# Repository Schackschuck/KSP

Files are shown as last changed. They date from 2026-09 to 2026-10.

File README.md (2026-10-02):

# KSP Cockpit

Controle físico (painel + joystick + telemetria) para o **Kerbal Space Program 1**, feito do zero com hardware e software próprios.

O objetivo principal é **aprender firmware/embarcados e eletrônica**, e de quebra ter um cockpit de verdade — com direito a um botão que dispara um script de pouso autônomo estilo SpaceX.

---

## Arquitetura

```
 PC com Windows: KSP 1 + servidor kRPC
          ▲
          │  rede — cabo ou Wi-Fi (kRPC, TCP/protobuf)
          ▼
 Raspberry Pi 4 = computador de bordo ............... bridge/
   • ponte kRPC ⇄ placas
   • tela multifunção de 7" no HDMI, a mesma página do celular
   • tela multifunção no navegador do celular, pelo Wi-Fi
   • dispara os scripts de voo ....................... scripts/
          ▲
          │ USB/serial
          │ (protocolo próprio)
          ▼
 Arduino Mega = I/O do painel
 firmware/painel/
          ▲
          │  SPI + linhas analógicas
          ▼
 Backplane: 12 slots ................................ hardware/backplane/
          ▲
          │  um cabo flat de 16 vias por módulo
          ▼
 Módulos do painel, um por seção .......... hardware/modulo_pequeno/, _medio/ e _grande/
   pequeno: 8 entradas + 8 LEDs (1 × 74HC165 + 1 × 74HC595)
   médio: 16 entradas + 24 LEDs (2 × 74HC165 + 3 × 74HC595), com 12 jacks de korry
   grande: 24 entradas + 16 LEDs (3 × 74HC165 + 2 × 74HC595)
   korry, botões, LEDs, sidestick, acelerador

 Barras de LEDs dos recursos: um MAX7219, direto no Mega
```

Cada parte tem um papel bem definido:

| Parte | Responsabilidade | Não faz |
|---|---|---|
| **KSP + kRPC** (PC) | Expõe o estado da nave e aceita comandos. | — |
| **Computador de bordo** (Raspberry Pi 4, Python) | Conecta no kRPC pela rede, abre *streams* de telemetria, traduz eventos do painel em comandos do jogo e telemetria em mensagens para o painel. Desenha a tela de telemetria. Dispara os scripts de voo de `scripts/` (ex.: pouso autônomo). | Não lê pino nenhum. |
| **Sidestick** (joystick JH-D400X-R4 no painel, lido pelo Mega) | Manda os 3 eixos e o botão como qualquer controle do painel; a ponte os traduz em comandos do kRPC. | O KSP não enxerga o joystick: tudo passa pela ponte. |
| **Painel** (Arduino Mega, C++) | Lê entradas (com debounce), envia eventos; recebe valores e atualiza LEDs, displays e ponteiros. | **Não sabe que o KSP existe.** É um painel de I/O genérico. |
| **Celular** (opcional, página no navegador) | Mostra a tela multifunção pelo Wi-Fi, com o mesmo protocolo e o mesmo layout, sem precisar da mikromedia. | Não fala com o kRPC nem guarda estado: só desenha o que a ponte manda. |
| **Tela multifunção** (tela de 7" no HDMI do Pi, com a página do navegador) | Desenha as páginas (navball, órbita, pouso, piloto) com o que a ponte manda, e troca de página pelo toque ou pelos botões do painel. | Não fala com o kRPC; só mostra o que o computador de bordo manda. |

Durante o desenvolvimento, o mesmo código Python roda no PC — só muda o endereço do servidor kRPC e a porta serial.

### Princípios

- **O LED mostra o estado do jogo, não a posição da chave.** A chave só avisa para onde foi ("SAS para cima"); o computador de bordo decide o que fazer e o jogo confirma. Assim o painel nunca fica dessincronizado (ex.: SAS desligado pelo jogo).
- **Uma tela só, no meio do painel: a tela multifunção.** Os módulos não têm tela própria. Cada módulo que precisa mostrar números (editor de manobras, piloto automático, rendezvous...) tem uma página na tela multifunção. Quando o piloto mexe num módulo, a ponte troca a tela para a página dele; uns segundos depois do último toque no módulo (uns 10 s, a ajustar), a tela volta sozinha para a página de antes, em geral a navball.
- **Protocolo serial em duas versões:**
  - **v0 — texto**, uma mensagem por linha. Fácil de depurar no Serial Monitor.
    ```
    Pi → placa:  ALT 12345      SAS 1      FUEL 73
    placa → Pi:  BTN STAGE 1    SW SAS 0   AX PITCH -312
    ```
  - **v1 — binário**, com enquadramento [COBS](https://en.wikipedia.org/wiki/Consistent_Overhead_Byte_Stuffing), ID de mensagem e CRC. Mais rápido e robusto; vem quando a v0 começar a apertar. É o mesmo protocolo para o Mega e para a mikromedia.
- **Entradas analógicas** (joystick, acelerador) são enviadas a uma taxa fixa, com zona morta e filtro; **entradas digitais** são enviadas só quando mudam.

### Decisões

| Decisão | Por quê |
|---|---|
| **kRPC** em vez de mods de serial (Kerbal Simpit etc.) | Acesso a praticamente tudo do jogo (órbita, estágios, delta-v, autopilot) e permite scripts de voo. A ferramenta não deve ser o limite. |
| **Ponte fora do microcontrolador** em vez do cliente kRPC C-nano | kRPC completo com *streams*; o firmware fica simples e ganha um protocolo próprio — que é onde está o aprendizado de embarcados. |
| **Python** na ponte | Já usado com kRPC antes; o mesmo código roda no PC e no Pi. |
| **Raspberry Pi 4** como computador de bordo | Deixa o cockpit independente do PC (só um cabo de rede) e pode ligar uma tela colorida grande. A compra dessa tela foi adiada — decidir depois. |
| **Arduino Mega** para o I/O | O Pi não tem entradas analógicas e o Linux não é tempo real; o Mega tem muitos pinos, trabalha em 5V e é compatível com praticamente todo módulo. |
| **Painel em módulos** com 74HC165 e 74HC595, ligados ao Mega por um backplane | Cada seção do painel é uma placa, montada e testada uma de cada vez. Há três tamanhos (8 entradas e 8 LEDs, 16 e 24, ou 24 e 16), para não montar CI à toa. Cada módulo tem uma etiqueta (chave DIP lida por um 74HC165 a mais), e o Mega reconhece sozinho qual módulo está em cada slot. Os CIs custam poucos reais por módulo, o firmware continua um só e o protocolo com a ponte não muda. Um micro em cada módulo fica para a fase 8. |
| Pinos do Raspberry Pi **não** substituem o Mega | O Pi não tem entradas analógicas, o Linux não é tempo real para encoders e ponteiros, e os pinos de 3,3 V vão direto ao processador: um fio errado nos 5 V queima o Pi. |
| **mikromedia for ARM (LPC2148)** como tela multifunção | Já está na bancada. ARM programado sem framework, com tela touch, microSD e áudio. Começa no protocolo em texto, como o simulador, e passa para o v1 junto com o Mega. |
| **Simulador da tela multifunção** no PC antes do firmware | A ponte, o protocolo e o desenho (navball, números, botões) ficam prontos e testados com o jogo antes da placa; o firmware só precisa copiar o simulador. A placa desenha a partir dos ângulos, porque a imagem pronta não cabe na serial (150 KB por quadro). |
| **Firmware da mikromedia compilado com o LLVM** (clang), e não com o `arm-none-eabi-gcc` | Um compilador só, que já gera código para o ARM7, e um `compilar.py` em Python que roda igual no Windows e no Linux, sem `make`. O `mfd.hex` vai compilado no repositório: para gravar, basta o Flash Magic. |
| **Tela da mikromedia desenhada em faixas de 16 linhas** | Não cabe a tela inteira na RAM (150 KB contra 32 KB), e desenhar direto na tela piscaria. Cada faixa de 10 KB fica pronta na RAM e vai inteira para a tela, então cada ponto é escrito uma vez só. |
| **Orientação e touch da mikromedia ajustados na própria tela** e guardados na flash | O manual não diz a orientação do módulo nem a do touch. Ajustando na tela, o que vier trocado se corrige sem compilar de novo. |
| **Celular como tela**, por uma página web | Funciona já, sem firmware e sem o cabo, em qualquer celular e sem instalar nada. A ponte serve a página e fala com ela por HTTP (Server-Sent Events e POST), só com a biblioteca padrão do Python. O protocolo é o mesmo da placa, então a ponte não muda. |
| **pygame-ce** no lugar do pygame | O pygame original não tem pacote para o Python 3.14; o pygame-ce, mantido pela comunidade, tem e é usado do mesmo jeito (`import pygame`). |
| **Pouso por previsão**: simula a freada até o chão e acha o acelerador por bisseção | Com arrasto, a freada não tem conta fechada. Simular funciona igual em qualquer planeta, com ou sem atmosfera, e refazer a conta 20 vezes por segundo corrige os erros da previsão. O arrasto é medido em voo, e a previsão só usa parte dele, porque ele cai quando a nave fica mais lenta que o som. A guiagem não conhece o kRPC, então é testada numa nave simulada. |
| **Pé da nave medido pelas pernas do trem**, não pela caixa da nave inteira | Nas versões lançadas do kRPC (até a 0.6.0), a caixa de uma peça junta tudo o que está pendurado nela, como a chama do motor ligado. A caixa da nave inteira descia metros abaixo do pé, e a freada terminava alta. |
| **SAS do KSP aponta a nave no pouso**, não o piloto automático do kRPC | O piloto automático do kRPC vem ajustado para levar 3 s até o ângulo pedido e não conta a força do ar. No segundo teste, a nave caindo de ré balançou até 31° na freada. O SAS o jogo ajusta para cada nave. Retrógrado enquanto a nave desce rápido; devagar, perto do chão, o retrógrado pula de um lado para o outro, então no fim o SAS só segura a atitude. |
| **Scripts de voo numa pasta própria** (`scripts/`), fora da ponte | Cada script roda sozinho pela linha de comando, no PC ou no Pi, com ou sem o cockpit. A ponte só dispara o script quando o botão do painel é apertado; o script não depende dela nem do painel. |
| **Script liga segurando o korry 5 s**, e aborta segurando de novo 5 s, sem chave ARM | Um toque sem querer não entrega a nave ao script, e o mesmo gesto aborta, sem procurar outro botão. Economiza a chave ARM com capa e um botão por script. Quem conta o tempo é a ponte, como no encoder do piloto automático, e o korry pisca âmbar enquanto conta. |
| **A ponte abre o script num processo próprio** e aborta com o Ctrl+C | O script continua sendo o mesmo da linha de comando, e o Ctrl+C já corta o motor e devolve a nave. O estado volta pelo UDP, como no fly by wire, e o código de saída diz se a nave pousou. |
| **Um joystick só, no painel** (JH-D400X-R4, um sidestick à direita), com o botão do manche trocando o modo | O cockpit fica como um avião: acelerador na mão esquerda, sidestick na direita. Os 3 eixos cabem nas 3 linhas analógicas de um slot do backplane, e o botão passa pelos modos VOO, CÂMERA e TRANSLAÇÃO, com três luzes. Passando pela ponte, dá para ter zona morta e saber quando o piloto mexe no manche para tirar o controle de um script. O Extreme 3D Pro fica para desenvolver no PC. |
| **Uma tela no meio para todos os módulos**, a tela multifunção de 7", no lugar de um LCD por módulo | Os olhos vão sempre ao mesmo lugar, os painéis ficam menores e só com botões, e sai um LCD por módulo da lista de compras. A página troca sozinha para o módulo em uso e volta depois, então não é preciso escolher a página na mão. Quem decide a troca é a ponte, que já recebe todos os eventos do painel: a tela continua só desenhando. |
| **Korry switches** (botões iluminados com legenda, de avião) onde a luz mostra um estado do jogo | O botão não tem posição, então nunca discorda do jogo: cada toque pede a troca, e a legenda acesa é o estado do jogo. Feitos em casa: a legenda impressa em duas cores encaixa num corpo igual para todos, e a chave e os LEDs vão num suporte impresso atrás, sem placa perfurada ([hardware/korry/](hardware/korry/README.md)). O que não tem estado para mostrar é um botão de 16 mm sem luz. |
| **Cockpit em U, de 766 × 391 mm, com painéis de 125 mm** ([versão B](hardware/construcao.md#cockpit-versão-b)) | Um bloco no meio e duas asas, como num avião, sem painel vazio. Os controles foram juntados em 11 painéis para a caixa não passar de 80 cm; o que não cabe em 125 mm ocupa dois quadrados. O que cada botão faz foi conferido no código-fonte do kRPC antes de desenhar. |
| **Tela de 7" no Pi** no lugar da mikromedia | A tela de 2,8" da mikromedia ficou pequena no meio do cockpit. A de 7" mostra a mesma página que o celular já usa, pelo HDMI, sem firmware novo. O firmware da mikromedia continua no repositório, fora do cockpit. |
| **Caixa em MDF cortado a laser, com peças impressas em 3D** | A laser do colégio faz as peças planas e grandes (paredes, painéis com legendas); a impressora de casa, as pequenas e complicadas (korry, knobs, suportes). Cada seção é um painel removível com o seu módulo atrás. |
| **Fly by wire com a lei de um caça**: o manche pede carga (g) e velocidade de rolagem, e não mexe nas superfícies | A primeira versão movia um ponto na navball, e o avião ia até ele: estável, mas lenta e "interventora" no jogo (o voo gravado mostrou o avião respondendo quase 1 s depois e seguindo o ponto depois de o manche ser solto). Pedindo carga e rolagem, o avião responde na hora, e soltar o manche segura o caminho e a inclinação. O piloto automático pede um caminho, e o FBW calcula a carga e a inclinação para chegar nele. |
| **Ganhos do FBW divididos pela autoridade do avião** (torque disponível ÷ inércia, informados pelo kRPC) | A força das superfícies cresce com o quadrado da velocidade: um ganho fixo, bom na decolagem, faz o avião balançar rápido, e cada avião precisaria do seu. Nos testes, o FBW segura o avião com a autoridade informada errada pela metade ou pelo dobro. |
| **Scripts mandam marcadores à ponte da tela por UDP**, com a própria linha do protocolo da tela | O script continua rodando sozinho: sem a ponte aberta, a linha se perde e nada acontece. A ponte só confere e repassa. |
| **Avisos de voo (GPWS) na ponte da tela, falados no Pi** | A ponte já lê o jogo o tempo todo, então avisa em qualquer avião, com ou sem o fly by wire. A voz sai por um alto-falante USB no Pi, pelo `espeak-ng` ou por gravações; o áudio da mikromedia (VS1053) fica para os alarmes da própria tela. |
| **O `fbw.py` lê o joystick sozinho**, por enquanto | A ponte ainda não lê o joystick. Quando ler, a leitura passa para ela, e o script recebe o manche da ponte. |
| **ESP32** fica para depois | Candidato a painel sem fio ou módulo extra (fase 8). |

### Estrutura planejada do repositório

```
bridge/           computador de bordo em Python: ponte kRPC ⇄ serial, tela de telemetria;
                  tela multifunção: ponte (mfd.py), simulador, navball e a página do celular (celular/);
                  painel de sistemas de controle (sistemas.py), com a página de botões (celular/painel.html);
                  painel de scripts (painel_scripts.py): o korry POUSO abre o scripts/pouso.py;
                  avisos de voo por voz, como o GPWS (avisos.py);
                  editor de nós de manobra com botões na página (manobras.py); testes em bridge/tests/
scripts/          scripts de voo (pouso, fly by wire...), que rodam com ou sem o cockpit; testes em scripts/tests/
firmware/painel/  Arduino Mega (Arduino IDE ou PlatformIO)
firmware/passos/  sketches de aprendizado, um por passo da fase 1
firmware/mfd/     mikromedia for ARM / LPC2148 (C, compilado com o LLVM pelo compilar.py), fora do cockpit
hardware/         esquemáticos e PCBs (KiCad), desenhos da caixa; ver hardware/README.md
                  e hardware/construcao.md (o cockpit da versão B, a caixa e os painéis);
                  cada peça própria numa pasta, com ficha e desenhos (hardware/korry/:
                  modelo no OpenSCAD, STL das legendas, das grades e das peças, gerar.py e o desenho da ligação);
                  identidade visual (hardware/identidade_visual.md) e desenhos dos painéis
                  gerados por código (hardware/desenho/, SVG em hardware/img/)
docs/             protocolo serial, pinagem, anotações
```

---

## Roteiro

Cada fase termina com algo funcionando de ponta a ponta. Não pule o critério de "pronto".

### Fase 0 — Ambiente

**Status: concluída.** Passo a passo detalhado e problemas encontrados em [docs/setup-pi.md](docs/setup-pi.md).

**No PC:**

- Instalar KSP 1.12.x e o **kRPC** (via CKAN ou manualmente).
- No jogo, abrir a janela do kRPC e iniciar o servidor (dica: ativar *auto-start* e *auto-accept* nas configurações).
- Nas configurações do servidor, trocar o endereço de `localhost` para **Any** (aceitar conexões da rede), e liberar no firewall do Windows as portas do kRPC (padrão: 50000 e 50001).
- Marcar a rede do Windows como **Privada**; em rede Pública o Windows bloqueia a conexão do Pi.
- Instalar Python 3, `pip install krpc pyserial` e a Arduino IDE 2 (ou PlatformIO no VS Code).
- Se a placa for clone com chip CH340, instalar o driver CH340 no Windows.

**No Raspberry Pi 4:**

- Gravar o Raspberry Pi OS com o Raspberry Pi Imager, já configurando Wi-Fi e SSH.
- `pip install krpc pyserial pygame` (de preferência dentro de um *venv*).

```python
import time
import krpc

# No PC: krpc.connect(name="KSP Cockpit")
# No Pi: informar o IP do PC onde o KSP está rodando
conn = krpc.connect(name="KSP Cockpit", address="192.168.0.10")
vessel = conn.space_center.active_vessel
altitude = conn.add_stream(getattr, vessel.flight(), "mean_altitude")

while True:
    print(f"{altitude():,.0f} m")
    time.sleep(0.1)
```

Versão completa, que recebe o IP como argumento, espera a cena de voo e explica os erros de conexão: [`bridge/fase0_altitude.py`](bridge/fase0_altitude.py).

**Pronto quando:** o script roda **no Pi** e imprime a altitude ao vivo enquanto o foguete sobe no PC.

### Fase 1 — Primeiro circuito fechado

**Status: concluída**, no PC e no Pi. Roteiro passo a passo, montagem e testes: [docs/fase1.md](docs/fase1.md). Protocolo: [docs/protocolo.md](docs/protocolo.md).

- Mega ligado no PC pela USB durante o desenvolvimento; no fim, no Pi.
- 1 botão (STAGE), 1 LED (SAS) e a altitude num LCD 20x4 com módulo I2C.
- Protocolo **v0 (texto)**.
- Aprende: pull-up, debounce, leitura/escrita serial, laço principal sem `delay()`.

**Pronto quando:** apertar o botão faz *stage*, o LED acompanha o SAS do jogo e o LCD mostra a altitude.

### Fase 2 — Painel de controle

**Status: em andamento.** Chaves, botões e LEDs estão prontos para montar: pinagem, código e testes em [docs/fase2.md](docs/fase2.md). O cockpit inteiro está desenhado: a [versão B](hardware/construcao.md#cockpit-versão-b), em U, com 11 painéis de 125 mm, o sidestick e o acelerador no painel.

- Chaves para SAS, RCS, trem de pouso, luzes e freios; STAGE e ABORT com capa de proteção. Depois, action groups.
- **Painel VOO, de sistemas de controle** ([desenho](hardware/construcao.md#painel-de-sistemas-de-controle)): os 10 modos do SAS em korry de duas cores (azul virando, verde segurando), korry SAS, RCS, FBW e TRAVA ALT, e o encoder do [piloto automático](#piloto-automático-de-avião). Numa placa grande com 4 × 74HC595. Apertar um modo do SAS abre a roda dos modos na tela multifunção, só para ver. Trem de pouso, luzes e freios foram para o painel do acelerador.
- A posição da chave é o estado desejado (para cima = ligado); o LED de cada sistema mostra o estado no jogo.
- **Painel em módulos:** cada seção vira uma placa, ligada por cabo flat a um backplane de 12 slots no Mega. A placa pequena tem 8 entradas e 8 LEDs (1 × 74HC165 + 1 × 74HC595); a média, 16 e 24 (2 + 3), com um jack JST-XH para cada korry; a grande, 24 e 32 (3 + 4). Os LEDs só mostram o que vem do jogo: nenhum é ligado a um botão. Cada módulo tem uma etiqueta numa chave DIP, e o Mega descobre sozinho o que está encaixado. Esquemáticos, etiquetas e qual placa vai em cada seção em [hardware/](hardware/README.md).
- Enquanto o primeiro módulo não fica pronto, os controles básicos continuam direto nos pinos do Mega, como em [docs/fase2.md](docs/fase2.md).
- Próximo passo: o firmware do Mega lendo a fila de módulos pelas etiquetas, e testar o primeiro módulo direto no Mega.
- **Sidestick e acelerador no painel:** um joystick JH-D400X-R4 de 3 eixos, com o botão do manche trocando entre VOO, CÂMERA e TRANSLAÇÃO, e uma alavanca deslizante de 60 mm, os dois lidos pelo Mega nas linhas analógicas do backplane ([sidestick](hardware/construcao.md#sidestick), [acelerador](hardware/construcao.md#acelerador)). O Extreme 3D Pro fica para desenvolver no PC; mapeamento em [hardware/construcao.md](hardware/construcao.md#joystick-logitech-extreme-3d-pro).
- **Korry switches:** botões iluminados com legenda, como nos aviões, 35 no cockpit. Legenda impressa em duas cores na FlashForge Inventor, encaixada num corpo igual para todos, com a chave e os LEDs num suporte impresso. As bases de cada grupo saem numa grade impressa, parafusada atrás do painel. O modelo, os STL das 31 legendas, das grades e das peças, o `gerar.py` e a ligação estão em [hardware/korry/](hardware/korry/README.md); o primeiro passo é o teste de folga e um korry ligado direto no Mega.

**A fazer na ponte, para a versão B** (o que cada controle faz e o comando do kRPC estão em [hardware/construcao.md](hardware/construcao.md#os-painéis)):

- [ ] Definir no [protocolo](docs/protocolo.md) as mensagens dos painéis novos: tempo, navegação, action groups e peças, câmera, recursos e EVA, acelerador, sidestick e os botões de página da tela.
- [ ] Tempo: WARP, PARAR, FISICO, ATE O NO, PAUSA, SALVAR, CARREGAR e REVERTER.
- [ ] Navegação: escolher e limpar o alvo pelo encoder, com a página ALVO na tela; REFERENCIA; trocar de nave.
- [ ] Action groups 1 a 8 e os korry das peças (paraquedas, painéis solares, antenas, compartimento de carga), com a luz do estado.
- [ ] Câmera: MAPA, IVA, MODO CAM, FOTO e ESCONDER.
- [ ] Acelerador pela alavanca; TREM, FREIOS e LUZES em korry.
- [ ] Sidestick: os 3 eixos pelo Mega, e o botão trocando o modo, com as luzes.
- [ ] Barras de recursos pelo MAX7219, no firmware do Mega.
- [ ] EVA, quando houver o kRPC 0.7: andar e voar pelo manche, JATO, LUZ, SAIR, EMBARCAR, AGARRAR e SOLTAR.
- [ ] Páginas novas na tela: ORBITA, DELTA-V, SUBIDA, ALVO, TEMPO e EVA.

**Pronto quando:** dá para lançar e colocar um foguete em órbita usando só o painel.

### Fase 3 — Tela de telemetria

- Interface em pygame no Pi: altitude, velocidades, apoapse/periapse, tempo até Ap/Pe, combustível e delta-v por estágio.
- Depois: gráfico de altitude × tempo, desenho simples da órbita, indicador de atitude.
- O Pi 4 tem folga de desempenho, mas vale o bom hábito: redesenhar só o que mudou e limitar a taxa de quadros.
- A tela do cockpit é a de 7" (Waveshare 7" HDMI LCD (C)), no meio do painel. Enquanto ela não chega, desenvolver com qualquer monitor ou TV HDMI (ou rodando a interface no PC).
- A tela multifunção ([docs/mfd.md](docs/mfd.md)) já mostra navball, velocidades, altitude e Ap/Pe numa página web. Uma tela HDMI com touch no Pi pode abri-la em tela cheia, no navegador, sem programar nada novo.

**Pronto quando:** dá para circularizar uma órbita olhando só para a tela.

### Fase 4 — Instrumentos físicos

**Status: editor de manobras escrito, com botões numa página no lugar das chaves; falta testar no jogo.** [`bridge/manobras.py`](bridge/manobras.py) cria e edita os nós pelo kRPC e mostra os números do nó e da órbita (antes e depois) no navegador do PC ou do celular: [docs/manobras.md](docs/manobras.md). A página manda linhas do protocolo pela rede; o painel vai mandar as suas pela serial, com o encoder no lugar dos pares `+`/`-` do Δv. Por enquanto a página também gira a câmera do mapa, **o que tem que sair dela:** no cockpit, a câmera do mapa vai ser mexida pelo joystick, no modo CÂMERA.

**A fazer no editor, para ficar igual ao painel desenhado** ([desenho](hardware/construcao.md#painel-do-editor-de-manobras), [mensagens](docs/protocolo.md#no-painel)):

- [ ] Ponte (`bridge/manobras.py`): guardar o eixo escolhido (PRO, NRM ou RAD), começando pelo PRO em cada nó novo, e trocar de eixo com `BTN PRO`, `BTN NRM` e `BTN RAD`.
- [ ] Ponte: aceitar `ENC DV <cliques>` (horário positivo) e aplicar os cliques × passo no eixo escolhido.
- [ ] Ponte: aceitar `SW PASSO <0 a 3>`, o passo pela posição da chave rotativa, no lugar do `BTN PASSO`.
- [ ] Ponte: mandar ao painel qual eixo está escolhido, para acender o korry certo.
- [ ] Página do celular (`bridge/celular/manobras.html`): trocar os pares `PRO -`/`PRO +`, `NRM -`/`NRM +` e `RAD -`/`RAD +` por três botões de eixo e um par `-`/`+` que faz o papel do encoder, com o eixo escolhido destacado.
- [ ] Testes (`bridge/tests/test_manobras.py`) para o eixo escolhido, o `ENC DV` e o `SW PASSO`.
- [ ] Atualizar [docs/manobras.md](docs/manobras.md) e tirar o "planejado" da seção [No painel](docs/protocolo.md#no-painel) do protocolo.

- Displays de 7 segmentos com MAX7219 para os números mais importantes.
- Encoder rotativo para escolher o que cada display mostra. Lido pela mesma cadeia de 74HC165 dos módulos: o Mega lê a cadeia inteira mil vezes por segundo numa **interrupção de timer**, e assim o redesenho do LCD (~20 ms) não faz perder cliques. O painel acumula os cliques e manda `ENC <nome> <cliques>`.
- **Editor de nós de manobra** (pelo kRPC: `control.add_node`, `node.prograde` etc.):
  - Painel duplo de 250 × 125 mm, desenho e peças em [hardware/construcao.md](hardware/construcao.md#painel-do-editor-de-manobras).
  - **Δv por um encoder só**, porque os três eixos nunca são mexidos ao mesmo tempo. Três korry (PRO, NRM e RAD) escolhem o eixo, e a legenda do escolhido acende na cor da alça do nó no KSP. Girar no sentido horário soma o passo; no anti-horário, tira. Um nó novo já vem com o PRO escolhido. O painel manda `ENC DV <cliques>`, e quem sabe o eixo escolhido é a ponte.
  - **PERCURSO:** uma tecla basculante com mola para o centro, como a do TIME WARP, montada deitada, move o nó ao longo da órbita (para a esquerda, antes; para a direita, depois). Segurando, repete; o painel manda `INC TEMPO <passos>`. Embaixo dela, ANT e PROX trocam de nó.
  - **PASSO:** chave rotativa de 4 posições, com a legenda gravada em volta: 0,1 / 1 / 10 / 100 m/s no Δv e 1 s / 10 s / 1 min / 10 min no tempo.
  - Korry NOVO (nó novo no apoastro), APAGAR e CIRC (circulariza no ponto do nó, com o Δv calculado pela ponte). Sem AP e PE: o tempo já leva o nó a qualquer ponto.
  - São 16 entradas e 3 LEDs (os korry de eixo): cabe numa placa média.
  - **Sem tela no módulo:** Δv, tempo de queima, T− até o nó e o Ap/Pe resultante aparecem numa página do editor na tela multifunção, que abre sozinha quando uma tecla ou botão do editor é usado (ver os [princípios](#princípios)).
  - O botão MAPA (liga e desliga o mapa do jogo) fica na seção da câmera. A câmera do mapa (girar, aproximar, trocar o foco entre nave, nó e planeta) fica no joystick, no modo CÂMERA, não no editor.
- Barras de 10 LEDs com o que resta de combustível, oxidante, monopropelente e eletricidade, acesas por um MAX7219 ([recursos e EVA](hardware/construcao.md#recursos-e-eva)).
- Ponteiro analógico com motor de passo X27.168.
- Fonte 5V externa (a USB não aguenta muitos LEDs).

**Pronto quando:** um voo inteiro (lançamento → órbita → reentrada) é feito sem olhar para o monitor do PC, inclusive planejar a circularização pelo editor de manobras.

### Fase 5 — Protocolo v1 + scripts de voo

**Status: script de pouso escrito, em teste no jogo; o korry POUSO já dispara o script pela página de botões.** No primeiro teste, em Kerbin, a freada terminou alta e a nave tocou o chão inclinada e tombou. Corrigido: o pé agora é medido pelas pernas do trem. No segundo teste o pé ficou certo (0,4 m de erro no toque), mas a nave balançou até 31° na freada: o piloto automático do kRPC não segurava a nave. Agora quem aponta a nave é o SAS do KSP (falta testar de novo). [`scripts/pouso.py`](scripts/pouso.py) faz a queima de suicídio numa descida vertical, em qualquer planeta, contando o arrasto do ar; roda pela linha de comando ou pelo korry POUSO do [painel de scripts](hardware/construcao.md#painel-de-scripts), e a tela multifunção mostra o pouso numa página própria ([docs/mfd.md](docs/mfd.md#painel-de-scripts-e-a-página-do-pouso)). [`scripts/tests/test_pouso.py`](scripts/tests/test_pouso.py) testa a mesma guiagem numa nave simulada, sem o KSP, em planetas com e sem atmosfera.

- Migrar para o protocolo binário (COBS + CRC).
- **Painel de scripts** ([desenho](hardware/construcao.md#painel-de-scripts)): um korry por script, em faixas na ordem do voo (SUBIDA, ORBITA, DESCIDA). Por enquanto só o POUSO; os outros cinco lugares ficam vagos, com a tampa lisa. Segurar o korry 5 s abre o script; segurar de novo 5 s aborta. O korry pisca âmbar enquanto conta, fica verde com o script voando e vermelho se ele foi abortado ou falhou.
- Korry "EXEC" (um lugar vago do painel de scripts) que executa o nó de manobra da fase 4: aponta a nave para o nó, acelera o tempo até perto dele, queima e corta quando o Δv restante chega a zero.
- Painel e tela mostram o estado do script (armando, voando, pousado, abortado). A página POUSO da tela, inspirada na tela do booster da SpaceX, mostra a nave descendo até o alvo, a fase, a altura, a descida, o empuxo/peso e quanto do empuxo a freada precisa. O pouso e o EXEC seguem a [base comum dos scripts](#base-comum).

**A fazer no painel de scripts:**

- [x] Ponte (`bridge/painel_scripts.py`): segurar `BTN POUSO` 5 s abre o `scripts/pouso.py` num processo; segurar de novo aborta; a linha `SCR POUSO` acende o korry.
- [x] `scripts/pouso.py`: estado por UDP (linhas `POU`), código de saída e `--demo` com uma nave simulada.
- [x] Página POUSO no simulador e no celular; korry POUSO na página de botões (`bridge/celular/painel.html`).
- [ ] Testar no jogo: o korry abre o pouso, a página acompanha, e segurar de novo aborta com o motor cortado.
- [ ] Firmware do Mega: o korry POUSO no módulo da ação executiva, mandando `BTN POUSO 1` e `0`, e o LED de duas cores pela linha `SCR POUSO`.
- Os outros scripts (piloto automático de avião, subida até a órbita, pouso de precisão...) estão em [Scripts de voo](#scripts-de-voo) e não entram no critério desta fase.

**Pronto quando:** um booster pousa sozinho a partir de um botão no painel, e um nó de manobra é executado pelo botão EXEC.

### Fase 6 — Tela multifunção (mikromedia for ARM)

**Fora do cockpit:** na [versão B](hardware/construcao.md#tela-multifunção), a tela multifunção é uma tela de 7" no HDMI do Pi, mostrando a página que já existe para o celular. A tela de 2,8" da mikromedia ficou pequena no meio do painel. O firmware e a documentação dela continuam aqui, como o projeto de embarcados que foram.

Placa da MikroElektronika com **NXP LPC2148** (ARM7TDMI-S, 60 MHz, 512 KB de flash, 32 KB de RAM), tela 320x240 com touch resistivo, microSD, saída de áudio e carregador de Li-Po. Aqui o firmware é escrito **sem framework**: C, registradores, script de linker e código de inicialização próprios.

**Status: firmware pronto, falta rodar na placa.** O firmware em `firmware/mfd/` faz na placa o que o simulador faz no PC: navball, números, botões de toque e as páginas SAS, AP e POUSO, no protocolo em texto. Ele compila sem avisos e foi conferido no PC contra o simulador. Gravar e ligar: [docs/mikromedia.md](docs/mikromedia.md). A tela também roda no simulador do PC e no navegador do celular: [docs/mfd.md](docs/mfd.md).

- **Placa:** duas mini-USB. A **USB** vai direto no LPC2148, e a **PROG** tem um conversor USB-serial **FT232RL**, por onde o PC conversa com a placa e o Flash Magic grava o firmware. A tela é um módulo MI0283QT2 (320x240, barramento de 16 bits), com touch resistivo lido pelo ADC. Pinos em [docs/mikromedia.md](docs/mikromedia.md#como-o-firmware-funciona).
- **Ferramentas:** LLVM (clang, ld.lld e llvm-objcopy), chamado pelo `firmware/mfd/compilar.py`; o `mfd.hex` já vem compilado. Gravação pelo bootloader serial de fábrica do LPC2148, pela PROG, com o Flash Magic.
- **Passos:**
  1. [x] Código de inicialização, script de linker, PLL a 60 MHz.
  2. [x] Serial com interrupção e o protocolo da tela ([docs/protocolo.md](docs/protocolo.md#tela-multifunção-mikromedia)), em texto como o simulador; mais tarde o v1.
  3. [x] Driver da tela (HX8347) e desenho em faixas de 16 linhas, porque não cabe um *framebuffer* (320×240×2 = 150 KB contra 32 KB de RAM).
  4. [x] Touch pelo ADC, com a orientação e a calibração escolhidas na própria tela e guardadas na flash.
  5. [x] Páginas: navball, roda do SAS, piloto automático e pouso. Depois: mapa da órbita, informações e uma página para cada módulo do painel que precisa de números (a começar pelo editor de nós de manobra).
  6. [ ] Rodar na placa: confirmar o controlador da tela, o touch e a velocidade.
  7. [ ] Áudio: alarme de estol e avisos gravados no microSD (combustível baixo, contagem de altitude no pouso), pelo VS1053.

**Pronto quando:** a mikromedia mostra telemetria ao vivo recebida do Pi e toca um alarme de combustível baixo.

### Fase 7 — Hardware definitivo

- PCB no **KiCad** a partir dos esquemáticos de [hardware/](hardware/README.md): uma placa de módulo, fabricada em quantidade, e o backplane. Fabricação na JLCPCB, PCBWay… A do módulo médio já está pronta, com os Gerbers ([hardware/](hardware/README.md#pcb-do-módulo-médio)).
- Caixa em MDF cortado a laser (no colégio), com peças impressas em 3D (em casa): um painel removível por seção, legendas gravadas, korry switches, o Pi e a tela de 7" embutidos. Formato, aparência e ordem para construir em [hardware/construcao.md](hardware/construcao.md).

### Fase 8 — Embarcados avançado (opcional)

- Painéis modulares, cada um com seu micro, falando com um mestre via I2C, RS-485 ou CAN.
- Painel sem fio com **ESP32**.
- Reescrever o firmware do Mega sem o framework Arduino (registradores do AVR) ou migrar para RP2040 (Raspberry Pi Pico) com o C SDK ou Rust + Embassy.

---

## Scripts de voo

Scripts que pilotam a nave, ou ajudam o piloto a pilotar, disparados pelo painel e acompanhados na tela. O primeiro é o pouso autônomo da [fase 5](#fase-5--protocolo-v1--scripts-de-voo) ([`scripts/pouso.py`](scripts/pouso.py)); o segundo, o [fly by wire de avião](#fly-by-wire-de-avião) ([`scripts/fbw.py`](scripts/fbw.py)). Os outros desta seção são ideias ainda sem código e sem ordem: cada um entra no roteiro quando o hardware de que precisa existir.

Os scripts ficam em [`scripts/`](scripts/), fora da ponte: cada um roda sozinho pela linha de comando, no PC ou no Pi, mesmo sem o painel. No cockpit, a ponte só dispara o script pelo botão e mostra o estado dele no painel e na tela. Os testes, com naves simuladas e sem o KSP, ficam em `scripts/tests/`.

### Base comum

- **Um script ativo por vez.** No cockpit, liga segurando o korry do script 5 s, e segurar de novo 5 s aborta. ABORT, ou mexer no joystick, também devolve o controle ao piloto na hora (a fazer).
- O painel e a tela mostram o estado do script (armado, ativo, terminado, abortado). Como nos outros LEDs, o LED mostra o que o script está fazendo, não o botão que foi apertado.
- **Guiagem separada do kRPC**, como em `pouso.py`: recebe uma leitura da nave e devolve comandos. Assim ela é testada numa nave simulada, sem o KSP, antes de ir para o jogo.
- **Diretor de voo:** todo script pode rodar no automático ou só como guia. No modo guia, a tela mostra para onde apontar e quanto acelerar, e o piloto voa pelo joystick. Serve para testar a guiagem sem entregar a nave e para aprender a pilotar junto.

### Fly by wire de avião

**Status: script escrito e testado num avião simulado; falta testar no jogo.** Roteiro de testes, ajuste dos ganhos e problemas comuns em [docs/fbw.md](docs/fbw.md).

Como nos caças, o manche não mexe nas superfícies: ele pede o que o avião deve fazer, e o FBW decide as superfícies. [`scripts/fbw.py`](scripts/fbw.py) lê o joystick (o Extreme 3D Pro, ou um controle de Xbox) e pilota o avião pelo kRPC.

- **O manche:** para trás e para a frente pede carga, de −1 g a 4 g; solto, 1 g, e o caminho não curva. Para os lados pede velocidade de rolagem, até 90°/s; solto, a inclinação fica onde parou. A torção soma ao leme. O FBW não trava a altitude sozinho: numa curva, o piloto puxa.
- **Proteções:** com o manche, só a carga até 4 g: puxando tudo devagar, o avião estola. No piloto automático e na trava, ângulo de ataque entre −8° e 15°, asas até 60° e subida entre −30° e +30°.
- **Aviso de estol:** com o ângulo de ataque perto dos 15°, a luz ESTOL do painel pisca e a tela toca um alarme. É só aviso: o FBW não mexe no acelerador, no piloto automático, na trava nem no manche.
- **Nada liga sozinho:** os modos do piloto automático e a trava só ligam pelo painel.
- **Lei direta** no chão e com o botão do FBW desligado: o manche vai direto para as superfícies. O FBW assume 1 s depois da decolagem.
- **Sem joystick** (`--sem-joystick`): decola pelo teclado do jogo, na lei direta, e no ar o piloto automático voa pelo painel.
- **O acelerador fica com o piloto.** O acelerador automático (SPD) já existe por dentro, ainda sem interface.
- **Na tela:** com o piloto automático ou a trava, o caminho pedido aparece na navball da [tela multifunção](docs/mfd.md), como os quatro cantos verdes de um quadrado. Com o avião nele, o pró-grado fica dentro do quadrado.
- **Por dentro, duas camadas:** a carga e a rolagem pedidas viram velocidades de giro; os giros viram superfícies, com proporcional e integral e o ganho dividido pela autoridade do avião.

**Pronto quando:** um avião decola na lei direta e, com o FBW, responde ao manche na hora, sem balançar: puxar dá carga, rolar dá rolagem, e soltar segura o que estava.

**Anotado depois dos primeiros voos no jogo** (a fazer):

- [x] **O FBW está muito instável no jogo.** O voo gravado mostrou o nariz oscilando a 1,5 vez por segundo (ganho de pitch alto para o atraso do kRPC) e um avião lento e "interventor". Refeito com a lei de caça e ganhos menores, testados com a leitura atrasada ([docs/fbw.md](docs/fbw.md)). Falta confirmar no jogo.
- [ ] **Não ligar o FBW sozinho na decolagem.** Hoje ele assume 1 s depois de sair do chão; passa a começar desligado e só liga pelo korry FBW (ou pelo botão do joystick).
- [x] **Tirar a recuperação automática do estol**, que só deu problema no jogo. Saiu tudo: o acelerador no máximo, o piloto automático e a trava desligando, o nariz para baixo, a trava ligando sozinha depois e o limite de ângulo de ataque no manche. Fica só o aviso (luz ESTOL e alarme).
- [x] **Os modos do piloto automático ligavam sozinhos** ao ligar o FBW (o avião tentava subir para uma altitude): era a trava de altitude automática, que saiu. Falta confirmar no jogo.
- [ ] **Avisar o estol também fora do FBW** (na lei direta): a luz ESTOL e o alarme pelo ângulo de ataque, mesmo sem o FBW voando.

### Avisos de voo (GPWS)

**Status: código escrito e testado sem o jogo; falta ouvir no Pi e voar.** Roteiro, limites e como ligar o alto-falante em [docs/avisos.md](docs/avisos.md).

Como o GPWS dos aviões de linha, a ponte da tela fala os avisos em inglês, num alto-falante USB ligado no Pi, em qualquer nave voando na atmosfera:

- **Vermelhos:** `PULL UP` (descendo rápido demais para a altura) e `TERRAIN` (o chão chegando rápido; vira `PULL UP` se continuar).
- **Âmbar:** `SINK RATE`, `DON'T SINK` (perdendo altura depois da decolagem), `TOO LOW, GEAR` e `TOO LOW, TERRAIN` (baixo com o trem recolhido), `BANK ANGLE` e `OVERSPEED`.
- **Chamadas de altura** no pouso: 100, 50, 40, 30, 20 e 10 pés.
- **Luz** GPWS (âmbar) / PULL UP (vermelha) no painel de sistemas; por enquanto, na página de botões.

- [x] `bridge/avisos.py`: os avisos, a prioridade e a voz (`espeak-ng` ou gravações em `bridge/sons/`); `--voz`, `--sem-voz` e `--testar-voz` no `mfd.py`; testes.
- [x] Luz GPWS / PULL UP na página de botões.
- [ ] Ouvir no Pi com o alto-falante USB e ajustar os limites no jogo.
- [ ] Luz GPWS no desenho do painel de sistemas.
- [ ] Olhar o terreno à frente (EGPWS), pela altura do terreno do kRPC.

### Piloto automático de avião

**Status: código escrito e testado com o avião simulado e a demonstração; falta testar no jogo.** O `fbw.py` voa HDG, ALT e V/S pedindo um caminho ao FBW ([docs/fbw.md](docs/fbw.md#piloto-automático)), e o painel de sistemas é, por enquanto, uma página de botões aberta pela ponte da tela ([docs/mfd.md](docs/mfd.md#painel-de-sistemas-de-controle)), com a roda do SAS e a página do piloto na tela.

- [x] Página de botões no celular, no lugar do painel, como a do editor de manobras.
- [x] Ponte da tela (`bridge/mfd.py` e `bridge/sistemas.py`): modos do SAS, SAS e RCS no jogo; azul ou verde pelo erro até o marcador; o menu do piloto; as páginas do SAS e do piloto, com a volta à navball.
- [x] Tela do celular e simulador: a roda dos modos do SAS e a página do piloto.
- [x] `scripts/fbw.py`: HDG, ALT e V/S pedindo um caminho; FBW e TRAVA pelo painel; estado e comandos por UDP com a ponte da tela; testes no avião simulado.
- [ ] Testar no jogo: os modos do SAS e as luzes ([roteiro](docs/mfd.md#testar-o-painel-sem-o-ksp)), e o piloto automático num avião ([roteiro](docs/fbw.md#piloto-automático)).
- [ ] **Tela: tirar os botões redondos SAS e RCS da navball.** Eles ficam só no painel.
- [ ] **Tela: as páginas que abrem sozinhas** (a roda do SAS, a do piloto e as outras que aparecem por cima da navball) **ficam 6 s** depois do último toque, em vez de 10 s.
- [ ] O painel de verdade: as mesmas linhas pela serial do Mega, e as pontes do painel e da tela juntas.

Inspirado no painel de piloto automático dos aviões de linha (o MCP do Boeing, o FCU do Airbus).

- **Modos:**
  - **HDG:** vira para o rumo escolhido e segura.
  - **ALT:** sobe ou desce até a altitude escolhida e segura. Enquanto não chega, fica **armado** (azul na tela); ao chegar, nivela e fica verde.
  - **V/S:** sobe ou desce com a velocidade vertical escolhida. Com o ALT ligado junto, nivela ao chegar na altitude escolhida.
  - **SPD:** acelerador automático, segura a velocidade escolhida. Fica para depois, como mais uma linha do menu.
  - Sem HDG ligado, a rolagem fica com o manche, e a inclinação fica onde o piloto deixou.
- **No painel de [sistemas de controle](hardware/construcao.md#painel-de-sistemas-de-controle)**, junto do SAS, do RCS e do FBW:
  - **Um encoder só**, mexido pelo menu da página do piloto na tela multifunção: girar move o cursor entre HDG, ALT e V/S; apertar escolhe a linha, e girar muda o valor (horário soma); apertar de novo sai; segurar 1 s liga ou desliga o modo da linha. Girando devagar, o valor muda de 1 em 1 (1°, 10 m, 0,1 m/s); rápido, de 10 em 10.
  - **Uma luz verde por modo**, ao lado do encoder, acesa quando o modo está ligado no FBW. Sem displays de 7 segmentos: os valores ficam na tela.
  - Korry **FBW** (liga e desliga o FBW, como o botão do joystick) e **TRAVA ALT** (trava e destrava a altitude do momento).
- **Na tela:** a página do piloto, com os modos (azul armado, verde ligado) e os valores escolhidos, abre sozinha quando o encoder é mexido e volta para a navball uns 10 s depois. O caminho pedido aparece na navball: é o ponto verde do FBW.
- **Por dentro:** o piloto automático fica por cima do [fly by wire](#fly-by-wire-de-avião) e pede um caminho, como um piloto que não cansa:
  - HDG pede o rumo escolhido, que vira inclinação das asas; sem HDG, a rolagem fica com o manche;
  - ALT, V/S e a TRAVA ALT pedem o ângulo de subida, que vira carga; sem eles, o pitch fica com o manche;
  - SPD liga o acelerador automático que já existe no `fbw.py`;
  - as proteções do FBW continuam valendo, e mexer no manche devolve o eixo ao piloto.
- **Precisa de:** o encoder e as luzes do painel de sistemas. Para começar, uma página de botões no celular faz o papel do painel.

**Pronto quando:** um avião decola na mão, e o piloto automático leva ele até a altitude e o rumo escolhidos no painel e segura lá.

### Rover com controle de cruzeiro

- Os mesmos botões e encoders HDG e SPD do avião, e o mesmo PID: segura a velocidade e o rumo no chão, pelo acelerador e pela direção das rodas (`control.wheel_throttle` e `control.wheel_steering`).
- Freia nas descidas, para não passar da velocidade escolhida.
- Sai quase de graça depois do piloto automático de avião.

### Subida até a órbita

- O piloto escolhe a altitude da órbita e a inclinação nos encoders e segura o korry LANCAR (vago no painel de scripts) 5 s.
- O script decola, faz a curva de gravidade, solta os estágios quando o combustível acaba e corta o motor quando o apoastro chega na altitude escolhida.
- No apoastro, circulariza com um nó de manobra executado pelo EXEC da fase 5.
- Junto com o pouso, fecha o ciclo: do chão até a órbita e de volta.

### Pouso de precisão (volta à base)

O pouso da SpaceX completo. O `pouso.py` desce na vertical onde a nave estiver; aqui o booster volta para um lugar escolhido, como a plataforma do KSC.

- **Queima de retorno** logo depois da separação: vira a nave e queima até a trajetória cair no alvo.
- **Queima de reentrada**, para chegar mais devagar nas camadas grossas da atmosfera.
- Na descida, as aletas corrigem a trajetória para o alvo.
- Termina com a queima de suicídio do `pouso.py`, com a mira puxando para o alvo em vez de só anular a deriva.
- É o mais difícil da lista: precisa prever onde a trajetória cai, com arrasto, como o `pouso.py` já faz na vertical.

### Rendezvous

Levar a nave até perto de outra em órbita. O script **não pilota até a última etapa**: ele cria nós de manobra, que o piloto confere e ajusta no editor da [fase 4](#fase-4--instrumentos-físicos) e o EXEC da fase 5 executa. Assim a parte de planejar e a parte de queimar ficam separadas, e cada uma é testada sozinha.

- **As etapas**, cada uma um nó novo:
  1. **Igualar o plano:** nó no nodo ascendente ou descendente em relação ao alvo, queima na direção normal de Δv = 2·v·sen(Δi/2). Conta fechada; o kRPC dá a inclinação relativa e onde fica o nodo (`relative_inclination`, `true_anomaly_at_an`).
  2. **Transferência:** a conta pesada, feita como no pouso, prevendo e ajustando. Para cada momento de queima ao longo de uma volta, calcula a queima pró-grado que leva o apoastro até a órbita do alvo, prevê as duas órbitas e mede a menor distância entre as naves. Fica com o melhor momento e refina por bisseção. Sem motor, as órbitas seguem as leis de Kepler: a previsão é exata, sem o arrasto que complica o pouso.
  3. **Igualar a velocidade:** nó no momento da menor distância, com a queima igual à diferença entre a velocidade do alvo e a da nave nesse instante.
  4. **Aproximação final**, sem nó: aponta para o alvo, se aproxima com uma velocidade que cai com a distância, anula a deriva para os lados e para a uns 50–100 m. Dali segue o acoplamento assistido.
- **Automático ou diretor de voo:** no automático, o script encadeia as etapas e acelera o tempo entre elas (`warp_to`). Como diretor de voo, ele só propõe cada nó e o piloto ajusta e executa.
- **Na página do editor de manobras, na tela multifunção:** a menor distância prevista até o alvo, quando ela acontece e a velocidade relativa nesse ponto, atualizadas enquanto o encoder e o TEMPO mexem no nó.
- **Ordem para fazer**, do mais simples ao mais difícil:
  1. Só mostrar a menor distância prevista enquanto o piloto edita os nós na mão. Sem automação, e já é como se faz rendezvous "de olho" no KSP.
  2. Os nós de igualar o plano e igualar a velocidade, que são contas fechadas.
  3. A busca da transferência.
  4. A aproximação final e a passagem para o acoplamento.
- **A decidir:**
  - Quem prevê as órbitas: o kRPC calcula a aproximação com um nó criado, mas cada pergunta vai pela rede, e a busca faz dezenas delas. Uma previsão própria (resolver a equação de Kepler, umas 30 linhas) é rápida e testável sem o KSP. A ideia é a própria, conferida contra a do kRPC.
  - Queimas longas: o EXEC tem que começar metade da queima antes do nó, senão o encontro erra por quilômetros. Vale para todo nó, então fica no EXEC.
- **Precisa de:** o editor de manobras (fase 4) e o EXEC (fase 5). A etapa 1 da ordem só precisa da tela.

### Acoplamento assistido

- Página nova na tela multifunção: a mira de alinhamento com a porta de acoplamento do alvo, a distância e a velocidade de aproximação.
- O sidestick no modo TRANSLAÇÃO, escolhido pelo botão do manche: o manche move a nave com o RCS, sem girar ([os três modos](hardware/construcao.md#um-joystick-três-modos)).
- Primeiro manual, com a tela ajudando. Depois automático: a nave se alinha e se aproxima devagar sozinha.
- **Precisa de:** joystick (fase 2) e a tela multifunção.

---

## Lista de compras

Itens marcados já estão na bancada. Compre por fase — não precisa tudo de uma vez. AliExpress costuma ser mais barato (e lento); Mercado Livre e lojas nacionais chegam mais rápido.

> **Atenção à tensão:** o Mega trabalha em 5V; o Pi, em 3,3V. Nunca ligue um pino do Pi direto em 5V — a comunicação entre os dois é pela USB.

### Ferramentas (uma vez só)

- [ ] Ferro de solda com controle de temperatura + estanho + malha dessoldadora
- [ ] Multímetro
- [ ] Alicate de corte e decapador de fios
- [x] Impressora 3D (em casa)
- Corte a laser: no colégio
- [ ] Paquímetro (para medir as peças antes de desenhar os furos dos painéis)

### Fases 0–1 — Kit inicial

- [x] Arduino Mega 2560 (também tem Uno e Nano)
- [x] Raspberry Pi 4
- [x] Botões
- [ ] Fonte para o Pi 4: 5,1V 3A USB-C de boa qualidade (fonte fraca causa travamentos)
- [ ] Dissipador ou case com ventoinha (o Pi 4 esquenta, principalmente dentro de uma caixa fechada)
- [x] Cartão microSD de 16 GB ou mais (classe A1)
- [x] Cabo USB-B para ligar o Mega no Pi
- [x] 2× protoboard de 830 pontos
- [x] Jumpers macho-macho e macho-fêmea
- [x] Kit de LEDs 5 mm + kit de resistores (220 Ω–10 kΩ)
- [x] LCD 16x2 ou 20x4 com módulo I2C (só para a fase 1; opcional se já tiver)

### Fase 2 — Painel de controle

- [x] 10–15× chaves alavanca (toggle) ON-OFF
- [x] 2–3× capas de proteção para chave ("missile switch cover")
- [x] 4–6× botões arcade (24 ou 30 mm), de preferência com LED
- [ ] Por módulo pequeno (5 no painel): 2× 74HC165, 1× 74HC595, 2× rede resistiva 10 kΩ SIP 9 pinos, 1× chave DIP de 8 vias, 8× resistor 1 kΩ, 3× capacitor 100 nF, 1× capacitor 10 µF, 3 soquetes DIP-16, conector IDC 2x8 e cabo flat de 16 vias
- [ ] Por módulo médio (5 no painel): 3× 74HC165, 3× 74HC595, 3× rede resistiva 10 kΩ SIP 9 pinos, 1× chave DIP de 8 vias, 24× resistor 220 Ω, 6× capacitor 100 nF, 1× capacitor 470 µF, 12× conector JST-XH de 4 vias, 6 soquetes DIP-16, conector IDC 2x8 e cabo flat de 16 vias
- [ ] Por módulo grande (1 no painel, o VOO): 4× 74HC165, 4× 74HC595, 4× rede resistiva 10 kΩ SIP 9 pinos, 1× chave DIP de 8 vias, 32× resistor 1 kΩ, 8× capacitor 100 nF, 1× capacitor 10 µF, 8 soquetes DIP-16, conector IDC 2x8 e cabo flat de 16 vias
- [ ] Backplane: 12× conector IDC 2x8, 5× resistor 47 Ω, 13× resistor 10 kΩ, capacitores de 470 µF e 100 nF, borne de 2 vias e jumper de 3 pinos
- [x] Joystick: Logitech Extreme 3D Pro (para desenvolver no PC)
- [ ] Sidestick: 1× joystick JH-D400X-R4, 10 kΩ, 3 eixos com botão
- [ ] Acelerador: 1× potenciômetro deslizante Bourns PTA6043, 10 kΩ linear, curso de 60 mm
- [ ] 35 korry switches ([lista completa](hardware/korry/README.md#lista-de-peças-um-korry)), cada um com 1 chave PSW 8,5 × 8,5 mm sem trava, até 2 LEDs difusos de alto brilho de 3 mm, 4 fios finos e 1 conector JST-XH fêmea de 4 vias com os terminais; filamento PLA preto e transparente
- [ ] 10× LED azul e verde de 3 mm, difuso, catodo comum (korry dos modos do SAS)
- [ ] 17× parafuso M3 autoatarraxante de 8 mm, para as 9 grades dos korry ([fixação no painel](hardware/korry/README.md#fixação-no-painel))
- [ ] 34× botão de 16 mm sem trava, com anel de 20 mm (R16-503 ou R13-507), e 2 capas impressas para o CARREGAR e o REVERTER
- [ ] 2× botão de metal de 22 mm com anel de LED (vermelho e branco), de 5 V ou 3 V, e 2× capa transparente para botão de 22 mm
- [ ] 2× tecla KCD1 (ON)-OFF-(ON) de 21 × 15 mm
- [ ] 5× barra de 10 LEDs verde (Kingbright DC-10GWA) e 1× MAX7219, para os recursos e a EVA
- [ ] 7× LED de 5 mm difuso (3 verdes e 1 vermelho do piloto, 3 brancos do sidestick)
- [x] 7× suporte de plástico com porca para LED de 5 mm
- [ ] Placas perfuradas de dupla face + barras de pinos (headers) e fio fino encapado (wire-wrap)

### Fase 3 — Tela de telemetria

- [ ] Tela Waveshare 7" HDMI LCD (C), 1024 × 600, com toque capacitivo: a tela multifunção do cockpit
- [ ] Cabo ou adaptador **micro-HDMI → HDMI** (o Pi 4 só tem saída micro-HDMI)

### Fase 4 — Instrumentos físicos

- [ ] 3–4× módulos MAX7219 com 8 dígitos de 7 segmentos (o piloto automático não usa mais: os valores vão para a tela)
- [ ] 2× encoders rotativos (KY-040), para escolher o que os displays mostram
- [ ] Editor de manobras ([peças e medidas](hardware/construcao.md#painel-do-editor-de-manobras)): 1× encoder EC11 com knob de alumínio de 30 mm; 1× chave rotativa de 1 polo e 12 posições, com anel de batente, e knob de ponteiro de 22 mm (a tecla, os botões e os korry estão na fase 2)
- [ ] Navegação: 1× encoder EC11 com botão e knob de alumínio de 30 mm; 1× chave rotativa de 1 polo e 12 posições, com anel de batente, e knob de ponteiro de 22 mm
- [ ] VOO, de sistemas de controle ([peças e medidas](hardware/construcao.md#painel-de-sistemas-de-controle)): 1× encoder EC11 com botão e knob de alumínio de 30 mm (os korry e os LEDs estão na fase 2); 1 módulo grande
- [ ] 2–4× motores de passo X27.168 (ponteiros)
- [ ] 1× fonte 5V 3A + conector/borne

### Fase 6 — Tela multifunção

- [x] mikromedia for ARM (LPC2148)
- [x] Cabo mini-USB **com fios de dados**, para a PROG (o antigo alimenta a placa, mas o Windows não reconhece o FT232)
- [ ] Cartão microSD (para os sons de alarme)
- [ ] Fone ou caixinha de som com plugue P2
- [ ] Alto-falante USB para o Pi (a voz dos [avisos de voo](docs/avisos.md))
- [ ] Gravador JTAG compatível com ARM7 (opcional, só para depurar passo a passo)

### Fase 7 — Hardware definitivo

- [ ] PCBs fabricadas
- [ ] Conectores JST/dupont, parafusos e espaçadores M3
- [ ] Material da caixa: MDF 3 mm e acrílico 3 mm (preto ou branco leitoso) para a laser, filamento PLA, primer e tinta spray fosca
- [ ] Insertos roscados M3 (colocados a quente nas peças impressas) e pés de borracha
- [ ] Extensão USB de painel (para o joystick) e ventoinha 5 V de 40 mm (para o Pi dentro da caixa)

---

## Referências

- [kRPC — repositório](https://github.com/krpc/krpc) e [documentação](https://krpc.github.io/krpc/)
- [pySerial](https://pyserial.readthedocs.io/)
- [pygame](https://www.pygame.org/docs/)
- [Raspberry Pi — documentação](https://www.raspberrypi.com/documentation/)
- [Arduino — documentação](https://docs.arduino.cc/)
- [KiCad](https://www.kicad.org/)
- [LPC214x User Manual (UM10139)](https://www.nxp.com/docs/en/user-guide/UM10139.pdf) — referência de todos os registradores do LPC2148
- [LLVM](https://llvm.org/) (clang e ld.lld), que compila o firmware da mikromedia
- [Flash Magic](https://www.flashmagictool.com/) — gravação pelo bootloader serial do LPC2148
- Manual e esquemático da mikromedia for ARM (MIKROE-780): site da [MikroElektronika](https://www.mikroe.com/)
- Bibliotecas úteis para o firmware: `LiquidCrystal_I2C`, `LedControl` (MAX7219), `FastLED` ou `Adafruit_NeoPixel` (WS2812), `SwitecX25` (X27.168)

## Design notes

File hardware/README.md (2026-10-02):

# Hardware

Esquemáticos do painel, feitos no KiCad. Cada pasta tem também um PDF do esquema, que dá para ver sem instalar nada.

| Pasta | Placa | CIs |
|---|---|---|
| [`modulo_pequeno/`](modulo_pequeno/) | Módulo pequeno: 8 entradas e 8 LEDs ([PDF](modulo_pequeno/modulo_pequeno.pdf)) | etiqueta + 1 × 74HC165, 1 × 74HC595 |
| [`modulo_medio/`](modulo_medio/) | Módulo médio: 16 entradas e 24 LEDs, com 12 jacks de korry ([PDF](modulo_medio/modulo_medio.pdf), [PCB](#pcb-do-módulo-médio)) | etiqueta + 2 × 74HC165, 3 × 74HC595 |
| [`modulo_grande/`](modulo_grande/) | Módulo grande: 24 entradas e 32 LEDs ([PDF](modulo_grande/modulo_grande.pdf)) | etiqueta + 3 × 74HC165, 4 × 74HC595 (o esquema ainda tem 2: ver [Próximos passos](#próximos-passos)) |
| [`backplane/`](backplane/) | Backplane: liga até 12 módulos ao Mega ([PDF](backplane/backplane.pdf)) | — |

A parte física (carcaça, aparência, os painéis da versão B e o sidestick) está em [construcao.md](construcao.md). Peças feitas em casa e usadas em vários painéis têm pasta própria, com a ficha e os desenhos: [`korry/`](korry/README.md). A [identidade visual](identidade_visual.md) diz como todo painel tem que parecer, e os desenhos dos painéis são gerados por código em [`desenho/`](desenho/README.md).

As três placas de módulo usam o mesmo cabo flat e encaixam em qualquer slot. Cada uma tem uma **etiqueta**, um 74HC165 a mais ligado a uma chave DIP de 8 vias: é por ela que o Mega descobre sozinho qual módulo está em cada slot.

## Como abrir

1. Instale o KiCad 7 ou mais novo e abra o `.kicad_pro` de cada pasta.
2. Os arquivos estão no formato do KiCad 7. Uma versão mais nova avisa que vai converter o arquivo ao salvar: pode aceitar.
3. Os símbolos estão embutidos no esquema. As footprints já estão escolhidas (DIP-16 com soquete, IDC 2x8, chave DIP, barras de pinos). O módulo médio já tem a PCB pronta para fabricar ([abaixo](#pcb-do-módulo-médio)); as outras placas ficam para a fase 7.
4. Ao abrir, rode o verificador de regras elétricas: menu **Inspecionar → Verificador de Regras Elétricas (ERC)**.

## Como tudo se liga

```
Mega ──(7 fios)── Backplane ── slot 1 ──(cabo flat)── módulo
                            ├─ slot 2 ──(cabo flat)── módulo
                            └─ ... até o slot 12
```

- **O Mega nunca liga direto nos módulos,** só no backplane: 5 sinais, +5V e GND.
- **Os pinos do Mega não aumentam com o número de módulos.** Os sinais seguem de módulo em módulo, numa fila.
- **As entradas de todos os módulos formam uma única cadeia de 74HC165,** que termina no MISO do Mega.
- **As saídas formam uma única cadeia de 74HC595,** que começa no MOSI.
- **Só os módulos com joystick ou acelerador** precisam de mais fios até o Mega: 3 analógicos por slot.

### Cabo flat (IDC 2x8, igual no módulo e no slot)

| Pino | Sinal | Pino | Sinal |
|---|---|---|---|
| 1 | +5V | 2 | GND |
| 3 | SCK | 4 | GND |
| 5 | PL (carrega as entradas) | 6 | RCLK (atualiza os LEDs) |
| 7 | SIN165 (vem do slot seguinte) | 8 | SOUT165 (vai para o Mega) |
| 9 | SIN595 (vem do Mega) | 10 | SOUT595 (vai para o slot seguinte) |
| 11 | AN_A | 12 | GND |
| 13 | AN_B | 14 | AN_C |
| 15 | +5V | 16 | GND |

### Ligação ao Mega

| Sinal | Pino do Mega | Observação |
|---|---|---|
| SCK | D52 | SPI |
| MOSI | D51 | Entra na cadeia de 74HC595 |
| MISO | D50 | Sai da cadeia de 74HC165 |
| PL | D49 | |
| RCLK | D48 | |
| Analógicos dos slots 1 a 5 | A0 a A14 | Slot k: A(3k−3), A(3k−2), A(3k−1) |
| 5V | 5V | Só com JP1 em 1-2 |
| GND | GND | Sempre ligado, mesmo com fonte externa |

Não use o D53 (SS) como entrada: se ele for a 0, o SPI do Mega sai do modo mestre. O `SPI.begin()` já o deixa como saída.

### Regras do backplane

1. **Módulos em slots seguidos,** a partir do slot 1, sem buracos. O Mega para de ler no primeiro slot vazio.
2. **A ordem dos módulos não importa:** cada um se identifica pela etiqueta.
3. **Módulos com joystick ou acelerador vão nos slots 1 a 5,** os únicos com linhas analógicas.
4. **JP1 escolhe de onde vem o +5V dos módulos:**
   - **1-2:** 5 V do Mega. Serve para poucos módulos, com o Mega alimentado pela USB.
   - **2-3:** fonte externa de 5 V no borne J3. É para o painel completo.
   - Use um jumper só: ele liga 1-2 ou 2-3, nunca as duas fontes juntas.
5. **Encaixe e tire módulos com o painel desligado.** O conector do cabo flat não garante que o GND encosta antes dos sinais. Ao ligar, o Mega reconhece sozinho o que estiver encaixado.

## Primeiro teste: um módulo direto no Mega

Dá para testar um módulo antes de montar o backplane, ligando o conector J1 do módulo direto no Mega com 8 jumpers:

| J1 do módulo | Mega |
|---|---|
| 1 (+5V) | 5V |
| 2 (GND) | GND |
| 3 (SCK) | D52 |
| 5 (PL) | D49 |
| 6 (RCLK) | D48 |
| 8 (SOUT165) | D50 (MISO) |
| 9 (SIN595) | D51 (MOSI) |
| 7 (SIN165) | GND: marca o fim da fila, como faria um slot vazio |

Os pinos 4, 12 e 16 são GND repetidos, e 15 é +5V repetido: com um cabo curto não precisam de fio. O 10 (SOUT595) fica solto. Os analógicos (11, 13 e 14) vão em A0, A1 e A2, se o módulo tiver joystick.

## Etiqueta: como o Mega reconhece cada módulo

A etiqueta é o primeiro byte que o Mega lê de cada módulo.

**O byte da etiqueta:**
- Cada chave DIP ligada (ON) põe o bit correspondente em 1. A chave k é o bit k−1.
- O Mega inverte o byte lido, porque a chave liga a entrada ao GND.
- **Bits 7 e 6 = tamanho da placa:** 01 pequena, 10 média, 11 grande. É por eles que o Mega sabe quantos bytes vêm depois.
- **Bits 5 a 0 = número da seção:** de 1 a 62, e diz qual módulo é.

**Valores reservados:**
- **Tudo ligado (byte 0xFF depois de inverter):** é o que o Mega lê num slot vazio, graças aos pull-downs do backplane. Quer dizer "acabou a fila".
- **Tudo desligado (0x00):** etiqueta esquecida; o Mega avisa em vez de adivinhar.

**Como o Mega lê a fila:**
1. Lê a etiqueta do slot 1.
2. Pelo tamanho, sabe quantos bytes de entrada pular: 1, 2 ou 3.
3. Lê a etiqueta do slot 2, e assim por diante, até achar a marca de fim.

Assim, não existe tabela de slots no firmware. O Mega avisa a ponte qual módulo está em cada slot, e a ponte sabe o que cada entrada e cada LED daquele módulo faz no jogo.

### Qual placa e qual etiqueta em cada seção

| Seção do painel | Entradas | LEDs | Placa | Número | Chaves DIP em ON |
|---|---|---|---|---|---|
| [Ação executiva](construcao.md#ação-executiva) (STAGE, ABORT e os 6 scripts) | 8 | 14 | média | 1 | 1, 8 |
| [Tempo](construcao.md#tempo) | 9 | 1 | média | 2 | 2, 8 |
| [Sidestick](construcao.md#sidestick) (3 eixos analógicos) | 1 | 3 | pequena, slots 1 a 5 | 3 | 1, 2, 7 |
| [Tela multifunção](construcao.md#tela-multifunção) (páginas e SILENCIAR) | 5 | 0 | pequena | 4 | 3, 7 |
| [Acelerador](construcao.md#acelerador) (alavanca analógica, trem, freios e luzes) | 3 | 3 | pequena, slots 1 a 5 | 5 | 1, 3, 7 |
| [Recursos e EVA](construcao.md#recursos-e-eva) | 6 | 2 | pequena | 6 | 2, 3, 7 |
| [Voo](construcao.md#painel-de-sistemas-de-controle) (sistemas de controle: SAS, RCS, FBW e piloto automático) | 17 | 31 | grande | 7 | 1, 2, 3, 7, 8 |
| [Action groups](construcao.md#action-groups) (1 a 8 e as peças) | 12 | 4 | média | 8 | 4, 8 |
| [Câmera](construcao.md#câmera) | 5 | 2 | pequena | 9 | 1, 4, 7 |
| [Navegação](construcao.md#navegação) | 10 | 0 | média | 10 | 2, 4, 8 |
| [Editor de manobras](construcao.md#painel-do-editor-de-manobras) | 16 | 3 | média | 12 | 3, 4, 8 |

São 11 módulos da [versão B do cockpit](construcao.md#cockpit-versão-b): 5 pequenos, 5 médios e 1 grande, e sobra 1 slot. O sidestick e o acelerador vão nos slots 1 a 5, os únicos com linhas analógicas: o sidestick usa as três (X, Y e torção), o acelerador uma. As 4 barras de recursos e a da EVA (50 LEDs) não passam pelo backplane: um MAX7219 ligado direto em 3 pinos do Mega acende todas. As seções da mesma placa podem ficar longe uma da outra no painel: os fios dos botões até a placa podem ter uns 30 cm.

Os números 3, 4, 6, 9 e 11 mudaram de seção com a versão B: antes eram os analógicos de rotação e translação, a telemetria, a EVA e a câmera. O firmware ainda não lê as etiquetas, então nada no código muda.

## No módulo

| O que liga | Pequeno | Médio | Grande | Como |
|---|---|---|---|---|
| Etiqueta | SW1 | SW1 | SW1 | Chave DIP de 8 vias, conforme a tabela acima. |
| Botões e chaves | J2 (IN0–IN7) | K1–K12 (IN0–IN11) e J2 (IN12–IN15) | J2, J3, J4 (IN0–IN23) | Entre o INn e o GND do próprio conector. Apertado ou ligado lê **0** (pull-up de 10 kΩ). |
| LEDs | J3 (LED0–LED7) | K1–K12 (LED0–LED23) | J5, J6 (LED0–LED15) e, quando o esquema tiver os 4 × 74HC595, mais dois conectores (LED16–LED31) | Anodo no LEDn, catodo no GND. O resistor já está na placa. Na pequena e na grande é de 1 kΩ: uns 3 mA por LED, e os 8 LEDs de um 74HC595 ficam abaixo de 70 mA. Na média é de 220 Ω, que acende mais forte: uns 13 mA por LED, e os 8 de um 74HC595 acesos juntos passam dos 70 mA do CI. |
| Joystick ou acelerador | J4 | J6 | J7 | Pontas do potenciômetro em +5V e GND, cursor em AN_A, AN_B ou AN_C. |

**Os LEDs mostram o estado do jogo.** Nenhum LED é ligado a um botão: o Mega acende cada LED com o que a ponte manda do kRPC. Até o LED de um botão iluminado vai numa saída LEDn, separado do contato do botão.

**Botão com LED de 5 V** (como os botões arcade) já tem resistor interno. Com o resistor da placa em série, ele fica mais fraco. Se ficar fraco demais, troque o resistor daquela saída por um de menor valor, ou por um fio.

## Ordem dos bytes (para o firmware)

| Placa | Bytes de entrada, na ordem de leitura | Bytes de saída |
|---|---|---|
| Pequena | 2: U1 (etiqueta), U2 (IN0–IN7) | 1: U3 (LED0–LED7) |
| Média | 3: U1 (etiqueta), U2 (IN0–IN7), U3 (IN8–IN15) | 3: U4 (LED0–LED7), U5 (LED8–LED15), U6 (LED16–LED23) |
| Grande | 4: U1 (etiqueta), U2 (IN0–IN7), U3 (IN8–IN15), U4 (IN16–IN23) | 4: U5 (LED0–LED7), U6 (LED8–LED15), U7 (LED16–LED23), U8 (LED24–LED31) |

**Entradas:**
1. Um pulso baixo em PL copia todas as entradas, e as etiquetas, para os 74HC165.
2. Em seguida, o SPI lê os bytes a começar pelo slot 1. Em cada byte de entrada, o bit n é o INn do respectivo CI.

**Saídas:**
1. O SPI envia os bytes de saída **do último slot para o primeiro**, e em cada slot do último CI para o primeiro. O último byte enviado fica no primeiro 74HC595 do slot 1.
2. Um pulso em RCLK acende o que foi enviado.

**Uma varredura em uma transferência só:**
- Como as duas cadeias compartilham o SCK, dá para ler e escrever junto.
- Cada placa tem pelo menos tantos bytes de entrada quanto de saída. Então, depois de conhecer os módulos na partida, basta transferir o total de bytes de entrada, com os bytes de saída no fim.
- Com as 12 placas da tabela, são 31 bytes: uns 125 µs a 2 MHz.
- Feito mil vezes por segundo numa interrupção de timer, dá tempo de ler até os encoders.
- Um byte a mais no fim confere a marca de fim da fila.

## Lista de peças por placa

**Módulo pequeno:**
- U1 (etiqueta) e U2: 74HC165.
- U3: 74HC595.
- RN1–RN2: rede resistiva 10 kΩ SIP 9 pinos.
- SW1: chave DIP de 8 vias.
- R1–R8: 1 kΩ.
- C1–C3: 100 nF.
- C4: 10 µF.
- J1: conector IDC 2x8 macho com trava.
- J2–J3: barra de pinos 1x10.
- J4: barra de pinos 1x5.
- 3 soquetes DIP-16.

**Módulo médio:**
- U1 (etiqueta), U2 e U3: 74HC165.
- U4–U6: 74HC595.
- RN1–RN3: rede resistiva 10 kΩ SIP 9 pinos.
- SW1: chave DIP de 8 vias.
- R1–R24: 220 Ω, 1/4 W.
- C1–C5 e C7: 100 nF.
- C6: 470 µF eletrolítico, de 10 V ou mais e até 10 mm de diâmetro.
- J1: conector IDC 2x8 macho com trava.
- K1–K12: conector JST-XH de 4 vias, macho de placa, vertical (B4B-XH-A).
- J2 e J6: barra de pinos 1x5.
- 6 soquetes DIP-16.

**Módulo grande:**
- U1 (etiqueta) a U4: 74HC165.
- U5–U8: 74HC595 (o esquema ainda tem só U5 e U6).
- RN1–RN4: rede resistiva 10 kΩ SIP 9 pinos.
- SW1: chave DIP de 8 vias.
- R1–R32: 1 kΩ.
- C1–C8: 100 nF.
- C9: 10 µF.
- J1: conector IDC 2x8 macho com trava.
- J2–J6: barra de pinos 1x10.
- J7: barra de pinos 1x5.
- 8 soquetes DIP-16.

**Backplane:**
- J1: barra de pinos 1x7.
- J2: barra de pinos 1x16.
- J3: borne de 2 vias.
- JP1: barra de pinos 1x3 com jumper.
- J10–J21: conector IDC 2x8 macho.
- R1–R5: 47 Ω.
- R10–R22: 10 kΩ.
- C1: 470 µF.
- C2: 100 nF.

## PCB do módulo médio

A placa do módulo médio está desenhada e pronta para mandar fabricar. Ela tem um jack para cada [korry](korry/README.md), com o botão e os dois LEDs, e uma barra (J2) com as 4 entradas que sobram, para botões comuns.

| Jack | Pino 1 | Pino 2 | Pino 3 | Pino 4 |
|---|---|---|---|---|
| Kk (k de 1 a 12) | GND | IN(k−1): botão | LED(2k−2): LED de cima | LED(2k−1): LED de baixo |

Por exemplo, o K1 usa IN0, LED0 e LED1, e o K12 usa IN11, LED22 e LED23. Um korry de legenda única acesa usa só o pino 3.

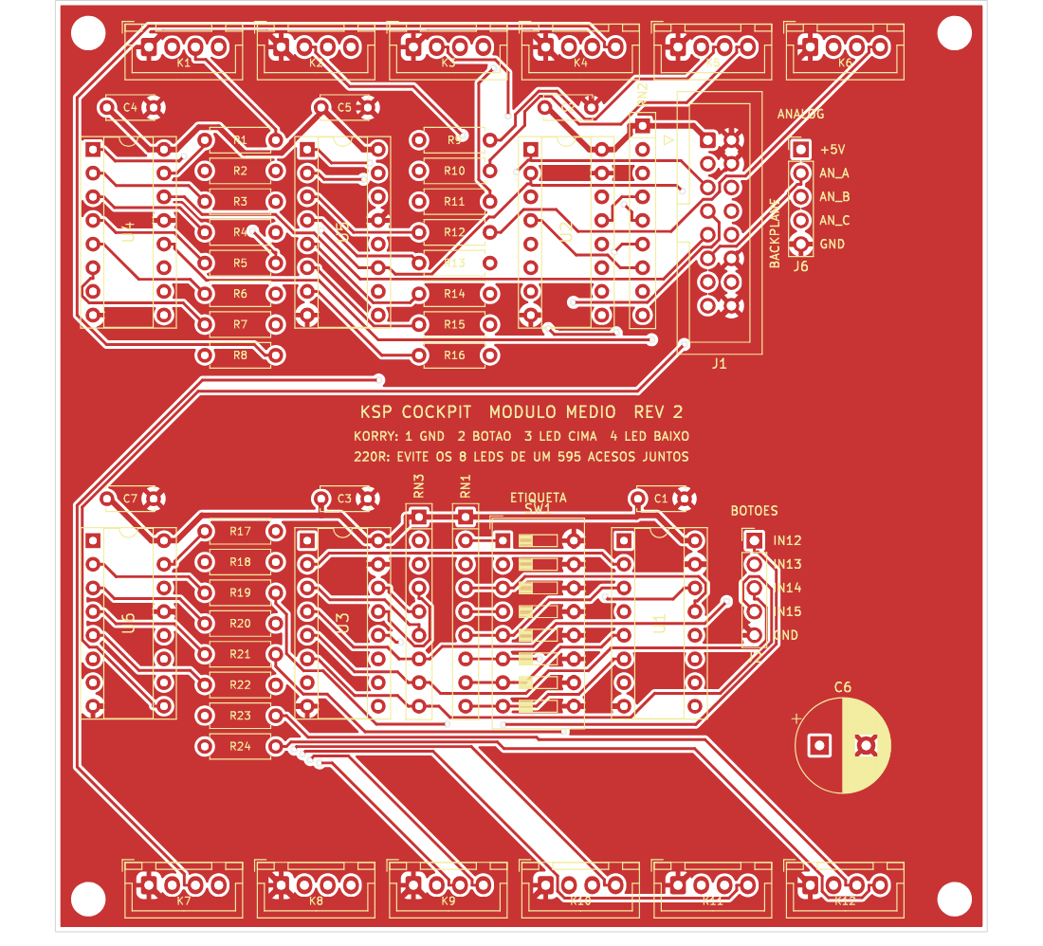
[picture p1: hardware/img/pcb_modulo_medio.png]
Frente da PCB do módulo médio


| O quê | Como é |
|---|---|
| Tamanho | 100 × 100 mm, com 4 furos M3 nos cantos (centro a 3,5 mm das bordas), para prender atrás do painel com espaçadores |
| Camadas | 2, com o GND preenchido nas duas faces |
| Trilhas | 0,3 mm nos sinais e 0,6 mm no +5V e no GND |
| Peças | As da [lista acima](#lista-de-peças-por-placa), todas de furo passante |
| Korry | 12 jacks JST-XH de 4 vias, K1 a K6 na borda de cima e K7 a K12 na de baixo |
| Verificação | DRC do KiCad sem nenhum erro e sem nenhuma ligação faltando |

Os arquivos ficam em [`modulo_medio/`](modulo_medio/): a placa (`modulo_medio.kicad_pcb`), as regras do DRC (`modulo_medio.kicad_dru`) e, em `fabricacao/`, o `modulo_medio_gerbers.zip` com os Gerbers e a furação.

### Como encomendar

1. No site da fábrica (JLCPCB, PCBWay ou outra), enviar o `fabricacao/modulo_medio_gerbers.zip`. O site lê o tamanho sozinho.
2. Escolher 2 camadas, espessura de 1,6 mm e acabamento HASL. A cor não importa. A quantidade mínima costuma ser 5 placas, e as 6 médias do painel cabem em 10.
3. O resto pode ficar no padrão.

### Na hora de montar

- A face de cima tem os nomes das peças, a ordem dos pinos dos jacks (`1 GND  2 BOTAO  3 LED CIMA  4 LED BAIXO`) e os pinos das barras J2 e J6.
- Os pinos 1 têm ilha quadrada. No J1, o pino 1 também tem um triângulo, e ele é o +5V.
- Nas redes RN1 a RN3, o pino comum (marcado com um ponto na peça) vai na ilha quadrada, que é o +5V.
- Os soquetes vão com o chanfro para cima, do lado do pino 1.
- O C6 tem polaridade: a perna mais comprida (+) vai na ilha quadrada.

### Gerar de novo

A placa é gerada por [`pcb/modulo_medio.py`](pcb/modulo_medio.py), a partir do esquema:

1. lê as ligações do `modulo_medio.kicad_sch`;
2. posiciona as peças;
3. roteia com o [Freerouting](https://github.com/freerouting/freerouting);
4. preenche o GND;
5. roda o DRC e refaz os Gerbers.

Mudou o esquema? Basta rodar de novo:

```
python3 hardware/pcb/modulo_medio.py
```

**O que precisa estar instalado:**
- o KiCad 7, com o módulo `pcbnew` do Python;
- o Java 21;
- o jar do Freerouting 1.9, apontado pela variável `FREEROUTING_JAR`;
- o `xvfb-run`, se o computador não tiver tela.

O script para com erro se o roteamento deixar alguma ligação faltando. Ele também imprime o relatório do DRC, que tem que terminar com `Found 0 DRC violations` e `Found 0 unconnected pads`.

## Próximos passos

1. Revisar os esquemas no KiCad e rodar o ERC.
2. Pôr no esquema da placa grande os dois 74HC595 a mais (U7 e U8, LED16 a LED31), para a seção de sistemas de controle.
3. Firmware do Mega: ler a fila de módulos pelas etiquetas e avisar a ponte.
4. Testar o primeiro módulo direto no Mega. Depois, montar o backplane em placa perfurada.
5. Mandar fabricar a PCB do [módulo médio](#pcb-do-módulo-médio) e montar a primeira. As PCBs da pequena, da grande e do backplane ficam para a fase 7.

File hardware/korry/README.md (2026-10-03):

# Korry switch

O botão iluminado quadrado dos aviões, feito em casa: a legenda fica no próprio botão e acende. É uma peça só, **do mesmo tamanho em todo o cockpit**, usada em vários painéis. Por que usar korry e onde ele entra no painel está em [construcao.md](../construcao.md#korry-switches).

**Status: modelo pronto para o primeiro teste de impressão, nada construído.** São quatro peças impressas e não há placa perfurada, peça de laser nem placa fabricada: a chave e os LEDs encaixam direto num suporte impresso. Só a **legenda**, em duas cores, muda de korry para korry; o **corpo**, o **suporte** e a **base** são pretos e iguais para todos. No cockpit, as bases de um grupo de korry saem numa peça só, a **grade**, parafusada atrás do painel ([Fixação no painel](#fixação-no-painel)). A base solta fica para o teste.

| Frente | Corte | Peças |
|---|---|---|
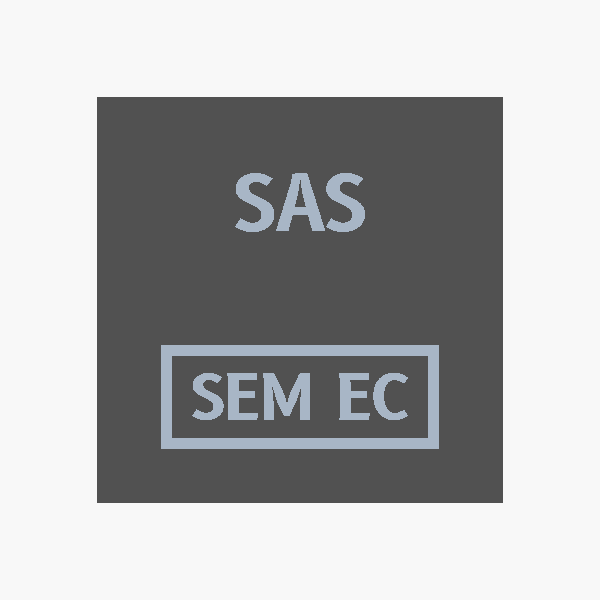
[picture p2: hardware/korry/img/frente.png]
Frente do korry de teste: SAS em cima e SEM EC na caixa embaixo
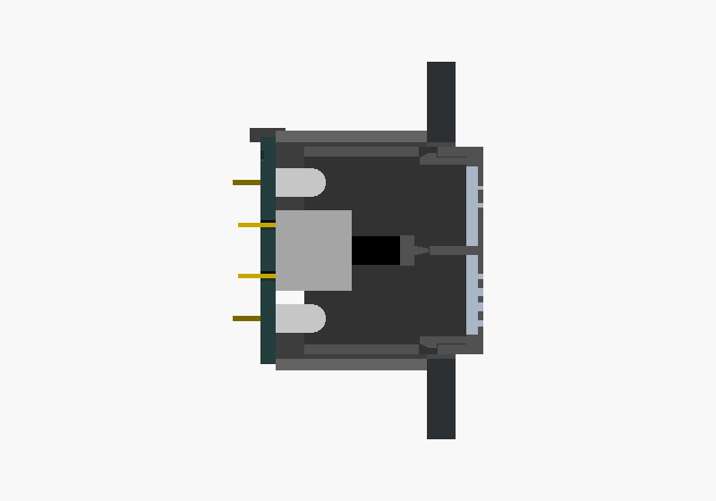
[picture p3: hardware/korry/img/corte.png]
Corte do korry montado no painel
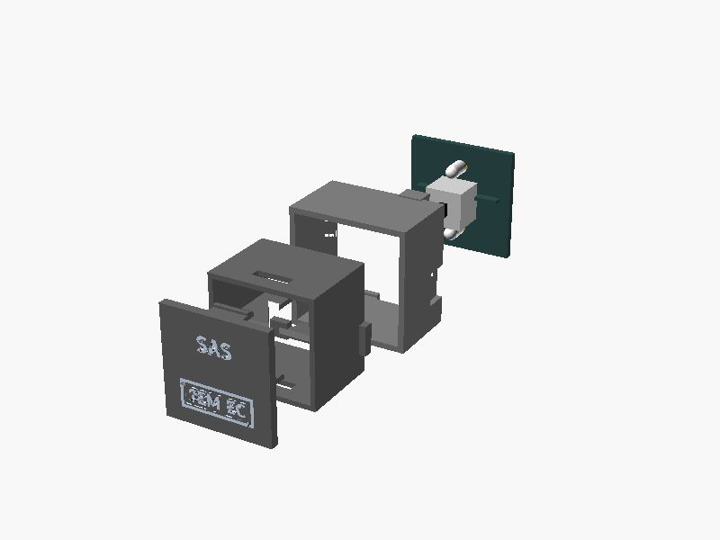
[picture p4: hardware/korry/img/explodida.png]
Korry explodido: legenda, corpo, base, suporte, chave e LEDs
|  |  |  |

## Arquivos

| Arquivo | O que é |
|---|---|
| [`korry.scad`](korry.scad) | O modelo no [OpenSCAD](https://openscad.org/), com as medidas e a legenda nas primeiras linhas. Para as letras saírem certas, instalar a fonte [B612](https://fonts.google.com/specimen/B612) Bold |
| [`stl/legendas/`](stl/legendas/) | As 31 legendas, cada uma em dois arquivos, `<nome>_preto.stl` e `<nome>_transparente.stl`, nas mesmas coordenadas, para imprimir junto com os dois bicos. A lista está em [Legendas](#legendas). A de teste é `sas_preto.stl` e `sas_transparente.stl` (`SAS` / `SEM EC`) |
| [`3mf/legenda_rcs.3mf`](3mf/legenda_rcs.3mf) | A legenda do RCS (`RCS` / `SEM MP`) num arquivo só, de teste: as duas partes já montadas numa peça, a preta e a transparente, cada uma com a sua cor. Ver [Como imprimir](#como-imprimir) |
| [`stl/korry_corpo.stl`](stl/korry_corpo.stl) | O corpo, igual para todos. Preto, um bico só |
| [`stl/korry_base.stl`](stl/korry_base.stl) | A base solta, de um korry só, para o teste. Preta, um bico só |
| [`stl/korry_suporte.stl`](stl/korry_suporte.stl) | O suporte da chave e dos LEDs. Preto, um bico só |
| [`stl/grades/`](stl/grades/) | As 9 grades de fixação, uma por grupo de korry: `grade_<nome>.stl`. Pretas, um bico só. Ver [Fixação no painel](#fixação-no-painel) |
| [`grades.json`](grades.json) | Onde ficam os korry e os parafusos de cada grade, nas coordenadas do desenho do painel. Lido pelo `gerar.py` e pelo `desenhar.js` |
| [`gerar.py`](gerar.py) | Gera os STL (legendas, peças iguais e grades) e as imagens: `python hardware/korry/gerar.py` |
| [`stl/korry_teste.stl`](stl/korry_teste.stl) | O teste de folga: 5 encaixes de 0,35 a 0,6 mm e um pedaço do corpo (o primeiro teste, de 0,1 a 0,3 mm, ficou apertado em todos; o segundo deu 0,5 mm) |
| [`ligacao.js`](ligacao.js) | Gera [`ligacao.svg`](ligacao.svg), o desenho da ligação da chave e dos LEDs: `node hardware/korry/ligacao.js` |
| [`korry.svg`](korry.svg) | O desenho da primeira especificação, com a tampa de acrílico: os quatro estados da legenda continuam valendo |

### Gerar os STL e as imagens

O `gerar.py` usa só a biblioteca padrão do Python e roda de qualquer pasta. Precisa do `openscad` no PATH e da fonte B612 Bold instalada; para as imagens, sem tela, usa o `xvfb-run`. Os STL saem em binário, para o repositório não crescer à toa.

```
python hardware/korry/gerar.py              tudo
python hardware/korry/gerar.py --legendas   as 31 legendas
python hardware/korry/gerar.py --pecas      corpo, base, suporte e teste
python hardware/korry/gerar.py --grades     as grades do grades.json
python hardware/korry/gerar.py --imagens    frente, corte, explodida, legendas e grade
python hardware/korry/gerar.py --3mf rcs    a legenda rcs num 3MF de duas cores
```

O `--3mf` junta os dois STL de uma legenda, já gerados, num 3MF em `3mf/legenda_<nome>.3mf`: um objeto com duas partes, `<nome>_preto` e `<nome>_transparente`, com as cores preto e transparente. Não precisa do OpenSCAD e aceita vários nomes (`--3mf rcs sas fbw`). Por enquanto só o do RCS está no repositório, para testar.

Ao gerar as legendas, o script confere o tamanho de cada uma: nada passa de 9,75 mm do centro em `x` (0,5 mm de folga da borda interna da legenda), e nas de duas metades o texto de cima fica acima da divisória e o de baixo abaixo. Se falhar, para com a mensagem.

**Uma legenda nova** entra na tabela `LEGENDAS` do `gerar.py` (nome do arquivo, `texto_cima`, `texto_baixo` e `modo_sas`). Para só testar, direto no `openscad`, dentro de `hardware/korry/`:

```
openscad -D 'peca="legenda_preto"' -D 'texto_cima="RCS"' -D 'texto_baixo="SEM MP"' -o legenda_preto.stl korry.scad
openscad -D 'peca="legenda_transparente"' -D 'texto_cima="RCS"' -D 'texto_baixo="SEM MP"' -o legenda_transparente.stl korry.scad
openscad -D 'peca="legenda_preto"' -D 'modo_sas="PRO"' -o legenda_preto.stl korry.scad
```

Com `texto_baixo=""`, a legenda é única; com os dois textos vazios e sem `modo_sas`, é a em branco. Com `modo_sas` (`ESTAB`, `MAN`, `PRO`, `RETRO`, `NRM`, `ANRM`, `RFORA`, `RDENTRO`, `ALVO` ou `AALVO`), a legenda é de modo do SAS: o ícone em cima e a palavra embaixo, numa peça só. O tamanho das letras se ajusta ao texto: `PARAQUEDAS` e `RAD DENTRO` ficam com ~2,1 mm, e os textos curtos chegam a 3 mm. O corpo, a base e o suporte não mudam.

O `peca="corte"` do `korry.scad` mostra a montagem cortada ao meio, com a face cortada nas cores das peças; o `peca="montagem"` é a montagem inteira, sem corte; o `peca="legenda_2d"` exporta só o desenho 2D da legenda.

## Referências

- **Aparência:** o botão START do A320, com a legenda em duas metades: em cima `AVAIL`, só as letras; embaixo `ON`, dentro de uma caixa. Cada metade acende sozinha, na sua cor. Apagadas, as legendas continuam legíveis.
- **Circuito:** uma chave e dois LEDs encaixados num suporte impresso atrás do corpo, ligados por um rabicho de 4 fios com um conector de 4 vias na ponta.

## Onde vai

Na [versão B do cockpit](../construcao.md#cockpit-versão-b) são 35:

| Painel | Korry | Legenda |
|---|---|---|
| Voo | 14 | 10 modos do SAS: o marcador da navball com a palavra embaixo, LED azul e verde. SAS, RCS e FBW: duas metades. TRAVA ALT: uma legenda |
| Ação executiva | 6 | Os scripts: POUSO e cinco vagos, LED vermelho e verde (âmbar com os dois) |
| Editor de manobras | 3 | PRO, NRM e RAD: uma legenda, acesa no eixo escolhido |
| Action groups | 4 | PARAQUEDAS, SOLAR, ANTENAS e CARGA: uma legenda, verde |
| Acelerador | 3 | TREM, FREIOS e LUZES: uma legenda, verde |
| Recursos e EVA | 2 | JATO e LUZ: uma legenda, verde |
| Câmera | 2 | MAPA e IVA: uma legenda, branca. O IVA com capa |
| Tempo | 1 | FISICO: uma legenda, branca |

Os botões que não têm luz para mostrar (os action groups 1 a 8, NOVO, APAGAR, CIRC) viraram botões de 16 mm comuns.

## Legendas

São 31 legendas diferentes para os 35 korry: os cinco scripts vagos usam a mesma legenda em branco. Cada uma é um par de arquivos em [`stl/legendas/`](stl/legendas/), `<nome>_preto.stl` e `<nome>_transparente.stl`.

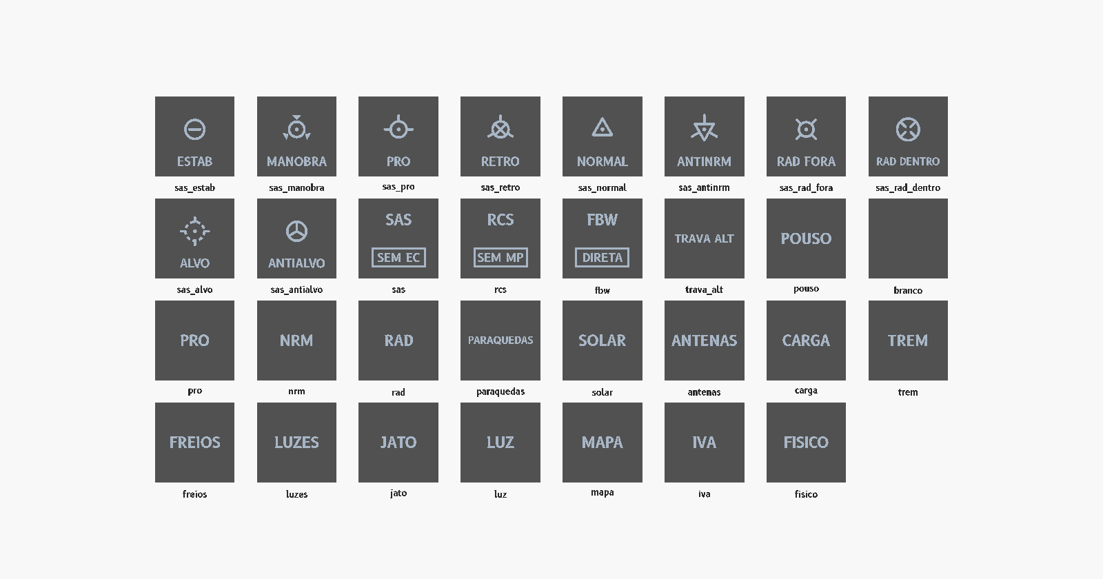
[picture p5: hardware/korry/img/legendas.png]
As 31 legendas, de frente: os 10 modos do SAS com o ícone e a palavra, as três de duas metades, a em branco e as de uma palavra só


| Painel | Korry | Arquivos (`stl/legendas/`) |
|---|---|---|
| Voo, modos do SAS | 10 | `sas_estab`, `sas_manobra`, `sas_pro`, `sas_retro`, `sas_normal`, `sas_antinrm`, `sas_rad_fora`, `sas_rad_dentro`, `sas_alvo`, `sas_antialvo` |
| Voo, sistemas | 4 | `sas`, `rcs`, `fbw` (duas metades) e `trava_alt` |
| Ação executiva | 6 | `pouso` e cinco `branco` |
| Editor de manobras | 3 | `pro`, `nrm`, `rad` |
| Action groups | 4 | `paraquedas`, `solar`, `antenas`, `carga` |
| Acelerador | 3 | `trem`, `freios`, `luzes` |
| Recursos e EVA | 2 | `jato`, `luz` |
| Câmera | 2 | `mapa`, `iva` |
| Tempo | 1 | `fisico` |

- **Modos do SAS:** o ícone do marcador da navball em cima e a palavra embaixo (ESTAB, MANOBRA, PRO, RETRO, NORMAL, ANTINRM, RAD FORA, RAD DENTRO, ALVO, ANTIALVO), sem divisória, como uma legenda única. Os ícones são os mesmos do desenho do painel, com traço de 0,7 mm.
- **Legenda em branco:** a máscara preta inteira, sem letras, para os lugares vagos dos scripts. Quando o script existir, ganha a legenda dele.
- **IVA:** a legenda é a de sempre; a capa é uma peça à parte e a grade não mexe nela.

## Medidas

| O quê | Medida | Observação |
|---|---|---|
| Frente | **21,9 × 21,9 mm** | Igual em todos. É o vão da base (22,9 mm) menos a `folga` de 0,5 mm de cada lado, medida no teste de folga |
| Furo no painel | 23 × 23 mm | 0,55 mm de folga por lado. Conferir na plaquinha de teste da laser, que queima um pouco em volta do corte |
| Saliência na frente do painel | 3 mm | A legenda (1,8 mm) e 1,2 mm da frente do corpo. O corpo anda ~2,2 mm até a chave chegar ao fim (curso de 2,5 mm menos 0,3 mm de pré-carga) e a frente ainda sai ~0,8 mm do painel apertado |
| Corpo | 17,2 mm de comprimento | 16 mm atrás do painel, até os ressaltos de trás, mais 1,2 mm na frente do painel, onde a legenda encaixa |
| Base | 25,3 mm de lado, 16 mm de fundo | Mais os ganchos, que chegam a 18,8 mm. O tubo de 25,3 mm cabe no passo mínimo de 25,5 mm |
| Grade | 25,3 mm por korry, 16 mm de fundo | As bases do grupo numa peça só, com orelhas de 7 mm de largura e 5 mm de espessura para os parafusos. A maior (`voo_sas`) tem uns 136 × 65 mm |
| Suporte | 24,1 × 24,1 × 1,6 mm | Preso pelos ganchos da base, por fora do tubo |
| Atrás do painel | ~22 mm | Até as pernas da chave, que saem atrás do suporte. Somar os fios |
| Distância entre korry vizinhos | 3 mm | De borda a borda, ou **25,5 mm de centro a centro**: é o passo mínimo. O `korry.scad` recusa uma grade com korry mais perto |
| Legenda | 21,9 × 21,9 × 1,8 mm | Encaixa por pressão na ponta do corpo, com duas abas. Máscara preta de 0,6 mm na frente e 1,2 mm de transparente atrás |
| Legenda de cima | letras de até 3 mm | B612 Bold. O tamanho se ajusta ao texto (fator de largura 0,85): TRAVA ALT e as palavras longas ficam menores |
| Legenda de baixo | letras de até 2,4 mm, numa caixa de até 15 × 5,6 mm | Como o `ON` do A320. A caixa acompanha o texto |
| Legenda única | letras de até 3 mm, centradas | Sem a divisória. As mais apertadas, PARAQUEDAS e RAD DENTRO, ficam com ~2,1 mm |
| Legenda dos modos do SAS | ícone em cima, palavra de até 2,4 mm embaixo | Sem a divisória. Traço do ícone de 0,7 mm |
| Chave | PSW 8,5 × 8,5 mm, 8 mm de altura | O êmbolo sai 5,5 mm e tem 2 × 3 mm |
| Curso da chave | ~2,5 mm | Conferir na chave real |
| Divisória | No centro do korry | A do corpo começa 4 mm atrás da legenda. Na legenda única, a luz das duas metades se mistura nesse vão; na de duas metades, uma aleta preta da legenda fecha o vão |

## Peças

- **Legenda**, impressa em duas cores numa peça só, de frente para baixo na mesa, com 1,8 mm de espessura. É a única peça que muda de korry para korry:
  - **Preto:** a borda de 1 mm, uma camada de 0,6 mm na frente com a legenda vazada e a divisória que separa a luz das duas metades. Atrás dela saem duas abas com dente, uma em cima e outra embaixo, que travam o corpo.
  - **Transparente:** as letras e o ícone, nos furos da camada preta, e o bloco de 1,2 mm atrás dela, dividido em dois pela divisória. Apagada, a legenda aparece clara; acesa, na cor do LED.
- **Corpo:** um tubo preto, igual para todos, em que a legenda encaixa por pressão (as abas entram nas janelas das paredes de cima e de baixo). Ele sai 1,2 mm na frente do painel, com a legenda na frente dele, e tem 16 mm atrás do painel. Na ponta de trás, dois ressaltos nos lados correm nos trilhos da base e seguram o corpo. Os ressaltos ficam **alternados**: em um lado acima do centro e no outro abaixo, para os trilhos de dois korry vizinhos de uma grade não se cruzarem na mesma parede. Por dentro tem uma divisória, que continua a da legenda, com um apoio que empurra o êmbolo da chave e asas que separam a luz dos lados da chave.
- **Base:** um tubo preto atrás do painel, com os trilhos por onde o corpo desliza e dois ganchos que prendem o suporte. Os ganchos ficam fora do suporte e também **alternados** (o de cima e o de baixo em posições diferentes ao longo da parede), para os de dois vizinhos não baterem. A base solta serve para o teste; no cockpit, as bases de um grupo saem juntas na **grade**. Não leva os parafusos M2 da primeira especificação: com 3 mm entre korry, as abas não cabem.
- **Grade:** as bases de um grupo de korry numa peça só, com as paredes entre vizinhos fundidas e orelhas com furo para o parafuso do painel. Ver [Fixação no painel](#fixação-no-painel).
- **Suporte:** uma plaquinha preta de 24,1 × 24,1 × 1,6 mm, com 6 furos para as pernas da chave, 4 para as pernas dos LEDs, uma nervura de cada lado da chave, logo acima da divisória, para a luz não passar por baixo das asas e a palavra `CIMA` gravada atrás. É igual para todos.
- **Chave PSW 8,5 × 8,5 mm, sem trava**, de 6 pinos. Usa um polo só: o comum e o contato que fecha apertado. A mola da chave devolve o corpo. O curso é curto, como no botão do avião.

## Fixação no painel

Os korry de um grupo ficam presos numa **grade**: uma peça preta com as bases do grupo juntas, encostada **atrás** do painel e parafusada nele. O corpo entra por trás na base da grade, antes do suporte, e sai pelo furo de 23 × 23 mm; a legenda encaixa nele pela frente, já com o painel montado. Sem cola, e a grade de cada grupo se tira e se põe de volta.

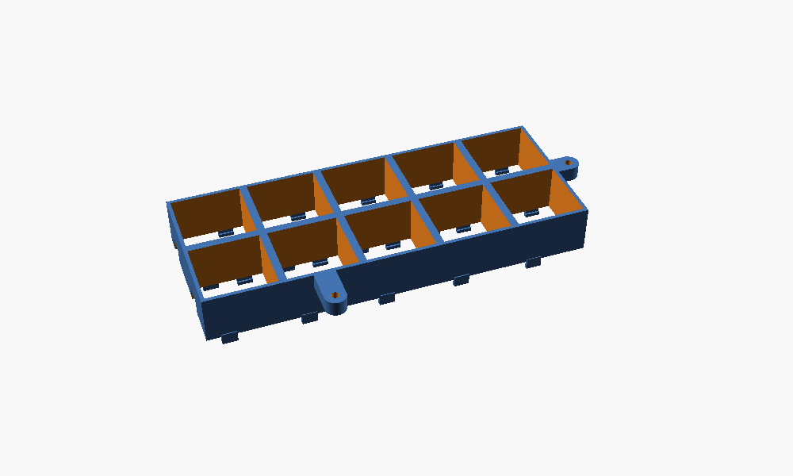
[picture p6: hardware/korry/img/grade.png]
Grade do voo_sas vista de trás: dez bases juntas, com duas orelhas de parafuso


- **Parafuso:** M3 autoatarraxante, de 8 mm, **pela frente do painel**, com a cabeça na frente. O painel tem furo de 3,2 mm; a orelha da grade, de 2,5 mm, onde o parafuso abre a rosca no PLA. O painel (3 mm) mais a orelha (5 mm) dão os 8 mm do parafuso.
- **Orelhas:** 7 mm de largura, do furo até a parede da base mais próxima, com a ponta redonda. Ficam encostadas atrás do painel, no mesmo plano das bases.
- **Posição dos parafusos:** nas pontas do grupo, onde há espaço. Os que ficam perto da borda do painel ficam a 6 mm dela, alinhados com os parafusos de canto do painel.
- **Um parafuso só** na grade do FISICO, embaixo do korry, porque do lado não sobra lugar para o ATE O NO: o korry dentro do furo do painel impede a grade de girar em torno do parafuso.
- **Korry afastados** (a `vista`, com passo de 31 mm): o fechamento não une as bases sozinho, e a grade ganha uma barra de 6 mm no plano das orelhas.
- **Passo mínimo de 25,5 mm** de centro a centro entre korry vizinhos: 25,3 mm do tubo mais 0,2 mm entre vizinhos. A base não muda com a `folga`: quem diminui é o korry. Os ganchos e os ressaltos alternados é que deixam as paredes se encostarem. O `korry.scad` recusa grades com korry mais perto.
- **Posição:** as coordenadas do `grades.json` são as do desenho do painel (origem no canto de cima à esquerda, `y` para baixo), em mm. Os parafusos aparecem nos desenhos dos painéis.

| Grade | Painel | Korry | Passo (mm) | Parafusos (x, y) |
|---|---|---|---|---|
| `voo_sas` | Voo | 10 (5 × 2) | 25,5 × 25,5 | (6, 47,5) e (100,5, 11,5) |
| `voo_sistemas` | Voo | 4 em fila | 26 | (6, 99,25) e (119,75, 99,25) |
| `scripts` | Ação executiva | 6 (2 × 3) | 25,5 × 26,5 | (119, 35,25) e (119, 88,25) |
| `rodas` | Acelerador | 3 em coluna | 27 | (76,5, 64,25) e (108,5, 64,25) |
| `pecas` | Action groups | 4 em fila | 25,5 | (6, 100,25) e (119, 100,25) |
| `vista` | Câmera | 2 em fila | 31 | (6, 37,25) e (75, 37,25) |
| `deltav` | Editor de manobras | 3 em coluna | 25,5 | (26,75, 25,25) e (26,75, 108,25) |
| `eva` | Recursos e EVA | 2 em fila | 25,5 | (33,75, 77,25) e (91,25, 77,25) |
| `fisico` | Tempo | 1 | | (74,75, 52) |

São 17 parafusos no total. O `voo_sas` tem um parafuso em cima, entre o título e o grupo, e o `scripts` tem os dois à direita do grupo.

### Uma grade para um grupo novo

1. Desenhar o painel com os korry a **25,5 mm ou mais** de centro a centro.
2. Acrescentar um item ao [`grades.json`](grades.json): `nome`, `painel` (o arquivo de `hardware/desenho/paineis/`), `korry` (os centros) e `parafusos` (os centros dos furos), nas coordenadas do desenho. Parafusos nas pontas do grupo, sem cair em cima de outro controle, de uma legenda ou da linha do grupo.
3. `python hardware/korry/gerar.py --grades` gera `stl/grades/grade_<nome>.stl`. O script tira a média dos centros do grupo e passa tudo para as coordenadas do OpenSCAD (`x` e `y` com o sinal trocado, porque a grade é vista por trás e o desenho tem `y` para baixo).
4. `node hardware/desenho/desenhar.js` põe os parafusos novos no desenho do painel.
5. Para ver direto: `openscad -D 'peca="grade"' -D 'celulas=[[0,0],[25.5,0]]' -D 'furos=[[-20,0]]' -o grade.stl korry.scad`, com as posições já nas coordenadas do OpenSCAD.

## Montagem do suporte

A chave e os LEDs entram pela frente do suporte e as pernas saem atrás. Os 4 fios são soldados direto nelas e terminam num conector JST-XH fêmea de 4 vias, um rabicho de uns 10 cm.

Suporte: na frente a chave no meio e um LED acima e outro abaixo; no verso as pernas, os 4 fios e o conector JST-XH visto pelo lado dos fios

1. **Chave** pela frente, com as pernas nos 6 furos e o êmbolo para a frente.
2. **LEDs de 3 mm**, um acima e outro abaixo da chave, pela frente. O catodo (perna curta, lado chato) vai para a esquerda, olhando a frente, como no desenho.
3. **Multímetro:** descobrir qual perna da fileira de cima fecha com a perna do meio só com a chave apertada. É a que vai para o BTN. O desenho mostra a ponta; se for a outra, trocar.
4. **Soldar os fios no verso**, como no desenho. O GND emenda o catodo do LED de cima, a perna do meio da chave (o comum) e o catodo do LED de baixo. O LC vai no anodo do LED de cima, o LB no anodo do de baixo e o BTN na perna que fecha.
5. **Isolar** cada solda com espaguete termo-retrátil.
6. **Crimpar o JST-XH fêmea de 4 vias** na ponta dos fios, na ordem 1 GND, 2 BTN, 3 LC, 4 LB. O desenho mostra o conector visto pelo lado dos fios, com os pinos 4 3 2 1 da esquerda para a direita.
7. **Prender o suporte** nos ganchos da base, com a palavra `CIMA` para cima.

- **Modos do SAS:** o LED azul e verde (3 pernas) vai no lugar do LED de cima: azul no LC, verde no LB, catodo no GND. A ordem das pernas muda de fabricante para fabricante: testar antes de soldar. Os furos do LED de baixo ficam vazios.
- **Korry sem luz:** só a chave e 2 fios (GND e BTN). Os furos dos LEDs ficam vazios.
- **Trocar a legenda:** soltar o suporte dos ganchos, puxar o corpo para trás, para fora da base, e apertar os dois dentes pelas janelas com uma chave de fenda pequena. A legenda nova entra empurrando, até os dentes estalarem nas janelas.
- **Montou errado?** Girado 90°, os LEDs batem nas asas da divisória e o suporte não encaixa. Girado 180° monta, mas troca cima e baixo: por isso o `CIMA` gravado.

## Circuito

```
  módulo                               korry
  ──────                               ─────
  INn   ─────────────── 2 BTN ────┐
                                  └─[ chave ]──┐
  LEDn  ──[1 kΩ]─────── 3 LC ───►|─ LED de cima ─┤
  LEDm  ──[1 kΩ]─────── 4 LB ───►|─ LED de baixo ┤
  GND   ─────────────── 1 GND ─────────────────┘
```

- **Não tem CI nem resistor no korry.** O pull-up da entrada e os resistores dos LEDs já estão no módulo (ver o [README do hardware](../README.md#no-módulo)). O korry é só chave, LEDs e fios.
- **Conector de 4 pinos:** 1 GND, 2 BTN, 3 LC (LED de cima), 4 LB (LED de baixo). JST-XH fêmea de 4 vias (passo de 2,5 mm) na ponta do rabicho, que liga direto no jack do módulo. O [módulo médio](../README.md#pcb-do-módulo-médio) já tem 12 jacks JST-XH nessa ordem: o korry do jack Kk usa a entrada IN(k−1) e as saídas LED(2k−2) e LED(2k−1).
- **Apertado lê 0**, como qualquer botão dos módulos.
- **Cada korry gasta 1 entrada e 0, 1 ou 2 saídas de LED:**
  - duas metades: 2 saídas;
  - legenda única acesa: 1 saída, com os dois LEDs em paralelo nela;
  - legenda única sem luz (NOVO, APAGAR, CIRC): nenhuma, e os LEDs nem são montados;
  - legenda única de duas cores (os modos do SAS): 2 saídas, com um LED azul e verde de catodo comum. O pino 3 (LC) acende o azul, o 4 (LB) o verde; o conector e o circuito não mudam.
- **A cor é a do LED**, escolhida na montagem, porque a tampa é branca. Uma cor fixa por metade, das cores da [identidade visual](../identidade_visual.md#cores-das-luzes): verde, azul, branco, âmbar ou vermelho. Os modos do SAS têm as duas cores no mesmo LED. A exceção são os korry de eixo do editor, nas cores das alças do nó no KSP (verde-amarelo, magenta e ciano), porque a cor ali diz qual é o eixo, e não um estado.

### Brilho

Com o resistor de 1 kΩ do módulo, cada LED recebe uns 3 mA (uns 2 mA os brancos). Atrás de 1,2 mm de PLA transparente (1,8 mm nas letras) pode ser pouco. O módulo médio usa 220 Ω, uns 13 mA por LED: bem mais forte, mas passa do limite do 74HC595 com os 8 LEDs dele acesos juntos.

1. Testar primeiro com 1 kΩ, no escuro e de dia.
2. Se ficar fraco, trocar o resistor daquela saída no módulo por 470 Ω: uns 6 mA por LED.
3. Não passar de uns 8 mA por LED: cada 74HC595 aguenta 70 mA no total, e com 8 LEDs acesos juntos 8 mA já dá 64 mA.
4. Na legenda única com dois LEDs na mesma saída, a corrente se divide entre os dois: é o caso que mais pede 470 Ω.

## O que as luzes dizem

Como em todo o painel, **a luz mostra o estado do jogo, nunca o toque**. O korry só avisa "apertei" (`BTN SAS 1`); a ponte decide e o LED acende quando o jogo confirma. O firmware não muda: já manda botões e acende LEDs.

| Metade | Acende quando | Exemplo |
|---|---|---|
| Cima | O sistema está ligado no jogo | `SAS` verde: o SAS está ligado |
| Baixo, na caixa | Algo pede atenção | `FAULT` âmbar: o pedido foi recusado, por exemplo a nave não tem SAS. A ponte acende por uns segundos |
| Única | O estado ou modo está escolhido | `PRO` verde-amarelo: o encoder mexe no pró-grado |
| Única, duas cores | Azul: o modo foi escolhido e ainda não assumiu. Verde: assumiu | Modo do SAS: azul com a nave virando, verde com ela no marcador |

## Como imprimir

Na FlashForge Inventor, que tem dois bicos, com o FlashPrint:

1. **Teste de folga** ([`korry_teste.stl`](stl/korry_teste.stl)), só em preto. A folga em que o pedaço de corpo desliza sem balançar vai para a variável `folga` do `korry.scad` (hoje 0,5 mm) e tudo é gerado de novo (`python hardware/korry/gerar.py`). A base e as grades não mudam de tamanho: o corpo e a legenda é que ficam menores, `22,9 − 2 × folga`.
2. **Uma legenda de teste:** a mais simples é abrir [`legenda_rcs.3mf`](3mf/legenda_rcs.3mf), que já traz as duas partes no lugar, numa peça só. Se o fatiador mostrar duas partes sem bico, pôr a `rcs_preto` no bico do PLA preto e a `rcs_transparente` no do transparente. Se o FlashPrint não abrir o 3MF com as duas cores, usar o par de STL: abrir [`sas_preto.stl`](stl/legendas/sas_preto.stl) e [`sas_transparente.stl`](stl/legendas/sas_transparente.stl) juntos e aceitar quando o FlashPrint perguntar se é um modelo de duas cores, para as partes ficarem no lugar. PLA preto num bico, transparente no outro. Já estão de frente para baixo.
3. **Torre de limpeza** (*wipe wall*) ligada, para o transparente não sair sujo de preto.
4. **Corpo e suporte**, só em preto, um bico só. Já estão na posição certa (o corpo e o suporte de trás para baixo): não precisam de suporte de impressão. Para o teste, a **base solta** ([`korry_base.stl`](stl/korry_base.stl)); no cockpit, a **grade** de cada grupo ([`stl/grades/`](stl/grades/)), também em preto e um bico só, no lugar das bases. A maior, a do `voo_sas`, tem uns 136 × 65 × 19 mm e cabe na mesa de 230 × 150 mm.
5. **As legendas de cada painel**, em duas cores como a de teste, uma de cada vez: a tabela de [Legendas](#legendas) diz quais ficam em cada painel. Conferir uma de cada tipo antes de imprimir as outras: uma de modo do SAS (com o ícone), uma de duas metades e a de letras menores (`paraquedas`).
6. Camada de 0,12 mm, 3 perímetros, sem suporte.

**O que pode dar errado no teste:**

- **Letras finas sumindo:** o `SEM EC` tem 2,4 mm, e o `PARAQUEDAS` e o `RAD DENTRO` só ~2,1 mm, com os traços perto da largura do bico. Se falhar, `letra_baixo = 2.8`, ou ligar a opção de paredes finas no FlashPrint.
- **Ícone do SAS borrado:** o traço é de 0,7 mm. Se não sair, `traco_icone = 0.9`.
- **Furo da orelha da grade rachando ou frouxo:** o `furo_m3` é de 2,5 mm para o parafuso abrir a rosca; mudar para 2,6 ou 2,4 conforme o parafuso.
- **Luz vazando de uma metade para a outra:** a divisória tem 1 mm. Se vazar, `divisoria_e = 1.6`.
- **Aba da legenda dura demais ou quebrando:** `dente = 0.4` ou `aba_e = 0.7`.
- **Luz vazando em cima da chave:** é o vão do curso, onde o corpo anda sobre a chave. Apagado não aparece; com uma metade acesa, a outra pode ganhar um brilho fraco. Se incomodar, passar tinta preta fosca ou fita isolante nas laterais de cima da chave.
- **Sombra da divisória na legenda única:** a divisória do corpo continua lá, atrás da legenda. Se a sombra dela aparecer, aumentar o `recuo`.
- **Furos das pernas apertados:** `furo_pino` (chave) e `furo_led` (LEDs).
- **Chave diferente do desenho:** conferir `pino_fileiras`, `curso` e `haste_h` com a chave real.

## Lista de peças (um korry)

- Legenda em PLA preto e transparente; corpo, suporte e base (ou o pedaço dela na grade do grupo) em PLA preto.
- 1 chave PSW 8,5 × 8,5 mm, sem trava, de 6 pinos.
- 0 a 2 LEDs de 3 mm, difusos, de alto brilho, na cor da legenda. Nos modos do SAS, 1 LED azul e verde de 3 mm, difuso, de catodo comum.
- 4 fios finos (~10 cm) e 1 conector JST-XH fêmea de 4 vias, com os terminais.
- Espaguete termo-retrátil para isolar as soldas.

Por grupo de korry: a grade impressa em preto e 2 parafusos M3 autoatarraxantes de 8 mm (1 na do FISICO), 17 no total.

## Ordem para fazer

1. **Teste de folga** e ajuste da `folga` no modelo. Feito: 0,5 mm.
2. **Um korry de teste**, ligado direto num pino do Mega como na [fase 2](../../docs/fase2.md): a legenda, o clique, a folga do corpo na base, a força do encaixe da legenda e o brilho, com 1 kΩ e com 470 Ω.
3. **Uma grade pequena**, a do FISICO ou a da `vista`, parafusada num painel de teste: o furo, o parafuso, o encaixe dos korry e a distância entre vizinhos.
4. **Os 35**, cada um com a sua legenda, inclusive os ícones dos modos do SAS, depois que os testes derem certo, e uma grade por grupo.

## A decidir

- O curso e as medidas reais da chave PSW (`curso`, `haste_h`, `pino_fileiras`).
- A força do encaixe da legenda: se as abas seguram sem quebrar nem soltar, agora que ela tem 1,8 mm.
- Se as letras de ~2,1 mm (`PARAQUEDAS`, `RAD DENTRO`) e o ícone de 0,7 mm saem bem na impressora.
- A firmeza do parafuso de 8 mm e o furo de 2,5 mm na orelha de PLA.
- O brilho dos LEDs atrás de 1,2 mm de transparente.

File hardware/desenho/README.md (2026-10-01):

# Desenhos dos painéis

Os painéis são desenhados em código, em SVG, com as peças no tamanho real (unidades em mm). Assim todos saem com a mesma [identidade visual](../identidade_visual.md), e o histórico dos desenhos fica legível no git.

| Arquivo | O que é |
|---|---|
| [`pecas.js`](pecas.js) | As peças: painel, grupo, korry, encoder, chave rotativa, tecla, botões, capas, barra de LEDs, alavanca, manche, cotas |
| [`paineis/`](paineis/) | Um arquivo por painel da [versão B](../construcao.md#cockpit-versão-b), que monta as peças nas posições certas, e o `cockpit.js`, que junta todos na vista de frente |
| [`antigos/`](antigos/) | Os painéis de 150 mm das propostas anteriores |
| [`desenhar.js`](desenhar.js) | Gera `hardware/img/<painel>.svg` a partir de cada arquivo de `paineis/` |

## Gerar

Precisa só do Node.js, sem instalar nada:

```
node hardware/desenho/desenhar.js                    # todos os painéis
node hardware/desenho/desenhar.js editor_manobras    # só um
node hardware/desenho/desenhar.js antigos            # os de 150 mm, em hardware/img/antigos/
```

Cada arquivo de `paineis/` exporta uma função que devolve `{ w, h, corpo, rotulo }`: a largura e a altura em mm, o SVG do painel e a descrição para leitores de tela. O `desenhar.js` põe as cotas em volta, e o `cockpit.js` usa o `corpo` de cada painel na vista de frente.

## Painel novo

1. Copiar `paineis/tempo.js` com o nome do painel, por exemplo `paineis/radar.js`.
2. Trocar o título, os grupos e as peças. As posições são em mm, a partir do canto de cima à esquerda do painel de 125 × 125 (ou 250 × 125).
3. Para pôr no cockpit, uma linha no `lugar` do `cockpit.js`, com a coluna e a fileira.
4. Gerar e abrir o SVG no navegador.
5. Pôr o desenho no documento do painel (por exemplo, uma seção em `hardware/construcao.md`).

Peça nova (um botão diferente, um display): uma função nova em `pecas.js`, no tamanho real, e uma linha na tabela de peças da [identidade visual](../identidade_visual.md#peças).

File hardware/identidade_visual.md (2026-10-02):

# Identidade visual do cockpit

Como todo painel do cockpit tem que parecer: cores, letras, medidas e peças. Vale para os painéis de verdade (laser e impressora) e para os desenhos. O exemplo de referência é o cockpit da [versão B](construcao.md#cockpit-versão-b):

O cockpit da versão B, o exemplo da identidade visual

A referência são os painéis de avião, como o overhead do A320 e o MCP do Boeing: sóbrios, cinza escuro, legendas brancas e botões iluminados. O KSP entra nos detalhes, como as cores das alças do nó de manobra.

## Painel

| O quê | Como é |
|---|---|
| Tamanho | **125 × 125 mm**, igual em todos. Uma seção que precise de mais espaço ocupa dois quadrados (250 × 125 mm), como a tela, o voo e o editor de manobras. Os desenhos antigos, de 150 mm, estão em [`img/antigos/`](img/antigos/) |
| Material | MDF ou acrílico de 3 mm, cortado e gravado a laser |
| Cor | Cinza escuro fosco, `#30353a` nos desenhos, com borda `#15181b` e cantos arredondados de 2,5 mm |
| Fixação | 4 parafusos M3 nos cantos, com o centro a 6 mm das bordas |
| Título | O nome da seção, gravado em cima e centrado, com letras de 4 mm. Ex.: `EDITOR DE MANOBRAS`. A tela multifunção não tem título: a tela de 7" ocupa a altura toda |
| Margem | Os grupos começam a 10 mm das bordas dos lados, para não bater nos parafusos |

## Grupos

Dentro do painel, os controles ficam em **grupos**, cada um com uma linha em volta e o nome interrompendo a linha de cima, como nos painéis de avião. Assim a mão acha o grupo sem olhar.

- Linha branca de 0,35 mm, cantos de 1,2 mm.
- Nome em cima, centrado, com letras de 2,8 mm.
- 6 mm entre grupos vizinhos.
- **O nome diz o que o grupo faz, e não o nome de um controle:** o grupo com o TEMPO, o ANT e o PROX se chama `PERCURSO`, porque anda pelo caminho da nave. Não repetir o nome de outra seção do cockpit (já existe uma `NAVEGACAO`).
- Em cima, o que ajusta; embaixo, o que age (criar, apagar, executar).

## Letras

- **Fonte:** [B612](https://fonts.google.com/specimen/B612), feita pela Airbus para as telas de cockpit e livre. Negrito nas legendas. Para números alinhados, B612 Mono.
- **Sempre maiúsculas e em ASCII, sem acentos**, como no LCD e na serial: `NO`, e não `NÓ`; `AMBAR`, e não `ÂMBAR`.
- **Cor:** branco `#eef0ea` para as legendas; cinza `#b9bfc5` para as legendas de apoio (unidades, lembretes como `M/S · TEMPO`).

| Onde | Altura das letras (tamanho no desenho) |
|---|---|
| Título do painel | 4 mm |
| Nome do grupo, nome de um controle | 2,8 a 3,2 mm |
| Legenda dos lados de um controle (`ANTES` / `DEPOIS`) | 2,4 a 2,6 mm |
| Legenda de apoio | 1,9 a 2,4 mm |

## Cores das luzes

Sempre com o mesmo significado:

| Cor | Significa | Exemplos |
|---|---|---|
| Verde | Sistema ligado, tudo normal; o modo assumiu | SAS, RCS, trem baixado; modo do SAS segurando |
| Azul | Armado: escolhido, mas ainda não assumiu | Modo do SAS com a nave virando para o marcador; ALT do piloto automático subindo até a altitude |
| Branco | Informação, modo escolhido | Página da tela |
| Âmbar | Atenção | Combustível baixo, script armado, pedido recusado |
| Vermelho | Perigo | ABORT, script abortado |

**A luz mostra o estado do jogo**, nunca a posição da chave nem o toque. O azul e o verde seguem os modos do piloto automático do Airbus: azul armado, verde ativo.

**Exceção: cores do KSP** onde a cor diz *qual* coisa é, e não um estado. Nos eixos do nó de manobra: verde-amarelo `#c6e04a` para o pró-grado, magenta `#d24fe0` para o normal e ciano `#40c9e3` para o radial, como as alças do nó no jogo.

## Peças

Sempre as mesmas peças, no mesmo tamanho, para os painéis combinarem e as peças servirem em qualquer lugar. Medidas de catálogo, a conferir no paquímetro.

| Peça | Na frente | Furo | Para quê |
|---|---|---|---|
| [Korry](korry/README.md) | 21,9 × 21,9 mm, passo de 25,5 mm | 23 × 23 mm | Tudo que liga, desliga ou escolhe e tem um estado no jogo: a legenda acesa é o estado. Nos modos do SAS, a legenda é o marcador da navball, com a palavra embaixo |
| Botão de 16 mm sem trava (R16-503) | anel Ø 20 mm, cabeça Ø 13 mm | Ø 16 mm, com um lado reto a 15 mm (furo em D) | Ações sem estado para mostrar: action groups, ANT e PROX, páginas da tela, FOTO |
| LED de 5 mm no suporte de plástico com porca | anel Ø 9 mm | Ø 6,5 mm | Mostrar um estado sem gastar um botão: os modos do piloto automático (verde), o ESTOL (vermelho, piscando), o modo do sidestick (branco) |
| Barra de 10 LEDs | 25,4 × 10,16 mm | 25,6 × 10,4 mm | Uma quantidade: o que resta de combustível, oxidante, monopropelente e eletricidade, e a mochila da EVA |
| Encoder EC11 com knob de alumínio | knob Ø 30 mm | Ø 7 mm | Ajustar um valor. Horário soma, anti-horário tira, com um arco `-` / `+` gravado em volta |
| Chave rotativa, 12 posições com batente | knob de ponteiro Ø 22 mm | Ø 10 mm | Escolher entre poucas opções fixas, com a legenda gravada em volta |
| Tecla basculante KCD1 com mola para o centro | 21 × 15 mm | 19 × 13 mm | Mover para um lado ou outro, como o WARP. Segurando, repete |
| Potenciômetro deslizante de 60 mm | rasgo de 74 × 6 mm, alavanca impressa | rasgo de 64 × 3 mm | O acelerador |
| Joystick de 3 eixos com botão | flange de ~50 mm | a medir | O sidestick |
| Botão de 22 mm com anel de LED | Ø 25 mm | Ø 22 mm | STAGE e ABORT, debaixo de capa transparente |
| Capa transparente para botão de 22 mm | 39 × 34 mm | colada | STAGE e ABORT |
| Capa impressa para o botão de 16 mm | 24 × 40 mm | a desenhar | CARREGAR e REVERTER, que perdem o voo atual |
| Capa impressa para korry | 27,5 × 28,5 mm | colada | IVA |

- **3 mm de borda a borda** entre peças vizinhas, no mínimo.
- **Botão de 16 mm: 23 mm de centro a centro** entre vizinhos, no mínimo (o anel de 20 mm mais 3 mm). Por isso o painel de action groups tem 8 botões, em duas fileiras de 4: 5 por fileira não cabem em 125 mm.
- **Korry: 25,5 mm de centro a centro** entre vizinhos, no mínimo (as bases de 25,3 mm da grade mais 0,2 mm). O `korry.scad` recusa menos que isso.
- **Parafusos das grades dos korry:** cada grupo de korry é preso atrás do painel por uma grade parafusada, com M3 pela frente num furo de 3,2 mm. Os parafusos ficam nas pontas do grupo, os da beira do painel a 6 mm da borda (alinhados com os parafusos de canto), e entram nos desenhos. Não podem cair em cima de outro controle, de uma legenda nem da linha do grupo. As posições estão em [`korry/grades.json`](korry/grades.json) e a explicação em [korry/README.md](korry/README.md#fixação-no-painel).
- **Zona de perigo:** faixa zebrada amarela e preta em volta, com capa de proteção. Só o ABORT.
- **Capa no que não tem volta:** ABORT, STAGE, IVA, CARREGAR e REVERTER.
- **Sem tela nos módulos:** os números vão para a tela multifunção, no meio do cockpit, que troca para a página do módulo em uso.

## Como organizar um painel

As regras que saíram dos desenhos:

1. **Korry só onde a luz diz alguma coisa.** O que não tem estado no jogo para mostrar (os action groups, NOVO, APAGAR) é botão de 16 mm.
2. **Um controle por coisa que se mexe junto.** O Δv nunca é mexido nos três eixos ao mesmo tempo, então é um encoder só, com korry para escolher o eixo.
3. **O controle se mexe como a coisa no jogo.** A tecla do TEMPO fica deitada: para a esquerda o nó volta na órbita, para a direita avança. ANT e PROX, embaixo, no mesmo sentido.
4. **Mostrar o estado sem olhar a tela** quando der de graça: a posição do knob da chave rotativa mostra o passo.
5. **O que se usa mais é maior ou fica mais à mão.**
6. **O que é perigoso fica longe e protegido.**

## Como organizar o cockpit

As regras que decidiram o lugar de cada painel na [versão B](construcao.md#cockpit-versão-b):

1. **A tela no meio, na altura dos olhos,** com os painéis que abrem páginas nela dos lados.
2. **O voo de todo dia no centro, perto das mãos:** os modos do SAS, os sistemas e a ação executiva, embaixo da tela.
3. **Como num avião:** o acelerador na mão esquerda e o sidestick na direita, nas pontas de baixo das asas.
4. **O que se usa junto fica junto:** o editor ao lado do tempo, a câmera ao lado do sidestick.
5. **O que se mexe com calma fica nas pontas de cima:** action groups e editor.
6. **Sem espaço vazio:** juntar controles num painel antes de aumentar a caixa.

## Desenhos

- **Unidades em milímetros**, com as peças no tamanho real e as cotas do painel.
- Feitos com as peças de [`desenho/pecas.js`](desenho/pecas.js); cada painel é um arquivo em [`desenho/paineis/`](desenho/paineis/), e `node hardware/desenho/desenhar.js` gera o SVG em `hardware/img/`. Como fazer um painel novo: [desenho/README.md](desenho/README.md).
- O desenho mostra o painel como ele fica ligado: o korry do estado atual aceso, o knob numa posição.

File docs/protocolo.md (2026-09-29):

# Protocolo serial v0 (texto)

Protocolo entre o computador de bordo (a ponte, `bridge/ponte.py`) e as placas (hoje, o Mega com `firmware/painel/painel.ino`). Os nomes (`STAGE`, `SAS`, `GEAR`...) vêm das tabelas `ENTRADAS` e `LEDS` do firmware e dos dicionários `BOTOES` e `SISTEMAS` da ponte; um controle novo entra nos dois lados. É texto puro, para dar para testar e depurar pelo Serial Monitor. A tela multifunção usa o mesmo formato, com mensagens próprias: ver [a última seção](#tela-multifunção-mikromedia). A versão binária (v1, com COBS e CRC) vem na fase 5.

## Camada física e enquadramento

- Serial pela USB, **115200 baud**, 8N1.
- Texto ASCII, **uma mensagem por linha**, terminada em `\n`. Um `\r` antes do `\n` é ignorado.
- Formato: palavras separadas por **um** espaço, como `READY`, `ALT 1234` ou `SW GEAR 1`. Maiúsculas e minúsculas fazem diferença.
- Linhas vazias são ignoradas. Linhas com mais de 31 caracteres são descartadas inteiras.

## Mensagens

### Painel → ponte

| Mensagem | Quando | Significado |
|---|---|---|
| `READY` | Ao terminar de ligar (inclusive depois de um reset) | O painel está pronto para receber. Tudo o que foi enviado antes disso se perdeu. |
| `BTN <nome> 1` | Um botão foi apertado | Enviada **uma vez por mudança**, já sem trepidação (debounce de 20 ms) |
| `BTN <nome> 0` | Um botão foi solto | idem |
| `SW <nome> 1` | Uma chave foi ligada (para cima) | idem |
| `SW <nome> 0` | Uma chave foi desligada (para baixo) | idem |
| `ERR <linha>` | Chegou uma linha que o painel não reconhece | Devolve a linha recebida, para ajudar a depurar |

Botões hoje: `STAGE` e `ABORT`. Chaves hoje: `SAS`, `RCS`, `GEAR`, `LIGHTS` e `BRAKES`.

### Ponte → painel

| Mensagem | Valores | Efeito no painel |
|---|---|---|
| `SAS <0\|1>` | `0` desligado, `1` ligado | LED do SAS e linha "SAS" do LCD |
| `RCS <0\|1>` | idem | LED do RCS |
| `GEAR <0\|1>` | `0` recolhido, `1` baixado | LED do trem de pouso |
| `LIGHTS <0\|1>` | `0` apagadas, `1` acesas | LED das luzes |
| `BRAKES <0\|1>` | `0` soltos, `1` acionados | LED dos freios |
| `ALT <metros>` | Inteiro com sinal, 32 bits | Linha "Alt" do LCD |

## Comportamento

- **Reset ao abrir a porta.** Abrir a serial reinicia o Mega, que leva cerca de 2 s para voltar. A ponte espera o `READY` antes de enviar qualquer coisa. Se receber `READY` no meio do voo, o painel reiniciou, e a ponte reenvia o estado.
- **Frequência de envio.** A ponte envia `ALT` 10 vezes por segundo, mesmo que a altitude não mude. Cada estado (`SAS`, `RCS`...) vai quando muda, e todos vão também uma vez por segundo, caso alguma mensagem tenha se perdido.
- **Chaves: a posição é o estado desejado.** `SW GEAR 1` quer dizer "a chave do trem foi para cima: baixe o trem". A ponte leva o sistema para a posição da chave. Se o jogo mudar o sistema por conta própria (ex.: SAS pela tecla **T**), o LED mostra o estado real, e a chave fica fora de posição até ser mexida de novo.
- **Posição inicial das chaves não é enviada.** O painel só avisa quando alguém mexe numa chave, nunca ao ligar. Assim, ligar o painel ou reiniciar a ponte nunca muda nada no jogo sozinho.
- **Sinal.** Se o painel passar **1 s** sem receber nenhuma mensagem válida, considera que está sem sinal: apaga todos os LEDs, mostra `--` no LCD e "Ponte: sem sinal". A primeira mensagem válida que chegar restabelece o sinal. Com isso, o painel nunca mostra um dado velho como se fosse atual.
- **Botões e chaves fora da cena de voo.** Enquanto não há nave ativa, a ponte lê e **descarta** as mensagens de botão e de chave. Um STAGE apertado no hangar não fica guardado para disparar quando o foguete chegar à plataforma.
- **Quem manda no estado.** O painel só relata o que aconteceu (ex.: "o botão foi apertado"). É a ponte que decide o que fazer, e é o jogo que confirma o resultado. Os LEDs mostram o estado no jogo, não o que o painel pediu.

## Tela multifunção (mikromedia)

Protocolo entre a ponte da tela (`bridge/mfd.py`) e a mikromedia for ARM, com o firmware de `firmware/mfd/` ([mikromedia.md](mikromedia.md)). O simulador (`bridge/mfd_simulador.py`) e a página do celular seguem estas mesmas regras. Roteiro e testes: [mfd.md](mfd.md).

A camada física e o enquadramento são os mesmos do painel: 115200 baud, uma mensagem por linha, no máximo 31 caracteres, e `ERR <linha>` para o que a tela não reconhece. Na placa, a serial é a porta PROG, onde o DTR reinicia a placa: a ponte abre a porta com o DTR e o RTS desligados e dá um pulso no DTR, como a Arduino IDE faz com o Mega.

No **celular** (`bridge/mfd_celular.py`), as mesmas linhas vão por HTTP, pelo Wi-Fi:

- ponte → celular: a página abre `GET /eventos`, um fluxo *Server-Sent Events* que fica aberto, e cada linha do protocolo chega como um evento (`data: ALT 84321`);
- celular → ponte: cada linha vai num `POST /linha`, com a linha no corpo (no máximo 64 bytes);
- a página manda `READY` sempre que o fluxo de eventos abre, inclusive quando reconecta sozinha.

### Tela → ponte

| Mensagem | Quando | Significado |
|---|---|---|
| `READY` | Ao terminar de ligar | A tela está pronta. A ponte reenvia tudo. |
| `ID <4 dígitos hex>` | Logo depois do `READY`, só a placa | O código do controlador da tela, lido no registrador 0 (ex.: `ID 0047`). Só para diagnóstico: a ponte mostra no terminal |
| `TOQUE <nome>` | Um botão da tela foi tocado | Uma vez por toque. Botões hoje: `SAS` e `RCS` (redondos, embaixo da navball) e `MODO` (a caixa da velocidade). |
| `ERR <linha>` | Chegou uma linha que a tela não reconhece | Devolve a linha recebida |

### Ponte → tela

Ângulos e velocidades vão em **décimos**, como inteiros: 45,3° vira `453`, e 345,6 m/s vira `3456`.

**Estados**, que vão quando mudam e também 1 vez por segundo:

| Mensagem | Valores | Efeito na tela |
|---|---|---|
| `MODO <SUP\|ORB\|ALVO>` | Velocidade em relação à superfície, à órbita ou ao alvo | Título da caixa da velocidade e o que o painel de baixo mostra. Vai **antes** dos números |
| `SAS <0\|1>`, `RCS <0\|1>` | `1` = ligado no jogo | Cor do botão: verde = ligado |

**Navball.** Cada marcador é uma direção no mundo, em `<pitch> <rumo>`; a tela desenha também o marcador oposto, do outro lado da bola. `OFF` esconde os dois.

| Mensagem | Direção | Marcadores | Frequência |
|---|---|---|---|
| `ATT <pitch> <rumo> <rolagem>` | pitch de -900 a 900; rumo de 0 a 3599 (0 = norte, 900 = leste); rolagem de -1800 a 1800 | A bola e os números do rumo e do pitch pintados nela | 20 por segundo |
| `PRO <p> <r>` ou `PRO OFF` | Do movimento, no modo da navball. `OFF` com a nave parada (menos de 0,5 m/s) | Pró-grado e retrógrado, em amarelo | 10 por segundo |
| `NRM <p> <r>` ou `NRM OFF` | Normal à órbita (numa órbita para leste, aponta para o norte). `OFF` no modo `ALVO`, parado ou andando na vertical | Normal e antinormal, em roxo | 10 por segundo |
| `RDL <p> <r>` ou `RDL OFF` | Radial para fora: perpendicular ao movimento, do lado de fora do planeta. `OFF` como o `NRM` | Radial para fora e para dentro, em ciano | 10 por segundo |
| `TGT <p> <r>` ou `TGT OFF` | Do alvo. `OFF` sem alvo ou com o alvo a menos de 1 m | Alvo e anti-alvo, em rosa, em qualquer modo | 10 por segundo |
| `MNV <p> <r>` ou `MNV OFF` | Da queima que falta no próximo nó de manobra. `OFF` sem nó ou com a queima terminada | Nó de manobra, em azul (sem oposto) | 10 por segundo |
| `FBW <p> <r>` ou `FBW OFF` | O caminho que o fly by wire (`scripts/fbw.py`) persegue com o piloto automático ou a trava de altitude. `OFF` sem o FBW voando, ou voando na mão | Ponto do FBW: quatro cantos de um quadrado, em verde (sem oposto), em qualquer modo | 10 por segundo |

**Números**, que valem só até chegar um `MODO` diferente, exceto `VV` e `ACEL`:

| Mensagem | Valores | Efeito na tela | Frequência |
|---|---|---|---|
| `ALT <metros>` | Acima do nível do mar | Caixa `ALT` | 10 por segundo |
| `RAD <metros>` | Acima do chão, ou do mar se ele estiver mais perto. Vai no lugar do `ALT` perto do chão | Caixa `RADAR` | 10 por segundo |
| `VEL <décimos de m/s>` | Velocidade no modo da navball | Caixa da velocidade | 10 por segundo |
| `VV <décimos de m/s>` | Velocidade vertical: positiva subindo, negativa descendo. Em todo modo | Barra da direita | 10 por segundo |
| `ACEL <0 a 100>` | Acelerador, em % | Barra da esquerda | 10 por segundo |
| `DIST <metros>` ou `DIST OFF` | Distância até o alvo. Só no modo `ALVO` | Painel: `DIST` | 10 por segundo |
| `AP <metros>` ou `AP OFF` | `OFF` numa trajetória de escape, que não tem apoastro. Só no modo `ORB` | Painel: `AP` | 2 por segundo |
| `PE <metros>` ou `PE OFF` | Negativo quando a órbita passa por dentro do planeta. Só no modo `ORB` | Painel: `PE` | 2 por segundo |
| `TAP <segundos>` ou `TAP OFF` | Tempo até o apoastro. Só no modo `ORB` | Painel: `T-00:27:53` ao lado do `AP` | 2 por segundo |
| `TPE <segundos>` ou `TPE OFF` | Tempo até o periastro. Só no modo `ORB` | Painel: ao lado do `PE` | 2 por segundo |

Distâncias e tempos são inteiros de 32 bits. Acima de 2,1 milhões de km, o que só acontece com planetas distantes, `DIST`, `AP` e `PE` vão como `OFF`, e a tela mostra `---`.

### Scripts → ponte da tela

Um script de voo pode mandar coisas para a tela sem depender da ponte. O fly by wire põe um marcador na navball e manda no mesmo pacote o estado do painel de sistemas ([abaixo](#ponte-da-tela--fly-by-wire)); o pouso manda o estado dele para a página POUSO ([abaixo](#pouso--ponte-da-tela)).

- O script manda a **própria linha do protocolo da tela** (`FBW 52 2700` ou `FBW OFF`), num pacote **UDP** para a porta **50100** do computador da ponte, 10 vezes por segundo. Sem a ponte aberta, o pacote se perde e o script segue voando.
- A ponte (`bridge/mfd.py`) escuta em todas as redes (o script pode rodar noutro computador), confere a linha e a repassa para a tela na vez dos marcadores. Linhas que não entende, ela mostra no terminal e descarta.
- Se o script parar de mandar por **1 s** (fechou ou travou), a ponte manda `FBW OFF`.

### Comportamento

- **A tela só desenha.** Toda conta que envolve o jogo é feita na ponte, e a tela recebe as direções prontas. A imagem não vai pela serial: um quadro de 320x240 com 16 bits por ponto tem 150 KB, o que levaria 13 s a 115200 baud. A atitude inteira cabe numa linha de 20 caracteres, e tudo junto dá uns 2 KB/s, menos de 20% da serial.
- **Marcadores a 10 por segundo, atitude a 20.** Os marcadores são direções fixas no mundo, que mudam devagar; quem faz eles andarem na bola é a atitude da nave. A tela reprojeta todos a cada `ATT`.
- **Sinal.** Se a tela passar **1 s** sem receber nenhuma mensagem válida, mostra `SEM SINAL` na navball, `---` nos números, esvazia as barras e apaga os botões. O `ALT` (ou o `RAD`), que vai 10 vezes por segundo, serve de "estou vivo". Fora da cena de voo a ponte não manda nada, então a tela também mostra `SEM SINAL`.
- **O botão mostra o estado do jogo, não o toque**, como os LEDs do painel. `TOQUE SAS` faz a ponte inverter o SAS, e o botão só fica verde quando o jogo confirma. Se a nave não tem SAS, o botão continua apagado, e está certo.
- **O que depende do modo.** Altitude, `VEL`, as duas barras e os marcadores aparecem sempre. O painel de baixo mostra `AP` e `PE` com o tempo até cada um no `ORB` e `DIST` no `ALVO`; no `SUP` ele não aparece, porque a velocidade vertical já está na barra. Normal e radial não existem no `ALVO`; o ponto do FBW, o alvo e a manobra aparecem em qualquer modo. Quando o `MODO` muda, a tela apaga os números do modo antigo e os marcadores pró-grado, normal e radial, e a ponte manda os novos na mesma hora, logo depois do `MODO`.
- **Altitude pelo radar.** A ponte manda `RAD` no lugar de `ALT` quando o radar fica abaixo de 5 km, e só volta ao `ALT` acima de 5,5 km. Essa folga evita ficar trocando quando o terreno sobe e desce perto do limite.
- **O modo é da ponte**, e ela troca sozinha como a navball do KSP:
  - `ORB` quando a nave sobe acima de 6% do raio do planeta (36 km em Kerbin), e `SUP` quando desce abaixo de 5,5% (33 km);
  - `ALVO` quando um alvo é escolhido no jogo (uma nave, uma porta de acoplamento ou um planeta), ou trocado por outro; sem alvo, volta para `SUP` ou `ORB` conforme a altitude;
  - `TOQUE MODO` passa para o próximo modo: `SUP` → `ORB` → `ALVO` (se houver alvo) → `SUP`. A escolha vale até a próxima troca automática.

## Editor de nós de manobra

Linhas do editor da fase 4 ([docs/manobras.md](manobras.md)). Hoje quem manda é a página `bridge/celular/manobras.html`, por HTTP (`POST /linha`, uma linha por pedido); quando o painel existir, ele manda as linhas pela serial, com as diferenças do [painel](#no-painel) abaixo. Tudo é painel → ponte, menos os LEDs dos korry de eixo: os números do nó vão para uma página do editor na tela multifunção, que ainda não tem mensagem própria (a página recebe as tabelas prontas em JSON pelo `GET /estado`).

| Mensagem | Quando | Significado |
|---|---|---|
| `INC <nome> <passos>` | Uma chave de ajuste foi para `+` ou `-` | Passos com sinal (`+` positivo). Nomes: `PRO`, `NRM`, `RAD`, `TEMPO` |
| `BTN <nome> 1` | Um botão foi apertado | |
| `BTN <nome> 0` | Um botão foi solto | Ignorada pelo editor |

- **Teclas de ajuste:** teclas basculantes com mola para o centro, como a do TIME WARP, (ON)-OFF-(ON), uma por ajuste, com duas entradas cada (`+` e `-`). O painel manda `INC <nome> 1` (ou `-1`) na hora em que a tecla sai do centro e, segurando, repete a cada 100 ms depois de 400 ms, como a página. **A repetição fica no firmware**, e não na ponte: se a ponte repetisse até chegar o "soltei", um "soltei" perdido deixaria o nó andando sozinho. Várias repetições acumuladas podem ir numa linha só (`INC PRO 3`).
- **Botões:** `PASSO` (um só para os quatro ajustes), `NOVO`, `APAGAR`, `ANT`, `PROX` e `CIRC`. `MAPA` fica na seção da câmera do painel, mas vem para o editor com o mesmo nome.
- **Temporários**, até o joystick mexer na câmera do mapa no modo CÂMERA: `CAM_ESQ`, `CAM_DIR`, `CAM_CIMA`, `CAM_BAIXO`, `CAM_PERTO`, `CAM_LONGE` e `CAM_FOCO`.
- Uma linha que o editor não reconhece aparece na página como `ERR <linha>`.

### No painel

O painel do editor ([hardware/construcao.md](../hardware/construcao.md#painel-do-editor-de-manobras)) tem um encoder só para o Δv, e não um par `+`/`-` por eixo. **Planejado, ainda não feito na ponte:**

| Mensagem | Quando | Significado |
|---|---|---|
| `BTN PRO 1`, `BTN NRM 1`, `BTN RAD 1` | Um korry de eixo foi apertado | Escolhe o eixo que o encoder mexe. Um nó novo começa com `PRO` |
| `ENC DV <cliques>` | O encoder girou | Cliques com sinal, horário positivo. A ponte multiplica pelo passo e soma no eixo escolhido. Vários cliques podem ir numa linha só |
| `INC TEMPO <passos>` | A tecla do TEMPO foi para um lado | Como hoje, com a repetição no firmware |
| `SW PASSO <0 a 3>` | A chave rotativa mudou de posição | O passo pela posição (0 = 0,1 m/s e 1 s), no lugar do `BTN PASSO`. O painel manda a posição também ao ligar |

- **O eixo escolhido fica na ponte**, como o estado de qualquer sistema. O painel não sabe qual é; a ponte acende o LED do korry certo, pelo mesmo caminho dos outros LEDs.
- **A página do celular** continua mandando `INC PRO`, `INC NRM` e `INC RAD` até ganhar os botões de eixo e o par `-`/`+` do encoder. A ponte aceita as duas formas.

## Painel de sistemas de controle

Linhas do painel de sistemas de controle ([desenho](../hardware/construcao.md#painel-de-sistemas-de-controle)): os modos do SAS, SAS, RCS, FBW, trava de altitude e o encoder do [piloto automático](../README.md#piloto-automático-de-avião). Quem responde é a ponte da tela (`bridge/mfd.py`, com a lógica em `bridge/sistemas.py`), que já tem o jogo, a tela e o fly by wire. Enquanto o painel não existe, a página de botões `bridge/celular/painel.html` manda as mesmas linhas, pelo mesmo caminho da tela no celular (`POST /linha` e `GET /eventos`, na porta 8001), e manda `READY` ao abrir, para receber todas as luzes. Uso e testes em [docs/mfd.md](mfd.md#painel-de-sistemas-de-controle).

### Painel → ponte

| Mensagem | Quando | Significado |
|---|---|---|
| `BTN SAS_<modo> 1` | Um korry de modo foi apertado | Escolhe o modo do SAS. Modos: `ESTAB`, `MAN`, `PRO`, `RETRO`, `NRM`, `ANRM`, `RFORA`, `RDENTRO`, `ALVO`, `AALVO`. Com o SAS desligado, liga junto. Um modo que o jogo não aceita não muda nada |
| `BTN SAS 1`, `BTN RCS 1` | O korry foi apertado | Inverte o sistema no jogo |
| `BTN FBW 1` | O korry FBW foi apertado | Liga ou desliga o FBW, como o botão do joystick |
| `BTN TRAVA 1` | O korry TRAVA ALT foi apertado | Trava a altitude do momento, ou destrava |
| `ENC AP <cliques>` | O encoder girou | Cliques com sinal, horário positivo. Vários cliques podem ir numa linha só |
| `BTN AP 1`, `BTN AP 0` | O encoder foi apertado e solto | Solto antes de 1 s: escolhe ou sai da linha do menu. Segurado 1 s: liga ou desliga o modo da linha, na hora, sem esperar soltar |

### Ponte → painel e tela

As mesmas linhas acendem os LEDs do painel e desenham as páginas da tela. Vão quando mudam e também 1 vez por segundo, calculadas 20 vezes por segundo. A tela não recebe `SEMEC`, `SEMMP` nem `GPWS`, e o painel não recebe `SASE`, `APV`, `APC` nem `PAG`.

| Mensagem | Valores | No painel | Na tela |
|---|---|---|---|
| `SASM <modo> <A\|V>` ou `SASM OFF` | O modo do SAS no jogo e a cor: `A` (azul) com a nave ainda virando para o marcador, `V` (verde) com ela a menos de 2° dele. `OFF` com o SAS desligado | O korry do modo, na cor | O modo na roda do SAS |
| `SASE <décimos>` ou `SASE OFF` | Ângulo entre o nariz e o marcador do modo. `OFF` sem SAS ou sem marcador | — | `ERRO` na página do SAS |
| `SEMEC <0\|1>`, `SEMMP <0\|1>` | `1` com o SAS ligado sem carga elétrica, ou o RCS ligado sem monopropelente | Metade de baixo do SAS e do RCS, em âmbar | — |
| `LEI <FBW\|DIRETA\|CHAO\|OFF>` | A lei do fly by wire: `FBW`, `DIRETA` no ar, `CHAO` (direta no chão). `OFF` sem o `fbw.py` aberto | `FBW` verde; `DIRETA` âmbar | Linha do FBW, na página do piloto |
| `TRAVA <metros>` ou `TRAVA OFF` | A altitude travada pelo FBW | TRAVA ALT verde | Linha do FBW |
| `ESTOL <0\|1>` | `1` com o aviso de estol do FBW: o ângulo de ataque perto do limite da asa. Só aviso, o FBW não mexe em nada | Luz ESTOL vermelha, piscando | Alarme sonoro: dois bipes por segundo |
| `GPWS <0\|1\|2>` | Os [avisos de voo](avisos.md) da ponte: `0` nenhum, `1` um aviso âmbar (SINK RATE, TOO LOW, DON'T SINK, BANK ANGLE, OVERSPEED), `2` um vermelho (TERRAIN, PULL UP). A voz sai pela ponte, não pela tela | `1`: GPWS âmbar; `2`: PULL UP vermelha, piscando | — |
| `APL <HDG\|ALT\|VS> <0\|1\|2>` | Modo do piloto: `0` desligado, `1` ligado, `2` armado (o ALT subindo ou descendo até a altitude) | Luz do modo, verde com `1` ou `2` | Azul armado, verde ligado |
| `APV <HDG\|ALT\|VS> <valor>` | O valor escolhido: rumo em graus (0 a 359), altitude em metros, velocidade vertical em décimos de m/s | — | O valor da linha |
| `APC <HDG\|ALT\|VS> <0\|1>` | A linha do cursor, e `1` se ela está escolhida (girar muda o valor) | — | O cursor, ou a caixa âmbar no valor |
| `PAG <NAV\|SAS\|AP\|POUSO>` | A página que a tela mostra. `POUSO` é a do [painel de scripts](#painel-de-scripts) | — | Troca a página |

- **A página é da ponte.** Apertar um modo, o SAS ou o RCS abre a página `SAS`; mexer no encoder abre a `AP`. Uns 10 s depois do último toque no painel, a ponte manda `PAG NAV`.
- **O valor muda de 1 em 1** (1°, 10 m, 0,1 m/s) girando devagar, e de 10 em 10 girando rápido: com mais de um clique numa linha, ou menos de 80 ms desde a última.
- **O menu é da ponte**, como o eixo do editor de manobras: o painel só manda cliques e apertos.

### Ponte da tela ⇄ fly by wire

O `fbw.py` manda por UDP para a porta **50100** da ponte da tela, 10 vezes por segundo, num pacote só, uma linha por vez: o ponto (`FBW`), a lei (`LEI`), a trava (`TRAVA`), o aviso de estol (`ESTOL`) e os modos do piloto (`APL`), como na tabela acima. A ponte responde para o endereço de onde o pacote veio:

| Mensagem | Quando | Significado |
|---|---|---|
| `CMD FBW`, `CMD TRAVA` | Os korry FBW e TRAVA ALT | Liga ou desliga |
| `CMD HDG`, `CMD ALT`, `CMD VS` | O encoder segurado 1 s | Liga ou desliga o modo |
| `APV <HDG\|ALT\|VS> <valor>` | Quando muda e 1 vez por segundo | O valor escolhido no menu |

Sem notícia do `fbw.py` por 1 s, a ponte manda `LEI OFF`, `TRAVA OFF`, `ESTOL 0` e os `APL` em `0`, e não manda nada a ele. O `fbw.py` só liga um modo voando na lei do FBW; o que ele faz em cada modo está em [docs/fbw.md](fbw.md#piloto-automático).

## Painel de scripts

Linhas do painel de scripts ([desenho](../hardware/construcao.md#painel-de-scripts)): um korry por script, e por enquanto só o POUSO. Quem responde é a ponte da tela (`bridge/mfd.py`, com a lógica em `bridge/painel_scripts.py`), pelo mesmo caminho do painel de sistemas: enquanto o painel não existe, o korry fica na página de botões `bridge/celular/painel.html`, na porta 8001. Uso e testes em [docs/mfd.md](mfd.md#painel-de-scripts-e-a-página-do-pouso).

### Painel → ponte

| Mensagem | Quando | Significado |
|---|---|---|
| `BTN POUSO 1` | O korry POUSO foi apertado | Começa a contar. Com 5 s apertado, a ponte abre o `scripts/pouso.py`; com o pouso voando, aborta |
| `BTN POUSO 0` | O korry foi solto | Solto antes de 5 s, não faz nada. Depois dos 5 s, continuar apertado não conta de novo: vale só depois de soltar |

- **O tempo é da ponte**, como no aperto longo do encoder do piloto automático: o painel só manda o aperto e a soltura.
- **Um script ativo por vez.** Com um script voando, segurar o korry de outro não faz nada.
- Os lugares vagos do painel não mandam nada até ganharem um script.

### Ponte → painel e tela

Vai quando muda e também 1 vez por segundo, calculada 20 vezes por segundo, para o painel e para a tela.

| Mensagem | Significado | No korry | Na tela |
|---|---|---|---|
| `SCR POUSO OFF` | Parado | Apagado | `PARADO` |
| `SCR POUSO LIGA <s>` | Segurando para abrir; faltam `<s>` segundos (5 a 1) | Âmbar piscando | `SEGURE 3 S / PARA POUSAR` |
| `SCR POUSO ATIVO` | O script está voando | Verde | A fase do pouso |
| `SCR POUSO DESL <s>` | Segurando para abortar; faltam `<s>` segundos | Verde e âmbar piscando | `SEGURE 3 S / PARA ABORTAR` |
| `SCR POUSO FIM` | O script terminou e a nave pousou. Por 10 s, depois `OFF` | Apagado | `POUSADA` |
| `SCR POUSO ABORT` | Abortado pelo piloto. Por 10 s | Vermelho | `ABORTADO` |
| `SCR POUSO FALHA` | O script parou sem pousar (sem nave, nave perdida, erro). Por 10 s | Vermelho | `FALHOU` |

- **A página POUSO** abre na tela no primeiro aperto do korry, fica aberta enquanto o script voa e até 10 s depois do fim. Um toque no painel de sistemas no meio do pouso abre a página dele, que volta para a do pouso 10 s depois, e não para a navball.
- **O script roda num processo próprio**, o mesmo da linha de comando (`python scripts/pouso.py <IP do KSP> --tela 127.0.0.1`). Abortar manda o Ctrl+C (no Windows, o `CTRL_BREAK`, que o script transforma em Ctrl+C): o script corta o motor e devolve a nave antes de sair. Se ele não sair em 5 s, a ponte encerra o processo. Fechar a ponte aborta o script.
- **O código de saída do script** diz o fim: `0` pousou (`FIM`), `130` interrompido, e qualquer outro, `FALHA`. O que o script escreve aparece no terminal da ponte, com `[pouso]` na frente.

### Pouso → ponte da tela

O `scripts/pouso.py` manda por UDP para a porta **50100** da ponte da tela, 10 vezes por segundo, num pacote só, uma linha por vez. A ponte confere cada linha e repassa para a tela. Sem notícia do pouso por 1 s, a ponte manda `POU OFF`, e a tela apaga os números. O pouso não recebe nada da ponte: o aborto vem pelo Ctrl+C.

| Mensagem | Valores | Na página POUSO |
|---|---|---|
| `POU FASE <QUEDA\|QUEIMA\|TOQUE\|POUSADA>` | A fase da guiagem: caindo sem motor, freando, descida final a 2 m/s, pousada | O indicador embaixo à esquerda: azul na queda (armado), verde depois. O trem aparece baixado na queima |
| `POU ALT <décimos de m>` | Altura do pé da nave até o chão | `ALT` e a altura da nave no desenho, em escala logarítmica até 10 km |
| `POU VV <décimos de m/s>` | Velocidade vertical, negativa descendo | `VEL`, sem o sinal |
| `POU MOTOR <0 a 100>` | Acelerador, em % | `MOTOR` e o tamanho da chama |
| `POU TWR <centésimos>` | Empuxo/peso com o ar do chão | `TWR` |
| `POU FREADA <%>` ou `POU FREADA OFF` | Quanto do empuxo máximo a freada precisa agora. `999`: nem o motor todo dá. `OFF`: sem motor ativo | A barra `FREADA` |
| `POU IGN <%>` | A freada em que o motor acende (85%) | A marca âmbar na barra |
| `POU SAS <RETRO\|ESTAB>` | O modo do SAS que a guiagem pediu | `SAS` |
| `POU INCL <graus>` | Ângulo entre o nariz e a vertical | `INCL` |
| `POU AVISO <EMPUXO\|MOTOR\|NARIZ\|OFF>` | O aviso mais importante: empuxo insuficiente, nenhum motor ativo, nariz longe da vertical | O aviso em vermelho, piscando |
| `POU OFF` | Só da ponte para a tela: o pouso não está mandando | Apaga os números e a nave |

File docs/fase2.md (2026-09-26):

# Fase 2: painel de controle

**Esta etapa:** chaves de SAS, RCS, trem de pouso, luzes e freios, botões STAGE e ABORT, e um LED de estado por chave, tudo direto nos pinos do Mega. Joystick e acelerador entram numa próxima etapa: serão o Logitech Extreme 3D Pro, na USB do Pi ([hardware/construcao.md](../hardware/construcao.md#joystick-logitech-extreme-3d-pro)).

**Pronto quando:** cada chave comanda o seu sistema no jogo, os LEDs acompanham o jogo (inclusive quando algo muda pelo teclado) e STAGE e ABORT funcionam pelo painel.

O código é o mesmo da fase 1, ampliado: [`firmware/painel/painel.ino`](../firmware/painel/painel.ino) e [`bridge/ponte.py`](../bridge/ponte.py). As mensagens novas estão em [`docs/protocolo.md`](protocolo.md).

## Material

- 5 chaves alavanca ON-OFF
- 1 botão para o ABORT, de preferência com capa de proteção (o STAGE da fase 1 continua)
- 4 LEDs e 4 resistores de 220 Ω (o LED do SAS da fase 1 continua)

O LCD, o botão STAGE e o LED do SAS ficam onde estão.

## Montagem

Todos os botões e chaves ligam **entre o pino e o GND, sem resistor**: o firmware usa o pull-up interno. Todos os LEDs ligam como na fase 1: `pino ──[220 Ω]──(+)LED(−)── GND`.

| Controle | Tipo | Pino | LED |
|---|---|---|---|
| STAGE | botão | 2 (já montado) | — |
| ABORT | botão | 3 | — |
| SAS | chave | 22 | 8 (já montado) |
| RCS | chave | 24 | 9 |
| GEAR (trem de pouso) | chave | 26 | 10 |
| LIGHTS (luzes) | chave | 28 | 11 |
| BRAKES (freios) | chave | 30 | 12 |

```
Barra dupla no fim do Mega (vista de cima):     Cada chave:

   5V   5V                                        pino ──[chave]── GND
   22   23   ← SAS                                (para cima = contato fechado)
   24   25   ← RCS
   26   27   ← GEAR                             Cada LED:
   28   29   ← LIGHTS
   30   31   ← BRAKES                             pino ──[220 Ω]──(+)LED(−)── GND
   ..   ..
   52   53
  GND  GND   ← GND para a protoboard
```

- **As chaves usam só os pinos pares** (22, 24... 30) para ficarem todas na mesma fileira da barra dupla.
- **Faça um barramento de GND** na protoboard (a linha azul, −) e ligue nele todos os contatos e LEDs.
- **Chave com 2 terminais (ON-OFF):** um terminal no pino e o outro no GND.
- **Chave com 3 terminais:** o terminal do meio (comum) no GND e um dos lados no pino.
- **Para cima = ligada.** Monte a chave de modo que, para cima, ela feche o contato e mande `SW <nome> 1`. Se ficar invertida, vire a chave ou troque o terminal da ponta.
- **Pinos que ficam livres de propósito:** 0 e 1 (serial da USB), 20 e 21 (I2C do LCD) e 50 a 53 (SPI, para os shift registers do futuro).
- **Consumo:** os 5 LEDs juntos puxam uns 70 mA, sem problema para a USB.

## Gravar

Grave o `painel.ino` como na fase 1.

**Confira o `LCD_ENDERECO`.** Se o seu LCD não é `0x27`, troque de novo para o endereço que você achou na fase 1.

Se o `git pull` reclamar de mudanças locais no `painel.ino`, rode `git stash`, depois `git pull`, e troque o endereço de novo.

## Testar sem o KSP, pelo Serial Monitor

115200 baud, final de linha em **Nova linha**.

| Você faz | Resultado esperado |
|---|---|
| Liga a placa, com as chaves em qualquer posição | Só `READY`: a posição inicial das chaves **não** é enviada |
| Sobe e desce a chave do trem | `SW GEAR 1` e depois `SW GEAR 0`, uma mensagem por movimento |
| Repete com cada chave | `SW SAS`, `SW RCS`, `SW LIGHTS`, `SW BRAKES`: confira que cada uma manda o próprio nome |
| Aperta e solta o ABORT | `BTN ABORT 1` e depois `BTN ABORT 0` |
| Digita `RCS 1`, `GEAR 1`, `LIGHTS 1`, `BRAKES 1` | Cada um acende o LED certo, e todos apagam 1 s depois (sem sinal, como na fase 1) |
| Digita `FOO 1` | `ERR FOO 1` |

## Testar com a ponte

Feche o Serial Monitor e rode a ponte, no PC (`python bridge/ponte.py`) ou no Pi (`python ~/cockpit/bridge/ponte.py IP_DO_PC`). Faça `git pull` antes, onde a ponte for rodar.

**Pronto quando:**

- [ ] Cada chave liga e desliga o seu sistema, e o terminal mostra, por exemplo, `GEAR: ligar`.
- [ ] Cada LED acompanha o jogo **também pelo teclado**: **T** (SAS), **R** (RCS), **G** (trem), **U** (luzes) e **segurar B** (freios).
- [ ] **Chave fora de posição:**
  1. Ligue o SAS pela chave.
  2. Desligue pelo **T**: o LED apaga e a chave continua para cima.
  3. Desça e suba a chave: o SAS liga de novo.
- [ ] ABORT dispara o grupo Abort da nave, e o terminal mostra `ABORT!`.
- [ ] Mexer em chaves e botões no hangar não faz nada quando o foguete chega à plataforma.

## Problemas comuns

| Sintoma | Causa provável | Solução |
|---|---|---|
| A chave manda `1` quando está para baixo | Chave invertida | Virar a chave ou usar o outro terminal da ponta |
| Mexer numa chave não mostra nada | Fio no pino errado, ou a chave sem GND | Conferir o pino na tabela e o barramento de GND |
| Uma chave manda o nome de outra | Fios trocados | Conferir a tabela de pinos |
| Várias mensagens num movimento só | Fio frouxo na protoboard | Firmar o fio. O debounce resolve a trepidação da chave, não mau contato |
| Ponte: `O painel não entendeu a mensagem: RCS 1` | O Mega ainda está com o firmware da fase 1 | Gravar o `painel.ino` novo |
| Ponte: `Mensagem desconhecida do painel: SW ...` | A ponte está na versão da fase 1 | `git pull` onde a ponte roda |
| ABORT mostra `ABORT!`, mas nada acontece no jogo | O grupo Abort da nave está vazio | No VAB, em *Action Groups*, pôr ações no grupo **Abort** |
| SAS não liga pela chave e o LED fica apagado | A nave não tem SAS (sem piloto nem núcleo de sonda com SAS) | É o comportamento certo: o LED mostra o jogo |

## Acrescentar um controle

O firmware e a ponte agora são guiados por tabelas:

- **Nova chave com LED** (ex.: um action group):
  - uma linha em `ENTRADAS` e outra em `LEDS`, no `painel.ino`;
  - uma linha em `SISTEMAS`, na `ponte.py`.
- **Novo botão:**
  - uma linha em `ENTRADAS`;
  - uma função em `BOTOES`, na `ponte.py`.

Ainda sobram 34 pinos digitais livres no Mega, fora os reservados, e os 16 analógicos, que também servem como digitais. Quando isso acabar, entram os shift registers ou o MCP23017.

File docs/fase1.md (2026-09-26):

# Fase 1: primeiro circuito fechado

**Pronto quando:** apertar o botão faz o *stage*, o LED acompanha o SAS do jogo e o LCD mostra a altitude.

Durante o desenvolvimento, **o Mega fica ligado na USB do PC** e a ponte também roda no PC. Assim você grava o firmware e testa no mesmo lugar. No último passo, tudo vai para o Pi.

Cada passo termina com algo funcionando. Não pule o critério de "pronto" de cada um.

## Material

- Arduino Mega 2560 e cabo USB-B
- Protoboard e jumpers
- 1 botão
- 1 LED e 1 resistor de 220 Ω (serve de 220 a 330 Ω)
- LCD 20x4 com módulo I2C soldado atrás

## Montagem

```
Botão STAGE:  pino 2 ──[botão]── GND               sem resistor: usa o pull-up interno
LED SAS:      pino 8 ──[220 Ω]──(+)LED(−)── GND     perna longa (+) do lado do resistor
LCD I2C:      SDA → pino 20   SCL → pino 21   VCC → 5V   GND → GND
```

> No Mega, o I2C fica nos pinos **20 (SDA) e 21 (SCL)**. Tutoriais de Arduino Uno usam A4 e A5, e isso não funciona no Mega.

## Onde está o código

| Arquivo | O que é |
|---|---|
| [`firmware/passos/passo1_pisca`](../firmware/passos/passo1_pisca/passo1_pisca.ino) | Passo 1: piscar sem `delay()` |
| [`firmware/passos/passo2_botao`](../firmware/passos/passo2_botao/passo2_botao.ino) | Passo 2: botão com debounce |
| [`firmware/passos/passo3_comandos`](../firmware/passos/passo3_comandos/passo3_comandos.ino) | Passo 3: receber comandos pela serial |
| [`firmware/passos/passo4_i2c_scanner`](../firmware/passos/passo4_i2c_scanner/passo4_i2c_scanner.ino) | Passo 4a: achar o endereço do LCD |
| [`firmware/painel`](../firmware/painel/painel.ino) | Passo 4b: **o firmware do painel** (tudo junto + LCD) |
| [`bridge/ponte.py`](../bridge/ponte.py) | Passo 5: a ponte kRPC ⇄ painel |
| [`docs/protocolo.md`](protocolo.md) | O protocolo v0, mensagem por mensagem |

> Desde a fase 2, o `painel.ino` também lê as chaves e o ABORT e acende mais LEDs ([docs/fase2.md](fase2.md)). Ele continua funcionando com a montagem desta fase: entradas sem nada ligado ficam quietas, e os testes abaixo valem do mesmo jeito.

Os passos são cumulativos: cada sketch acrescenta uma ideia ao anterior, e os comentários explicam o porquê de cada escolha. Leia o código antes de gravar.

## Passo 0: preparar a Arduino IDE

1. **Ferramentas → Placa → Arduino AVR Boards → Arduino Mega or Mega 2560.**
2. **Ferramentas → Porta:** a porta COM do Mega. Se não souber qual é, desconecte o Mega e veja qual porta some da lista.
3. **Ferramentas → Gerenciar bibliotecas:** instale **LiquidCrystal I2C**, de Frank de Brabander.
4. Para abrir um sketch: **Arquivo → Abrir** e escolha o `.ino` dentro da pasta dele. A IDE exige que o arquivo tenha o mesmo nome da pasta.

No Serial Monitor (lupa no canto superior direito), use **115200 baud** e o final de linha em **Nova linha**.

## Passo 1: piscar sem `delay()`

Monte só o LED, abra o `passo1_pisca` e grave (seta → no alto da IDE).

**Pronto quando:** o LED pisca uma vez por segundo e o Serial Monitor mostra quantas voltas o `loop()` dá por segundo. Experimente colocar um `delay(500)` no fim do `loop()` e veja o número despencar.

## Passo 2: botão com debounce

Monte o botão e grave o `passo2_botao`.

**Pronto quando:** cada aperto imprime exatamente um `BTN STAGE 1` e um `BTN STAGE 0`, mesmo apertando rápido. Mude `DEBOUNCE_MS` para `0` e veja a trepidação aparecer.

## Passo 3: receber comandos

Com o LED e o botão montados, grave o `passo3_comandos`.

**Pronto quando:**
- ao abrir o Serial Monitor aparece `READY`;
- `SAS 1` acende o LED e `SAS 0` apaga;
- qualquer outra coisa responde `ERR ...`;
- o botão continua respondendo na hora.

## Passo 4: LCD e o firmware do painel

1. Ligue o LCD e grave o `passo4_i2c_scanner`. Anote o endereço que aparecer (normalmente `0x27` ou `0x3F`).
2. Abra o `painel`. Se o endereço for diferente de `0x27`, troque em `LCD_ENDERECO`. Grave.
3. Se a luz acender mas não aparecer texto, gire o trimpot azul atrás do LCD (contraste).

**Pronto quando**, pelo Serial Monitor:
- a primeira linha do LCD mostra `KSP Cockpit`;
- `SAS 1` acende o LED e mostra `SAS: ligado`;
- `ALT 1234567` mostra `Alt:     1.234.567 m`;
- sem digitar nada por 1 segundo, aparece `Ponte: sem sinal`, o LED apaga e os valores viram `--`.

Com isso, **o painel está completo e testado sem o KSP.**

## Passo 5: a ponte, no PC

1. **Feche o Serial Monitor.** A porta COM só pode ser aberta por um programa de cada vez.
2. No PC, se ainda não tiver instalado: `pip install krpc pyserial`.
3. Abra o KSP, com o servidor kRPC ligado, e rode:
   ```
   python bridge/ponte.py
   ```
   Sem IP, a ponte conecta no kRPC do próprio PC. A porta do Mega é detectada sozinha. Se não for, use `--porta COM5`, trocando pelo nome da sua porta.

Saída esperada:

```
Abrindo o painel em COM5...
Painel pronto.
Conectando ao kRPC em 127.0.0.1... (se demorar, aceite a conexão no jogo)
Nenhuma nave ativa. Aguardando a cena de voo...
Nave: Kerbal X
```

**Pronto quando** (este é o critério da fase):
- o botão faz o *stage* (aparece `STAGE!`);
- o LED acompanha o SAS, inclusive quando você liga e desliga pela tecla **T** do jogo;
- o LCD mostra a altitude subindo durante o voo;
- fechando a ponte (`Ctrl+C`), o LCD mostra `Ponte: sem sinal` em 1 segundo.

> Para gravar o Mega de novo, **pare a ponte antes**: ela está usando a porta.

## Passo 6: levar para o Pi

1. Ligue o Mega numa USB do Pi.
2. No Pi, pelo SSH:
   ```bash
   cd ~/cockpit && git pull
   source ~/ksp/bin/activate
   python ~/cockpit/bridge/ponte.py 192.168.1.10
   ```
   No Pi, a porta é `/dev/ttyACM0` (Mega original) ou `/dev/ttyUSB0` (clone com CH340), e também é detectada sozinha.

**Pronto quando:** tudo funciona igual ao passo 5, com o Mega no Pi e o Pi pelo Wi-Fi.

## Problemas comuns

| Sintoma | Causa provável | Solução |
|---|---|---|
| Serial Monitor mostra caracteres estranhos | Baud errado | 115200 no Serial Monitor |
| `SAS 1` digitado não faz nada | Final de linha em "Nenhum" | Mudar para "Nova linha" |
| LED não acende nunca | LED invertido | Perna longa (+) do lado do resistor |
| Scanner não acha nada | SDA/SCL trocados ou nos pinos errados | SDA → 20, SCL → 21 |
| LCD com luz, mas sem texto | Contraste | Girar o trimpot atrás do LCD |
| LCD mostra uma fileira de quadrados pretos | O LCD não foi inicializado: endereço errado em `LCD_ENDERECO` | Usar o endereço que o scanner mostrou |
| Falha ao gravar (avrdude: `can't open device`, `Acesso negado` ou timeout) | A ponte ou outro programa está com a porta aberta | Parar a ponte e gravar de novo |
| Ponte: `Acesso negado` ao abrir a porta | Serial Monitor aberto | Fechar o Serial Monitor |
| `module 'serial' has no attribute 'Serial'` | Foi instalado o pacote `serial` em vez de `pyserial` | `pip uninstall serial` e `pip install pyserial` |
| Ponte: "O painel não mandou READY" | Firmware errado gravado, ou baud diferente | Gravar o `painel.ino` |
| No Pi: `Permission denied` em `/dev/ttyACM0` | Usuário fora do grupo `dialout` | `sudo usermod -aG dialout $USER`, sair e entrar de novo no SSH |

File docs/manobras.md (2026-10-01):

# Editor de nós de manobra

**Pronto quando:** dá para planejar uma circularização pelo editor, olhando o nó no mapa do jogo, sem tocar no mouse.

O editor de nós de manobra da [fase 4](../README.md#fase-4--instrumentos-físicos) vai ter no painel um encoder para o Δv, com três korry para escolher o eixo (PRO, NRM e RAD), uma tecla basculante para o tempo, uma chave rotativa para o passo e os botões do nó, sem tela própria ([desenho](../hardware/construcao.md#painel-do-editor-de-manobras)): os números do nó vão para uma página do editor na tela multifunção, que abre sozinha quando o editor é usado. Enquanto o hardware não existe, as teclas e os botões viram botões numa página web, com as tabelas do nó embaixo. A página abre no navegador do PC ou do celular, pelo Wi-Fi.

```
 KSP + kRPC (PC)
      │ chamadas do kRPC (lê e mexe nos nós, na câmera do mapa)
      ▼
 bridge/manobras.py: a ponte do editor. Faz todas as contas.
      │ HTTP: GET /estado (4 vezes por segundo), POST /linha
      ▼
 bridge/celular/manobras.html: botões + tabelas, no navegador
```

A página manda **as mesmas linhas que o painel vai mandar** pela serial (`INC PRO 1`, `BTN NOVO 1`, ver o [protocolo](protocolo.md#editor-de-nós-de-manobra)). Quando as teclas existirem, a ponte lê essas linhas da serial no lugar da página, e as contas continuam as mesmas.

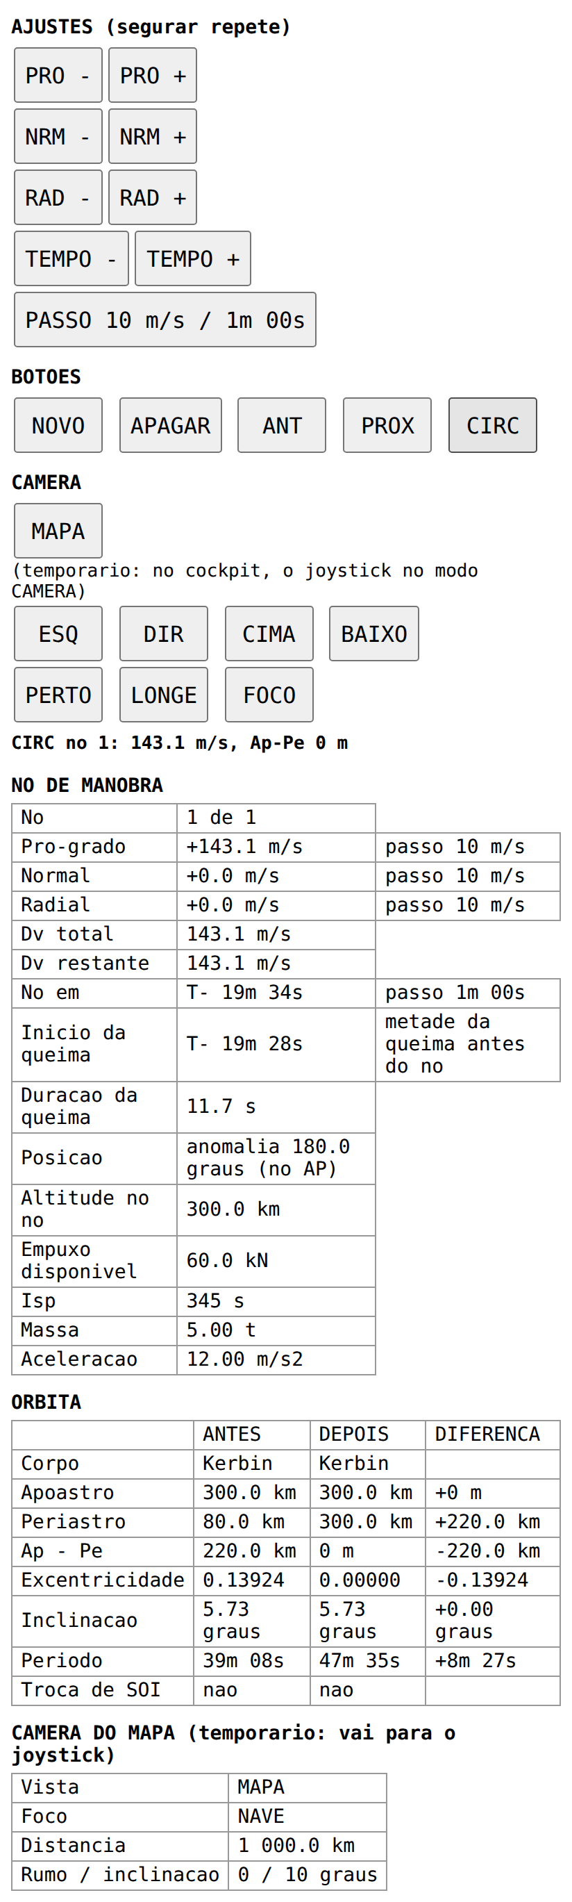
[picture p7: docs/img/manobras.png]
O editor no celular: ajustes, botões, câmera do mapa e as tabelas do nó e da órbita, depois de um CIRC no apoastro


**Onde estamos:** escrito e testado com um kRPC de mentira ([`bridge/tests/test_manobras.py`](../bridge/tests/test_manobras.py)), sem o jogo. Falta testar no KSP (lista no fim).

## Usar

Precisa só do que a ponte já usa (`krpc`, `pyserial`). No PC com o KSP aberto e o servidor do kRPC iniciado:

```
python bridge/manobras.py                  # KSP neste computador
python bridge/manobras.py 192.168.1.10     # KSP em outro computador
python bridge/manobras.py --porta 8001     # porta da página (padrão 8001)
```

Ele mostra o endereço para abrir no navegador. A tela multifunção usa a porta 8000, então as duas rodam juntas.

## Controles

| Botão | O que faz |
|---|---|
| `PRO -` / `PRO +` | Δv pró-grado, um passo por toque. Segurando, repete (10 por segundo), como a tecla com mola do painel |
| `NRM -` / `NRM +` | Δv normal |
| `RAD -` / `RAD +` | Δv radial (para fora do planeta) |
| `TEMPO -` / `TEMPO +` | Move o nó ao longo da órbita. Não deixa o nó a menos de 5 s de agora |
| `PASSO` | Um só para os quatro ajustes: troca o passo de todos juntos. Δv: 0.1 → 1 → 10 → 100 m/s. Tempo: 1 s → 10 s → 1 min → 10 min |
| `NOVO` | Nó novo, com Δv zero, no próximo apoastro **depois do último nó** (sem apoastro: no periastro; sem os dois: daqui a 2 min) |
| `APAGAR` | Apaga o nó escolhido; fica escolhido o seguinte |
| `ANT` / `PROX` | Troca o nó escolhido, quando há mais de um |
| `CIRC` | Acerta o nó escolhido para a órbita ficar circular no ponto onde ele está. Sem nó, cria um no apoastro |
| `MAPA` | Liga e desliga o mapa do jogo, para ver o nó sendo criado. No painel, fica na seção da câmera |
| `ESQ` `DIR` `CIMA` `BAIXO` `PERTO` `LONGE` `FOCO` | Câmera do mapa: **temporário**, ver abaixo |

"A órbita em que o nó está" é a da nave para o primeiro nó, e a que sai do nó anterior para os outros. Assim o `NOVO` depois de um nó põe o novo no apoastro da órbita já mudada pelo primeiro.

Não há botões `AP` e `PE`: o `NOVO` já cria o nó no apoastro, e o `TEMPO` leva o nó a qualquer ponto. A linha "Posição" da tabela avisa quando o nó está no AP ou no PE.

### Circularizar (CIRC)

Um toque deixa a órbita circular no ponto do nó, em qualquer ponto da órbita, não só no apoastro: `NOVO` + `CIRC` (ou só `CIRC`, sem nó) é a circularização de sempre no apoastro; `TEMPO` + `CIRC` circulariza em outra altitude.

1. **Conta fechada.** No ponto do nó, a nave está a uma distância *r* do centro, com velocidade *v* (vis-viva) inclinada *γ* acima do horizonte (ângulo de voo, tan γ = e·sen ν / (1 + e·cos ν)). A órbita circular ali pede velocidade √(μ/r), só na horizontal. A diferença, passada para o quadro do nó (pró-grado inclinado γ), é:
   - pró-grado = √(μ/r)·cos γ − v
   - radial = −√(μ/r)·sen γ
   - normal = 0 (o `CIRC` zera o normal: mudar o plano junto é outra conta).
2. **Conferência.** A ponte lê a órbita que o jogo prevê depois da queima (`node.orbit`), faz a mesma conta nela e soma a correção ao nó, até a correção ficar menor que 1 mm/s (no máximo 5 vezes). Na conta exata, a primeira correção já dá zero; a volta existe para pegar alguma diferença do jogo.
3. A mensagem mostra o Δv e o Ap − Pe que sobrou. Se o ponto estiver dentro da atmosfera ou abaixo do chão, ela avisa.

Se a nave troca de esfera de influência antes do nó, o `CIRC` recusa: a órbita de antes do nó seria outra.

## O que a página mostra

**NÓ DE MANOBRA** (o escolhido)

- Qual nó, de quantos.
- Pró-grado, normal e radial, com o passo.
- Δv total e Δv restante (o que falta, durante a queima).
- T− até o nó, com o passo do `TEMPO`.
- Início da queima: T− até começar, com **metade da queima antes do nó**, como o EXEC da fase 5 vai fazer.
- Duração da queima, pela equação do foguete: empuxo disponível, Isp e massa agora. A nave fica mais leve queimando, por isso a queima longa leva menos que massa × Δv / empuxo.
- Posição: anomalia verdadeira do nó na órbita, e `(no AP)` ou `(no PE)` quando ele está a menos de 1° deles.
- Altitude no nó, empuxo disponível, Isp, massa e aceleração.

**ÓRBITA**: antes, depois e diferença

- Corpo, apoastro, periastro, **Ap − Pe** (0 m é circular), excentricidade, inclinação e período.
- Troca de SOI: para qual corpo, em quanto tempo e o periastro lá (um encontro com a Mun aparece aqui).
- Sem nó, só a órbita de agora.

**AVISOS**: nó que já passou, nave sem motor ativo (a duração fica `--`), periastro abaixo do chão ou dentro da atmosfera.

**CÂMERA DO MAPA**: vista (mapa ou voo), foco, distância, rumo e inclinação.

A última mensagem (resultado de um botão, erro do jogo) fica 6 s acima das tabelas. Os textos são ASCII, sem acentos, como na tela multifunção.

## Câmera do mapa: temporário

**Tem que mudar:** no cockpit, a câmera do mapa vai ser mexida pelo **joystick, no modo CÂMERA** (o modo é trocado pelo botão do manche do sidestick, em [hardware/construcao.md](../hardware/construcao.md#joystick-logitech-extreme-3d-pro)). Os botões `ESQ`, `DIR`, `CIMA`, `BAIXO`, `PERTO`, `LONGE` e `FOCO` só existem porque o joystick não está aqui agora. Quando ele estiver, saem da página, das linhas `BTN CAM_*` e de `Editor._camera` em `bridge/manobras.py`. O botão `MAPA` fica, na seção da câmera do painel.

- `ESQ` / `DIR`: gira 15° em volta do foco. `CIMA` / `BAIXO`: 10° na inclinação.
- `PERTO` / `LONGE`: distância ÷ ou × 1,5, dentro dos limites do jogo.
- `FOCO`: nave → nó escolhido → planeta → nave. Com o foco no nó, dá para ver a órbita nova de perto enquanto mexe nos ajustes.
- Só funcionam com o mapa ligado.

## Decisões

- **A página não faz conta.** Recebe as tabelas prontas, em texto. O que a página do editor na tela multifunção vai mostrar sai da mesma função (`Editor.estado`).
- **Página que pergunta, e não fluxo de eventos** como a tela multifunção: o editor atualiza 4 vezes por segundo, e um `GET /estado` por vez é mais simples. Os toques vão numa fila, e só a volta principal usa o kRPC.
- **O nó escolhido é guardado pelo objeto do nó, não pela posição na lista.** Mover um nó com o `TEMPO` para depois de outro muda a ordem, e os ajustes continuam no mesmo nó.
- **`NOVO` no apoastro,** porque é onde quase todo nó começa; o `TEMPO` leva para outro lugar.
- **Um `PASSO` só**, em vez de um por ajuste: menos botões no painel. O mesmo índice vale para o Δv e para o tempo (1 m/s anda junto com 10 s).
- **Sem `AP` e `PE`:** o `TEMPO` já faz isso, e são dois botões a menos.
- **Tempo até um ponto pela equação de Kepler** (anomalia média), feita aqui e não pelo kRPC, porque o `time_to_apoapsis` do kRPC conta a partir de agora, e o segundo nó está numa órbita que só começa no primeiro. Funciona em elipse e hipérbole.
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

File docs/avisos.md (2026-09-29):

# Avisos de voo por voz (GPWS)

**Pronto quando:** voando baixo no jogo, a caixa de som ligada no Pi fala `SINK RATE`, `TERRAIN`, `PULL UP` e os outros avisos na hora certa, a luz GPWS do painel acende junto e o pouso normal só tem as chamadas de altura.

Como o GPWS dos aviões de linha (o "Ground Proximity Warning System"), a ponte da tela ([`bridge/avisos.py`](../bridge/avisos.py), chamado pelo `mfd.py`) olha a altura acima do chão, a velocidade vertical, o trem de pouso, a inclinação e a pressão dinâmica, e fala o aviso em inglês. Vale em **qualquer nave voando na atmosfera**, com ou sem o [fly by wire](fbw.md), porque quem lê o jogo é a ponte.
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

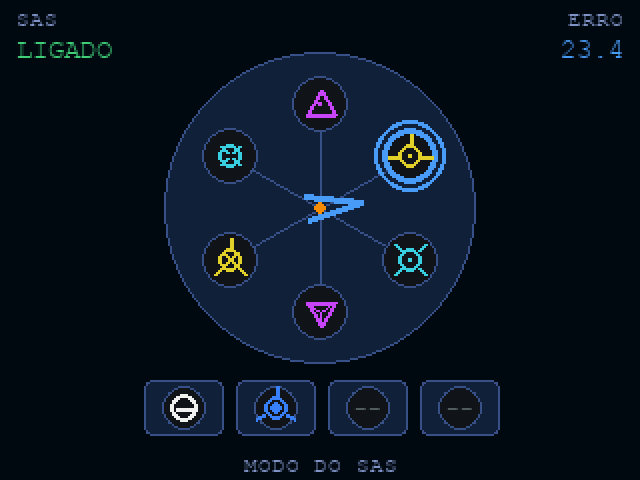
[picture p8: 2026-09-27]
docs/img/mfd_sas.png

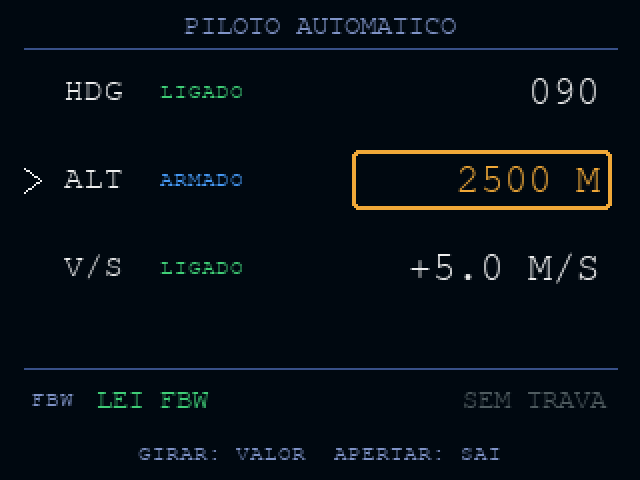
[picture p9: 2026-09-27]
docs/img/mfd_ap.png

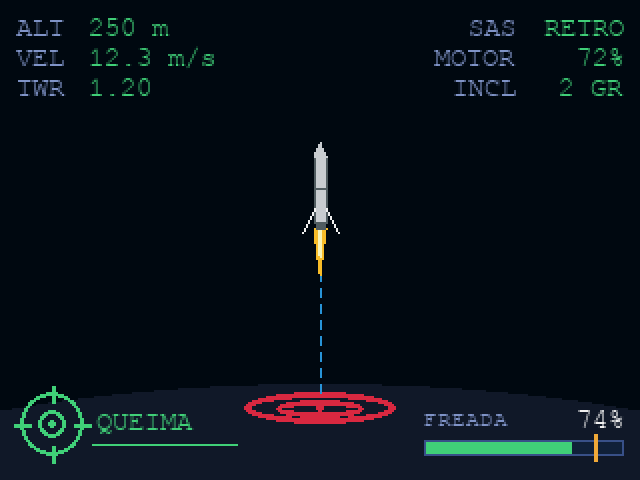
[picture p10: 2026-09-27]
docs/img/mfd_pouso.png

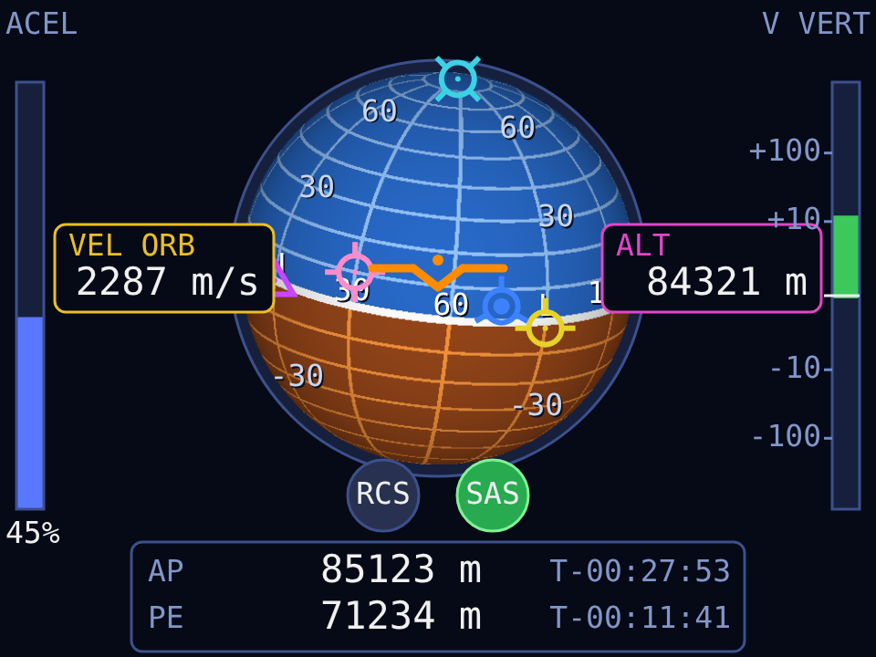
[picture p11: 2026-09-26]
docs/img/mfd_celular.png

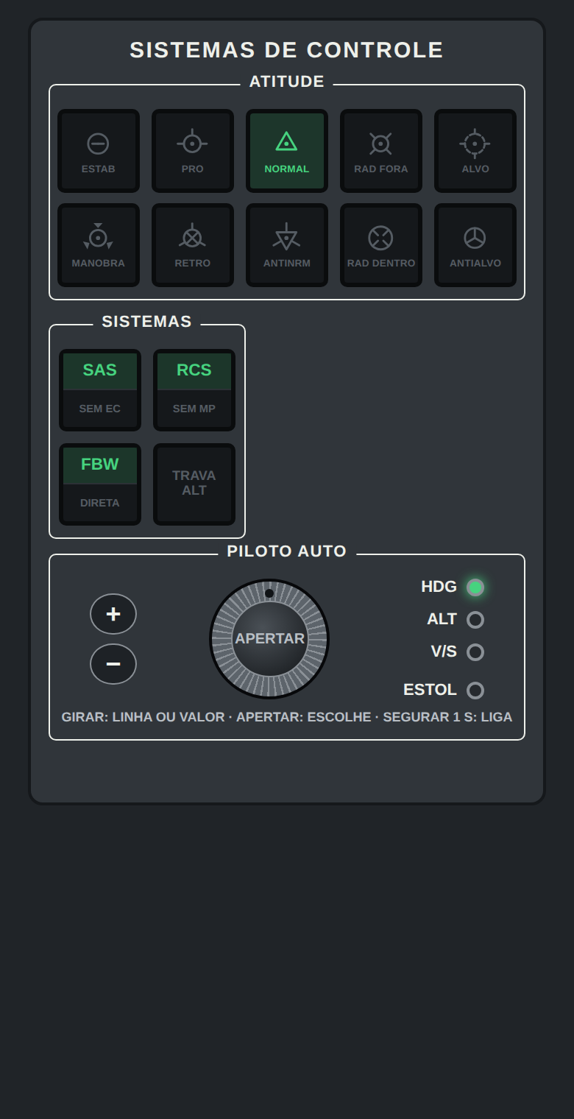
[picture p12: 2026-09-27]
docs/img/painel_sistemas.png

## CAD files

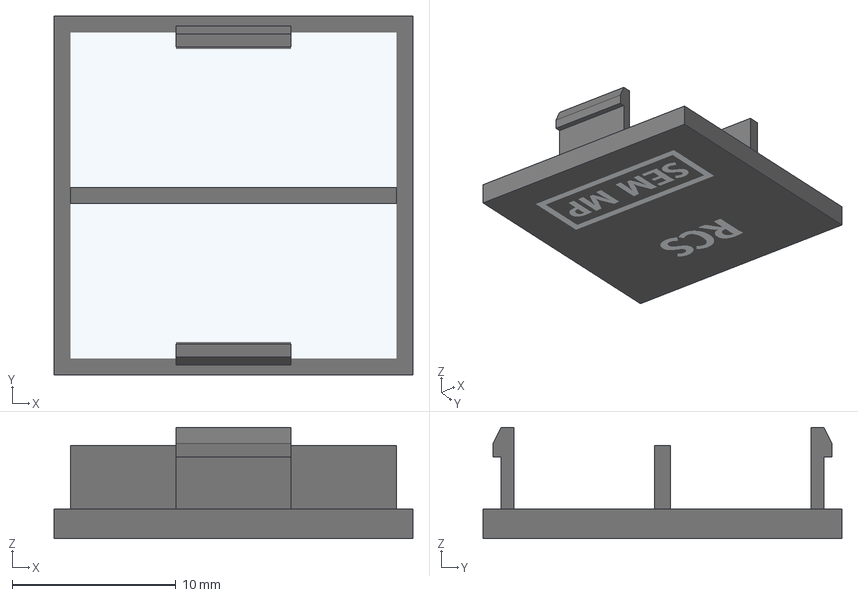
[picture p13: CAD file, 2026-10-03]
hardware/korry/3mf/legenda_rcs.3mf
21.9 x 21.9 x 6.80 mm

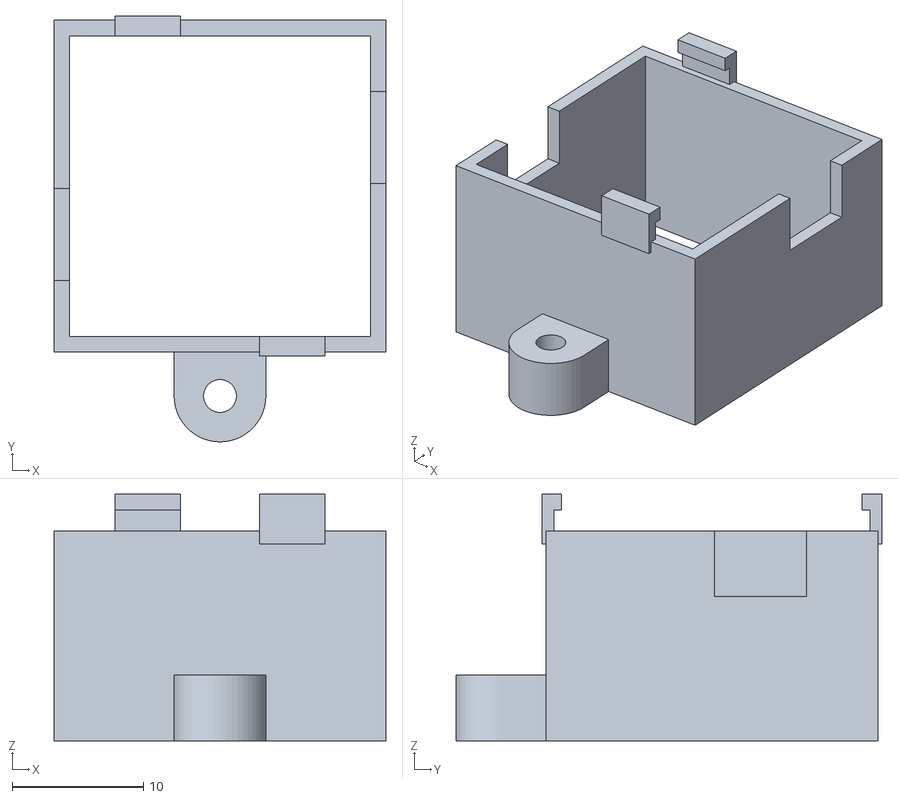
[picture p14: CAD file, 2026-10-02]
hardware/korry/stl/grades/grade_fisico.stl
25.3 x 32.4 x 18.8

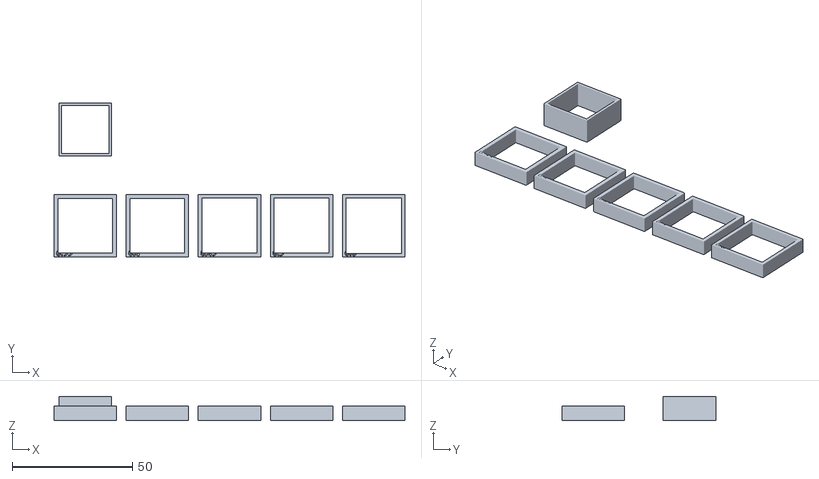
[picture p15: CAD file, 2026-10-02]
hardware/korry/stl/korry_teste.stl
146.0 x 64.0 x 10.0

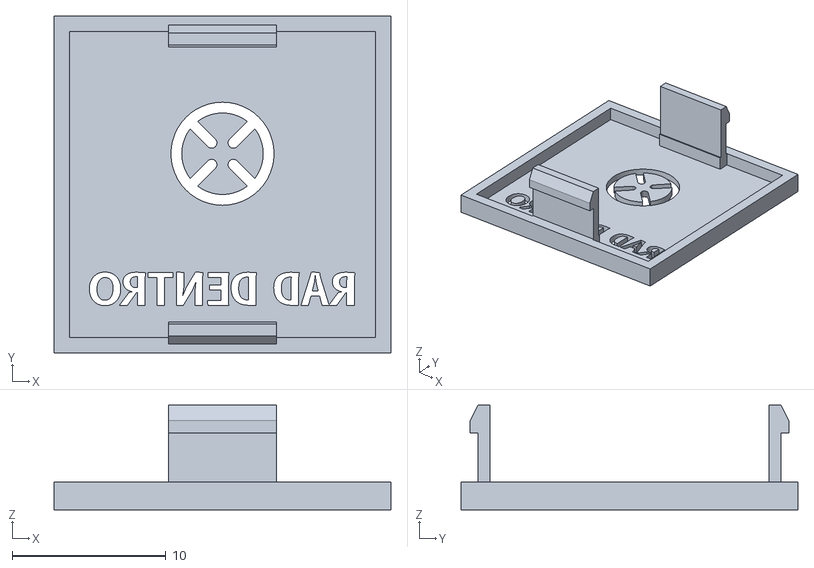
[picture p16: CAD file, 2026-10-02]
hardware/korry/stl/legendas/sas_rad_dentro_preto.stl
21.9 x 21.9 x 6.80

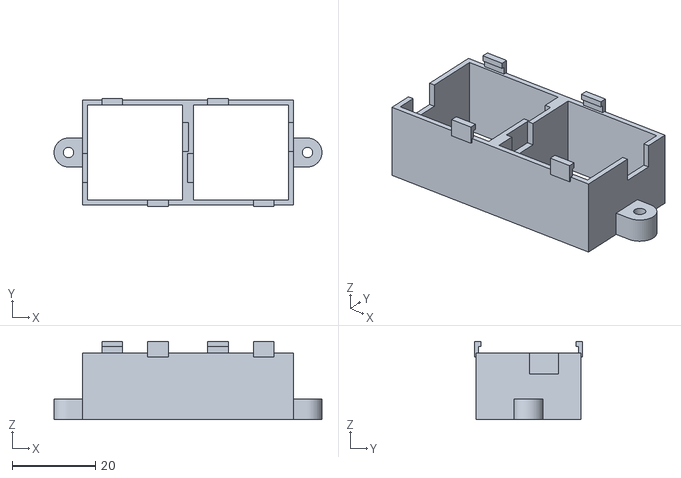
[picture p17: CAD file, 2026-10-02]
hardware/korry/stl/grades/grade_eva.stl
64.5 x 25.9 x 18.8

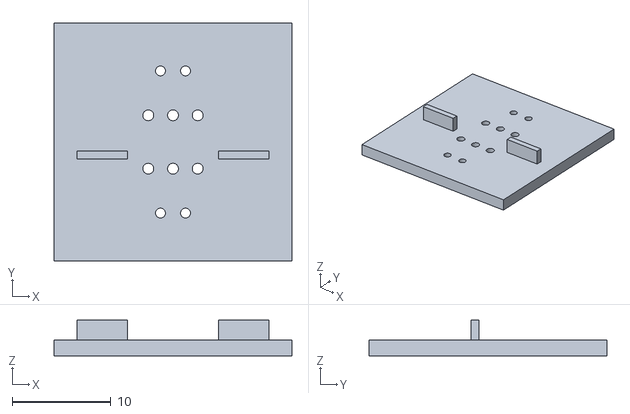
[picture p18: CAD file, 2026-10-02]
hardware/korry/stl/korry_suporte.stl
24.1 x 24.1 x 3.60

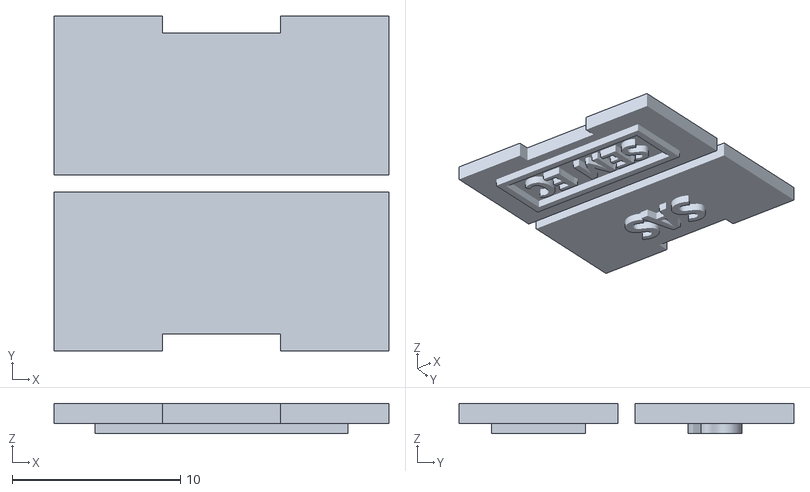
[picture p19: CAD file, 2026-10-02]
hardware/korry/stl/legendas/sas_transparente.stl
19.9 x 19.9 x 1.80

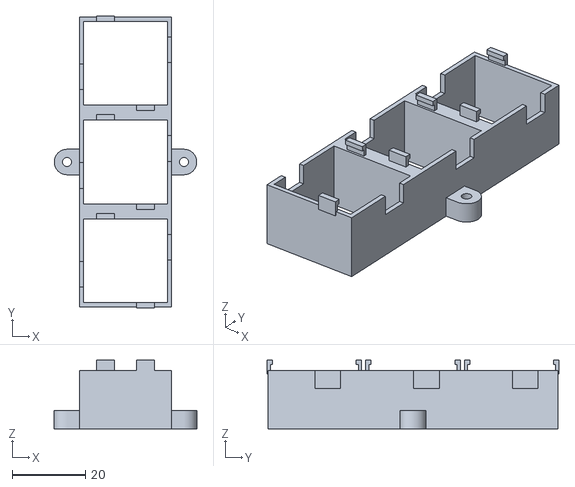
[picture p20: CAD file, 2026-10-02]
hardware/korry/stl/grades/grade_rodas.stl
39.0 x 79.9 x 18.8

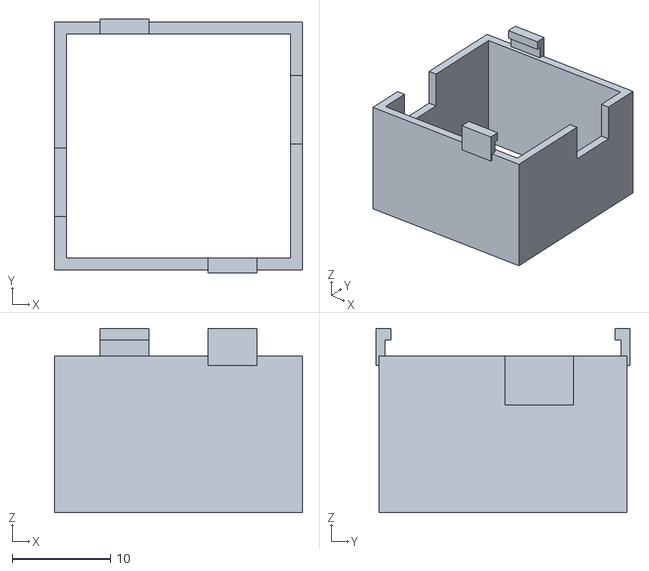
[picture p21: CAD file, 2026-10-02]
hardware/korry/stl/korry_base.stl
25.3 x 25.9 x 18.8

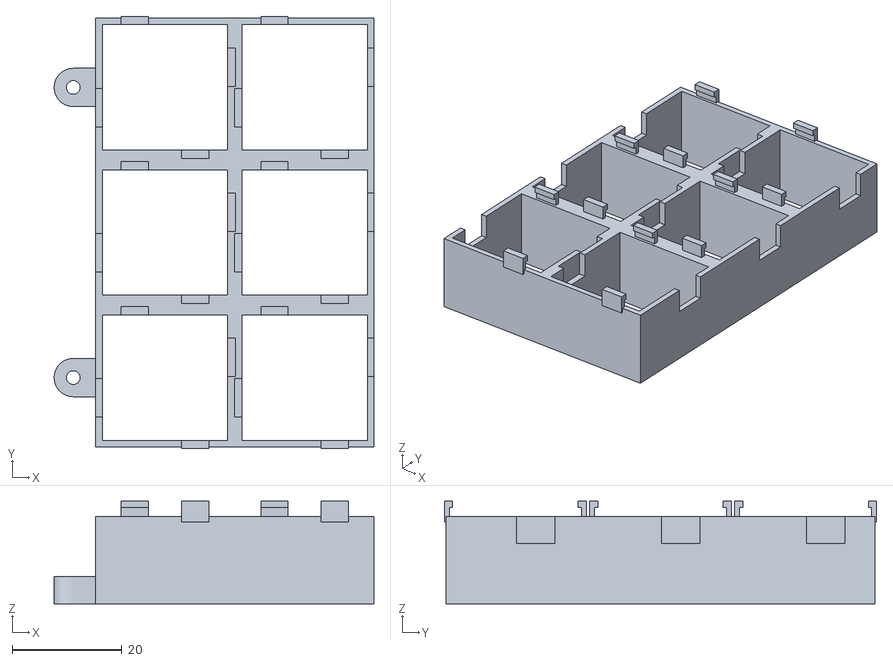
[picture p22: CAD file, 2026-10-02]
hardware/korry/stl/grades/grade_scripts.stl
58.4 x 78.9 x 18.8

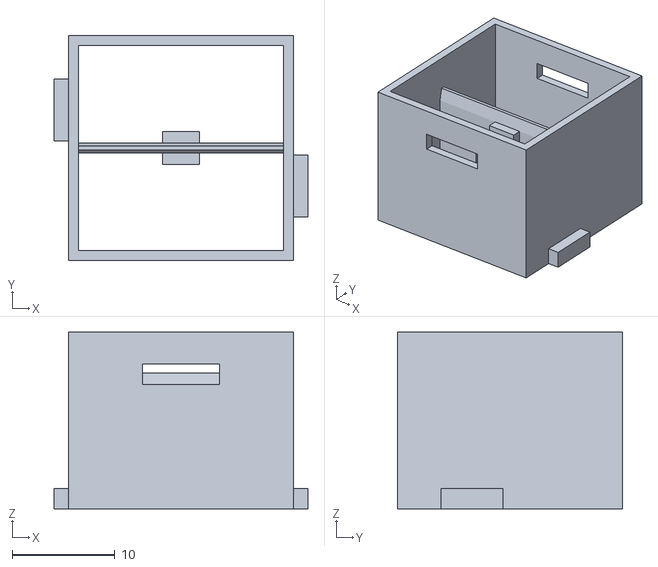
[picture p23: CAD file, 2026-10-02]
hardware/korry/stl/korry_corpo.stl
24.7 x 21.9 x 17.2

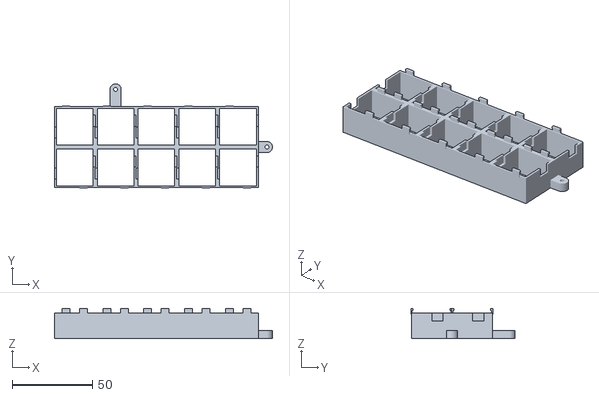
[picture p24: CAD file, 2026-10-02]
hardware/korry/stl/grades/grade_voo_sas.stl
136.2 x 65.2 x 18.8

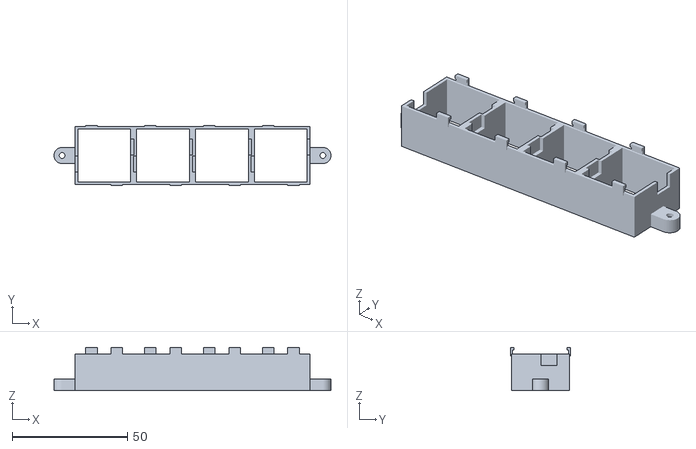
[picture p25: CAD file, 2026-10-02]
hardware/korry/stl/grades/grade_pecas.stl
120.0 x 25.9 x 18.8

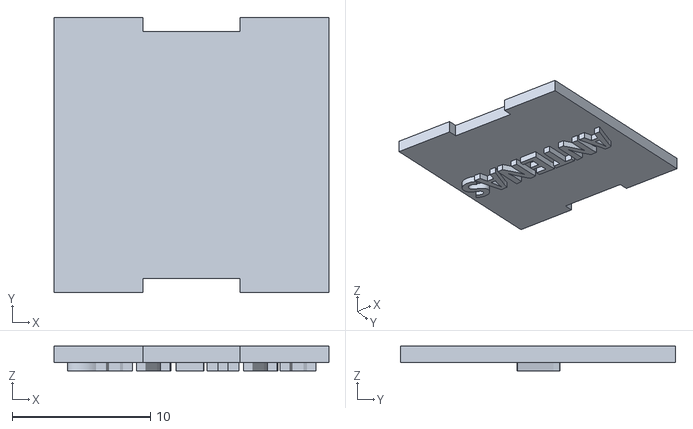
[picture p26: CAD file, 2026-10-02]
hardware/korry/stl/legendas/antenas_transparente.stl
19.9 x 19.9 x 1.80

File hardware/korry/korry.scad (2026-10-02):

peca = "montagem";
texto_cima = "SAS";
texto_baixo = "SEM EC";
modo_sas = "";
celulas = [[0, 0]];
furos = [];
fonte = "B612:style=Bold";
folga = 0.5;

painel = 3;
tubo_interno = 22.9;
frente = tubo_interno - 2 * folga;
parede = 1.0;
saliencia = 3;
tampa = 1.8;
mascara = 0.6;
comprimento = 16;
recuo = 4;
divisoria_y = 0;
divisoria_e = 1.0;
ressalto_l = 1.4;
ressalto_c = 2;
ressalto_largura = 6;
ressalto_y = 0.7;
letra_cima = 3;
letra_baixo = 2.4;
caixa_l = 15;
caixa_a = 5.6;
caixa_traco = 0.6;
traco_icone = 0.7;
orelha_l = 7;
orelha_esp = 5;
furo_m3 = 2.5;
passo_min = 25.5;

chave = 8.5;
chave_h = 8;
haste_h = 5.5;
haste_x = 2;
haste_y = 3;
pino_c = 4;
pino_passo = 2.5;
pino_fileiras = 5.4;
curso = 2.5;
pre_carga = 0.3;
margem = 0.5;

tubo_parede = 1.2;
tubo_comprimento = 16;
suporte_esp = 1.6;
suporte_folga = 1.2;
furo_pino = 1.1;
furo_led = 1.0;
led_y = 7.2;
led_pernas = 2.54;

aba_l = 7;
aba_e = 0.8;
aba_c = 5;
dente = 0.5;

$fn = 48;

sas_nomes = [["ESTAB", "ESTAB"], ["MAN", "MANOBRA"], ["PRO", "PRO"], ["RETRO", "RETRO"], ["NRM", "NORMAL"],
             ["ANRM", "ANTINRM"], ["RFORA", "RAD FORA"], ["RDENTRO", "RAD DENTRO"], ["ALVO", "ALVO"], ["AALVO", "ANTIALVO"]];

lado = frente - 2 * parede;
largura_util = lado - 2.5;
palavras_sas = [for (p = sas_nomes) if (p[0] == modo_sas) p[1]];
palavra_sas = len(palavras_sas) > 0 ? palavras_sas[0] : "";
em_branco = texto_cima == "" && texto_baixo == "" && modo_sas == "";
duas_metades = texto_baixo != "" && modo_sas == "";
caixa_larg = min(caixa_l, max(len(texto_baixo), 3) * 0.85 * tamanho(texto_baixo, letra_baixo) + 4);
centro_cima = duas_metades ? (lado / 2 + divisoria_y + divisoria_e / 2) / 2 : 0;
centro_baixo = (-lado / 2 + divisoria_y - divisoria_e / 2) / 2;

tubo_externo = tubo_interno + 2 * tubo_parede;
suporte_lado = tubo_interno + suporte_folga;
trilho_l = frente / 2 + ressalto_l + folga - tubo_interno / 2;
trilho_largura = ressalto_largura + 2 * folga;
batente = comprimento - ressalto_c - painel;
costas = tampa - saliencia;

suporte_z = painel + tubo_comprimento;
chave_z = suporte_z - chave_h;
haste_z = chave_z - haste_h;
apoio_z = haste_z + pre_carga;
fundo_corpo = suporte_z - curso - margem;
degrau_z = chave_z - curso - margem;

dente_z = costas + 3.2;
dente_topo = costas + 4.0;
aba_topo = costas + aba_c;

assert(len(celulas) > 0, "sem celulas");
assert(passo_ok(celulas), "korry mais perto que passo_min");
assert(modo_sas == "" || len(palavras_sas) > 0, "modo_sas desconhecido");
assert(abs(fundo_corpo - comprimento) < 0.001, "fundo do corpo diferente do comprimento");
assert(led_y - 1.9 > chave / 2, "LED encosta na chave");
assert(led_y + 1.9 < lado / 2, "LED encosta na parede");

vidro = [0.85, 0.92, 1];
escuro = 0.62;
cortar = peca == "corte";

module pinta(c) {
    if (cortar) {
        color([c[0] * escuro, c[1] * escuro, c[2] * escuro, len(c) == 4 ? c[3] : 1]) render() difference() { children(); translate([-0.1, -50, -50]) cube([100, 100, 100]); }
        color(c) render() intersection() { children(); translate([-0.1, -50, -50]) cube([0.1, 100, 100]); }
    } else color(c) children();
}

module bloco(x0, x1, y0, y1, z0, z1) {
    translate([x0, y0, z0]) cube([x1 - x0, y1 - y0, z1 - z0]);
}

function tamanho(texto, maximo) = min(maximo, largura_util / (max(len(texto), 3) * 0.85));

module anel(r) {
    difference() { circle(r + traco_icone / 2, $fn = 48); circle(r - traco_icone / 2, $fn = 48); }
}

module raio(graus, r0, r1) {
    hull() for (r = [r0, r1]) translate([r * cos(-graus), r * sin(-graus)]) circle(d = traco_icone, $fn = 16);
}

module ponto() {
    circle(r = 0.55, $fn = 16);
}

module triangulo_icone(baixo, r) {
    pts = [for (i = [0 : 2]) let(a = -((baixo ? 90 : -90) + i * 120)) [r * cos(a), r * sin(a)]];
    difference() {
        offset(r = traco_icone / 2, $fn = 16) polygon(pts);
        offset(delta = -traco_icone / 2) polygon(pts);
    }
}

module seta_man(graus) {
    a = -graus;
    d = [cos(a), sin(a)];
    n = [-sin(a), cos(a)];
    polygon([2.6 * d, 3.9 * d + 1.2 * n, 3.9 * d - 1.2 * n]);
}

module anel_tracejado(r) {
    intersection() {
        anel(r);
        for (i = [0 : 8]) {
            a0 = -i * 40 - 1.1 / r * 180 / PI;
            a1 = -i * 40;
            polygon([[0, 0], 6 * [cos(a0), sin(a0)], 6 * [cos(a1), sin(a1)]]);
        }
    }
}

module icone_sas(modo) {
    if (modo == "ESTAB") { anel(2.6); raio(180, 0, 1.5); raio(0, 0, 1.5); }
    if (modo == "MAN") { anel(2.1); ponto(); for (g = [-90, 30, 150]) seta_man(g); }
    if (modo == "PRO") { anel(2.2); ponto(); for (g = [-90, 180, 0]) raio(g, 2.2, 3.8); }
    if (modo == "RETRO") {
        anel(2.2);
        for (g = [45, 135]) raio(g, -2.2, 2.2);
        for (g = [-90, 150, 30]) raio(g, 2.2, 3.8);
    }
    if (modo == "NRM") { triangulo_icone(false, 3); ponto(); }
    if (modo == "ANRM") { triangulo_icone(true, 3); ponto(); for (g = [-90, 30, 150]) raio(g, 1.5, 3.9); }
    if (modo == "RFORA") { anel(2); ponto(); for (g = [45, 135, 225, 315]) raio(g, 2, 3.7); }
    if (modo == "RDENTRO") { anel(3); for (g = [45, 135, 225, 315]) raio(g, 1, 3); }
    if (modo == "ALVO") { anel_tracejado(2.6); ponto(); for (g = [0, 90, 180, 270]) raio(g, 2.6, 3.8); }
    if (modo == "AALVO") { anel(2.6); for (g = [-90, 30, 150]) raio(g, 0, 2.6); }
}

module legenda() {
    mirror([1, 0]) {
        if (modo_sas != "") {
            translate([0, 2.0]) icone_sas(modo_sas);
            translate([0, -6.8]) text(palavra_sas, size = tamanho(palavra_sas, 2.4), font = fonte, halign = "center", valign = "center");
        } else {
            if (texto_cima != "")
                translate([0, centro_cima]) text(texto_cima, size = tamanho(texto_cima, letra_cima), font = fonte, halign = "center", valign = "center");
            if (duas_metades) translate([0, centro_baixo]) {
                text(texto_baixo, size = tamanho(texto_baixo, letra_baixo), font = fonte, halign = "center", valign = "center");
                difference() {
                    square([caixa_larg, caixa_a], center = true);
                    square([caixa_larg - 2 * caixa_traco, caixa_a - 2 * caixa_traco], center = true);
                }
            }
        }
    }
}

module letras(z0, h) {
    if (!em_branco)
        translate([0, 0, z0]) linear_extrude(h) intersection() { legenda(); square(lado, center = true); }
}

module divisoria_legenda() {
    if (duas_metades)
        bloco(-lado / 2, lado / 2, divisoria_y - divisoria_e / 2, divisoria_y + divisoria_e / 2, -saliencia + mascara, costas + recuo - 0.1);
}

module blocos_abas() {
    for (m = [0, 1]) mirror([0, m, 0]) bloco(-aba_l / 2, aba_l / 2, lado / 2 - 1, lado / 2, -saliencia + mascara, costas);
}

module aba() {
    y0 = lado / 2 - 0.1;
    bloco(-aba_l / 2, aba_l / 2, y0 - aba_e, y0, costas, aba_topo);
    rotate([90, 0, 90]) linear_extrude(aba_l, center = true)
        polygon([[y0 - 0.1, dente_z], [y0 + dente, dente_z], [y0 + dente, dente_topo], [y0, aba_topo], [y0 - 0.1, aba_topo]]);
}

module legenda_preto() {
    difference() {
        bloco(-frente / 2, frente / 2, -frente / 2, frente / 2, -saliencia, costas);
        bloco(-lado / 2, lado / 2, -lado / 2, lado / 2, -saliencia - 1, costas + 1);
    }
    difference() {
        bloco(-lado / 2, lado / 2, -lado / 2, lado / 2, -saliencia, -saliencia + mascara);
        letras(-saliencia - 1, mascara + 1);
    }
    divisoria_legenda();
    blocos_abas();
    for (m = [0, 1]) mirror([0, m, 0]) aba();
}

module legenda_transparente() {
    letras(-saliencia, mascara);
    difference() {
        bloco(-lado / 2, lado / 2, -lado / 2, lado / 2, -saliencia + mascara, costas);
        divisoria_legenda();
        blocos_abas();
    }
}

module janelas() {
    for (m = [0, 1]) mirror([0, m, 0])
        bloco(-aba_l / 2 - 0.25, aba_l / 2 + 0.25, lado / 2 - 0.1, frente / 2 + 1, dente_z - 0.1, aba_topo + 0.1);
}

module ressaltos() {
    for (m = [0, 1]) rotate([0, 0, 180 * m])
        bloco(frente / 2 - 0.1, frente / 2 + ressalto_l, ressalto_y, ressalto_y + ressalto_largura, comprimento - ressalto_c, comprimento);
}

module perfil_divisoria() {
    e = divisoria_e / 2;
    rotate([90, 0, 90]) linear_extrude(lado + 0.2, center = true)
        polygon([[divisoria_y - 0.2, costas + recuo], [divisoria_y + 0.2, costas + recuo], [divisoria_y + e, costas + recuo + 1.5],
                 [divisoria_y + e, comprimento], [divisoria_y - e, comprimento], [divisoria_y - e, costas + recuo + 1.5]]);
}

module degraus_divisoria() {
    w = lado / 2 + 0.1;
    rotate([90, 0, 0]) linear_extrude(6, center = true)
        polygon([[-w, 0], [-w, comprimento], [-4.6, comprimento], [-4.6, degrau_z], [-2.3, degrau_z], [-2.3, apoio_z],
                 [2.3, apoio_z], [2.3, degrau_z], [4.6, degrau_z], [4.6, comprimento], [w, comprimento], [w, 0]]);
}

module divisoria_corpo() {
    intersection() { perfil_divisoria(); degraus_divisoria(); }
    bloco(-1.8, 1.8, divisoria_y - 1.6, divisoria_y + 1.6, apoio_z - 1.5, apoio_z);
}
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

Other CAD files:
hardware/korry/stl/legendas/fisico_preto.stl
hardware/korry/stl/legendas/antenas_preto.stl
hardware/korry/stl/legendas/sas_antialvo_preto.stl
hardware/korry/stl/grades/grade_vista.stl
hardware/korry/stl/grades/grade_deltav.stl
hardware/korry/stl/grades/grade_voo_sistemas.stl
hardware/korry/stl/legendas/branco_preto.stl
hardware/korry/stl/legendas/branco_transparente.stl
hardware/korry/stl/legendas/carga_preto.stl
hardware/korry/stl/legendas/carga_transparente.stl
hardware/korry/stl/legendas/fbw_preto.stl
hardware/korry/stl/legendas/fbw_transparente.stl
hardware/korry/stl/legendas/fisico_transparente.stl
hardware/korry/stl/legendas/freios_preto.stl
hardware/korry/stl/legendas/freios_transparente.stl
hardware/korry/stl/legendas/iva_preto.stl
hardware/korry/stl/legendas/iva_transparente.stl
hardware/korry/stl/legendas/jato_preto.stl
hardware/korry/stl/legendas/jato_transparente.stl
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

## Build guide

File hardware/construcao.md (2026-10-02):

# Construção física: carcaça, aparência, korry switches e joystick

Este documento trata da parte física do cockpit: o formato da caixa, a aparência, como fabricar as peças, os korry switches e onde entra o joystick. A eletrônica dos módulos está no [README do hardware](README.md); a arquitetura e o roteiro, no [README principal](../README.md).

**Status: ideias, nada construído.** A caixa definitiva é da [fase 7](../README.md#fase-7--hardware-definitivo), mas protótipos (um korry, um painel de seção) podem ser feitos antes, junto com os módulos da fase 2.

## Ferramentas disponíveis

| Ferramenta | Onde | Serve para |
|---|---|---|
| **Impressora 3D** | em casa | Peças pequenas e com forma complicada: korry switches, a alavanca do acelerador, suportes de placa, moldura da tela, passa-cabos. |
| **Corte a laser** | no colégio | Peças planas e grandes: as paredes da caixa e os painéis frontais, com furos e legendas gravadas. |
| **Logitech Extreme 3D Pro** | em casa | Joystick de 3 eixos com acelerador, para desenvolver no PC. No cockpit, o sidestick é o [JH-D400X-R4](#sidestick). |

A impressora é uma **FlashForge Inventor**, com dois bicos: imprime duas cores na mesma peça, como o [korry](korry/README.md#como-imprimir), e tem mesa de 230 × 150 mm.

**Anotar aqui quando souber:**
- o tamanho da mesa da laser do colégio e quais materiais ela aceita;
- a potência da laser (diz se corta MDF de 6 mm ou só de 3 mm).

## Aparência

A referência são os painéis de avião, como o overhead do A320 e o MCP do Boeing: sóbrios, cinza escuro, legendas brancas e botões iluminados. O KSP entra nos detalhes.

Cores, letras, medidas do painel, grupos, peças e as regras para organizar um painel estão na [identidade visual](identidade_visual.md). Vale para todo painel novo.

- **Zona de perigo:** o ABORT fica numa área com faixa zebrada amarela e preta, com capa de proteção. O STAGE, o IVA, o CARREGAR e o REVERTER também ficam debaixo de capas.
- **Iluminação das legendas (ideia):** gravadas num acrílico pintado, as legendas deixam passar a luz de LEDs brancos por trás e acendem no escuro. Um knob de brilho no painel (um potenciômetro, ou PWM do Mega) regula todas juntas.

## Cockpit, versão B

O cockpit escolhido: **766 × 391 mm, em U**, com um bloco no meio e duas asas que descem dos lados, como num avião. A mão esquerda fica no acelerador e a direita no sidestick, e entre as asas sobra um vão de 484 mm para o piloto. Os painéis têm 125 × 125 mm, ou 250 × 125 os que precisam de mais espaço.

Cockpit da versão B: action groups, recursos e EVA e acelerador na asa esquerda; navegação, tela, ação executiva e voo no meio; editor, tempo, câmera e sidestick à direita

| | Asa esquerda | Meio | Lado direito |
|---|---|---|---|
| Em cima | Action groups | Navegação · **Tela multifunção** | Editor de manobras |
| No meio | Recursos e EVA | **Ação executiva · Voo** | Tempo · Câmera |
| Embaixo | **Acelerador** | (vão de 484 mm) | **Sidestick** |

O porquê de cada lugar está nas regras de [como organizar o cockpit](identidade_visual.md#como-organizar-o-cockpit). O desenho é gerado por [`desenho/paineis/cockpit.js`](desenho/paineis/cockpit.js). As propostas anteriores, com painéis de 150 mm, estão em [`img/antigos/`](img/antigos/).

### Formato da caixa

- **Inclinação:** uns 15° na fileira de baixo e mais em pé na fileira da tela, de 45° a 60°. Testar no protótipo de papelão antes de cortar.
- **Profundidade:** uns 70 mm por dentro, embaixo dos painéis. O mais fundo atrás do painel é o joystick (uns 40 mm, a medir), depois a chave rotativa (~30 mm) e o korry com o cabo (~30 mm), e o módulo vai atrás de cada painel.
- **Tela:** a de 7" tem os conectores de HDMI e USB na lateral; deixar uns 15 mm livres do lado dela.
- **Sem joystick solto:** o sidestick é um painel do cockpit, na ponta da asa direita.

### Componentes

Todos existem e são vendidos em lojas de eletrônica e no AliExpress. As medidas são de catálogo: conferir no paquímetro quando chegarem ([medir antes de cortar](#medir-antes-de-cortar)).

| Peça | Qtd | Onde | Medida |
|---|---|---|---|
| [Korry impresso](korry/README.md) | 35 | Voo, ação executiva, editor, peças, rodas e luzes, EVA, câmera, tempo | 21,9 × 21,9 mm, furo de 23 × 23 mm |
| Chave PSW 8,5 × 8,5 sem trava | 35 | Dentro de cada korry | |
| LED de 3 mm difuso | ~40 | Korry de uma cor | |
| LED de 3 mm azul e verde, catodo comum | 10 | Modos do SAS | 3 pernas |
| Encoder EC11 com botão + knob de alumínio de 30 mm | 3 | Piloto automático, alvo, Δv | Eixo de 6 mm, 20 cliques por volta, furo de 7 mm |
| Chave rotativa 1P12T com batente + knob de ponteiro | 2 | PASSO, REFERENCIA | Furo de 10 mm, corpo Ø ~26 mm |
| Tecla KCD1 (ON)-OFF-(ON) | 2 | WARP, TEMPO do editor | 21 × 15 mm, furo de 19 × 13 mm |
| Botão de 16 mm sem trava (R16-503 ou R13-507) | 34 | Action groups, páginas, navegação, editor, tempo, câmera, EVA | Anel Ø 20 mm, cabeça Ø 13 mm, rosca M16 × 1, 24,8 mm de altura. Furo em D: Ø 16 mm com um lado reto a 15 mm |
| Botão de metal de 22 mm com anel de LED | 2 | ABORT (vermelho), STAGE (branco) | Cabeça Ø ~25 mm. LED de 5 V ou de 3 V |
| Capa transparente para botão de 22 mm | 2 | ABORT, STAGE | 39 × 34 × 17 mm, colada |
| Capa impressa para botão de 16 mm | 2 | CARREGAR, REVERTER | 24 × 40 mm, a desenhar |
| Capa impressa para korry | 1 | IVA | A desenhar |
| Potenciômetro deslizante Bourns PTA6043, 10 kΩ linear | 1 | Acelerador | 75 × 9 × 6,5 mm, curso de 60 mm |
| Joystick JH-D400X-R4, 10 kΩ, com botão | 1 | Sidestick | X e Y ±25 a 30°, torção ±45°. Corpo de ~50 mm; furo a medir |
| Tela Waveshare 7" HDMI LCD (C), toque capacitivo | 1 | Tela multifunção | 164,9 × 107 × 8 mm, imagem de 154,2 × 85,9 mm, 1024 × 600 |
| Barra de 10 LEDs verde (Kingbright DC-10GWA) | 5 | Recursos e EVA | 25,4 × 10,16 mm |
| MAX7219 | 1 | Acende as 5 barras (50 LEDs) | Ligado direto no Mega, fora do backplane |
| LED de 5 mm difuso, no suporte de plástico com porca | 7 | HDG, ALT, V/S, ESTOL, modos do sidestick | Anel Ø 9 mm, furo de 6,5 mm (conferir no suporte); 12 mm entre centros |
| Alto-falante USB | 1 | Avisos de voz, atrás da grade da tela | |

## Construção

### Um painel por seção

Cada seção do painel é **um painel frontal removível, com o seu módulo parafusado atrás**. Para tirar uma seção basta soltar os parafusos e o cabo flat. É a mesma ideia dos módulos do backplane, agora na caixa.

- **Painel frontal:** MDF ou acrílico de 3 mm, cortado e gravado a laser. Furos, legendas e linhas das seções saem no mesmo corte.
- **Módulo:** preso atrás do painel com espaçadores M3.
- **Fixação na caixa:** parafusos M3 em insertos roscados, colocados a quente em peças impressas, ou em porcas cativas. Parafuso direto no MDF espana depois de algumas desmontagens.
- **Tamanho padrão: 125 × 125 mm** ([identidade visual](identidade_visual.md#painel)). Todo painel de seção tem a mesma frente, então qualquer um troca de lugar com outro, e seções novas cabem sem refazer a caixa. Uma seção que precise de mais espaço ocupa dois quadrados (250 × 125 mm). Parafusos M3 nos cantos, a 6 mm das bordas.

### Estrutura

- **Paredes em MDF de 3 mm cortado a laser**, com encaixe dentado (*finger joint*), colado com cola branca. Geradores prontos: [boxes.py](https://boxes.hqs.de/) e [MakerCase](https://en.makercase.com/).
- Peças maiores que a mesa da laser são divididas e unidas por dentro com uma tala.
- **Traseira**, com os recortes:
  - entrada da fonte de 5 V (P4 ou borne) e uma chave liga/desliga;
  - passagem do cabo de rede do Pi (ou só um furo com passa-cabo);
  - extensão USB de painel para o joystick, que liga no Pi dentro da caixa;
  - ventilação para o Pi: grade de furos e uma ventoinha de 5 V e 40 mm.
- **Fundo removível**, para chegar no backplane sem desmontar o painel.
- **Pés de borracha** embaixo: a caixa não pode andar na mesa quando o ABORT é apertado com força.

### Acabamento

- **Protótipos:** MDF cru, sem pintura.
- **MDF definitivo:** lixar, passar primer e tinta spray fosca. A gravação a laser sobre a tinta deixa a legenda na cor do MDF, marrom, e não branca.
- **Legendas brancas:** acrílico preto gravado. A gravação fica branca fosca.
- **Legendas iluminadas:** acrílico branco leitoso pintado de preto por cima. A laser tira a tinta só nas letras, e a luz de trás passa por elas.
- **Segurança na laser:** MDF e acrílico podem; **PVC e vinil nunca**, porque soltam cloro, que é tóxico e corrói a máquina. Na dúvida sobre um material, perguntar no colégio antes.

### Peças impressas

- Korry switches, em duas cores ([korry/](korry/README.md)), e uma grade por grupo (9 grades, 17 parafusos M3) para prender as bases atrás do painel.
- A capa do korry IVA.
- A alavanca do acelerador, encaixada na haste do potenciômetro deslizante.
- Tecla do TEMPO do editor de manobras, se a basculante pronta não funcionar bem deitada: uma tecla impressa sobre dois botões táteis, com uma mola que a traz de volta ao meio.
- Moldura da tela de 7".
- Suportes das placas, do Mega e do Pi, com os furos no lugar certo.
- Passa-cabos e presilhas para os cabos flat.

PLA serve para tudo. Peças que ficam perto do Pi ou de LEDs fortes podem amolecer com o calor; nesse caso, PETG.

### Medir antes de cortar

Cada chave, botão e encoder tem um diâmetro de rosca e uma espessura máxima de painel. Antes do painel de verdade:

1. Medir cada peça com paquímetro e anotar numa tabela aqui.
2. Cortar uma **plaquinha de teste** com um furo de cada tipo, em vários diâmetros (por exemplo 6,0 / 6,2 / 6,4 mm). A laser queima um pouco de material em volta do corte, e o furo sai maior que o desenho.
3. Conferir que a porca da chave alavanca e a trava do botão arcade prendem no painel de 3 mm.

## Os painéis

Um por seção, todos desenhados com as peças reais. O que cada controle faz no jogo foi conferido no código-fonte do kRPC: quase tudo existe na versão 0.6, a lançada. A exceção é a EVA (ver [Recursos e EVA](#recursos-e-eva)).

## Tela multifunção

Tela multifunção: tela de 7 polegadas no meio, VOO e ORBITA à esquerda, DELTA-V e SUBIDA à direita, o alto-falante dos avisos e SILENCIAR

- **Uma tela só, de 7", no meio:** a Waveshare de 1024 × 600 com toque, ligada no HDMI do Pi, mostrando em tela cheia a mesma página do celular ([docs/mfd.md](../docs/mfd.md)). Ocupa a altura toda do painel duplo, sem título. A mikromedia saiu do cockpit; o firmware dela continua no repositório.
- **PAGINA:** quatro botões escolhem a página: VOO (a navball), ORBITA, DELTA-V e SUBIDA. As outras páginas (SAS, PILOTO, POUSO, MANOBRA, ALVO, TEMPO, EVA) abrem sozinhas quando o painel delas é mexido. Os botões não têm luz: a própria tela mostra a página.
- **AVISOS:** a grade do alto-falante USB dos [avisos de voo](../docs/avisos.md). **SILENCIAR** cala o aviso que está tocando.
- 5 entradas, nenhum LED: placa pequena.

## Painel de sistemas de controle

Na versão B, o painel **VOO**: os modos do SAS, os sistemas e o piloto automático de avião, num painel duplo embaixo da tela. O que cada controle faz está no roteiro do [piloto automático](../README.md#piloto-automático-de-avião) e no [protocolo](../docs/protocolo.md#painel-de-sistemas-de-controle).

Painel VOO: dez korry de modo do SAS com o PRO aceso em verde, korry SAS, RCS, FBW e TRAVA ALT, e o encoder do piloto automático com as luzes HDG, ALT, V/S e ESTOL

- **MODOS DO SAS:** os 10 modos em pares, o modo em cima e o oposto embaixo: ESTAB e MANOBRA, PRO e RETRO, NORMAL e ANTINRM, RAD FORA e RAD DENTRO, ALVO e ANTIALVO. A legenda é o marcador da navball, com a palavra embaixo. Cada korry tem um LED de duas cores: **azul** enquanto a nave vira para o marcador, **verde** quando chegou e o SAS segura nele, apagado quando o modo não está escolhido. Apertar um modo que o jogo não aceita (sem alvo, sem nó de manobra, SAS fraco) não faz nada.
- **SISTEMAS:** SAS, RCS, FBW e TRAVA ALT. A metade de baixo acende em âmbar quando falta alguma coisa: `SEM EC` (o SAS sem carga elétrica), `SEM MP` (o RCS sem monopropelente) e `DIRETA` (o avião no ar na lei direta).
- **PILOTO AUTO:** um encoder só para HDG, ALT e V/S, mexido pelo menu da página do piloto na tela multifunção: girar move o cursor, apertar escolhe a linha e girar muda o valor, apertar de novo sai, e segurar 1 s liga ou desliga o modo da linha. Três luzes verdes mostram, sem olhar a tela, quais modos estão ligados. Embaixo delas, a luz vermelha **ESTOL** pisca quando o ângulo de ataque passa de 14,5°, e a tela toca um alarme. É só o aviso: o FBW não mexe em nada ([docs/fbw.md](../docs/fbw.md#aviso-de-estol)).
- 17 entradas (10 modos, 4 korry e as 3 do encoder) e 31 LEDs: placa grande, com 4 × 74HC595. O desenho de 150 mm, com o mesmo conteúdo, está em [`img/antigos/sistemas.svg`](img/antigos/sistemas.svg).

## Painel do editor de manobras

Painel duplo, de 250 × 125 mm. O que cada controle faz está no [roteiro da fase 4](../README.md#fase-4--instrumentos-físicos) e no [protocolo](../docs/protocolo.md#no-painel).

Painel do editor de manobras: korry PRO, NRM e RAD com o PRO aceso, encoder de ajuste, grupo PERCURSO, chave rotativa do passo e botões NOVO, APAGAR e CIRC

- **DELTA-V:** três korry escolhem o eixo (PRO, NRM, RAD), e o encoder mexe nele: horário soma, anti-horário tira. A legenda do eixo escolhido acende na cor da alça do nó no KSP: verde-amarelo, magenta e ciano.
- **PERCURSO:** anda pelo caminho da nave, nos dois sentidos. A tecla do TEMPO, deitada, move o nó pela órbita; ANT e PROX, embaixo dela e no mesmo sentido, trocam de nó.
- **PASSO:** chave rotativa com a legenda gravada em volta. O ponteiro do knob mostra o passo, sem LED e sem olhar a tela.
- **NO:** NOVO, APAGAR e CIRC, botões de 16 mm: não têm estado para mostrar.
- **Sem tela:** os números do nó vão para a página do editor na tela multifunção.
- 16 entradas e 3 LEDs: placa média. O desenho de 150 mm está em [`img/antigos/editor_manobras.svg`](img/antigos/editor_manobras.svg).

## Ação executiva

STAGE, ABORT e os scripts de voo, no centro, a um palmo do acelerador.

Ação executiva: ABORT na faixa zebrada e STAGE, os dois com capa transparente, e os seis korry dos scripts com o POUSO aceso

- **ABORT** na faixa zebrada e **STAGE** embaixo, os dois botões de metal de 22 mm debaixo de uma capa transparente que abre. O anel de LED de cada um mostra o estado: o ABORT acende em vermelho depois de acionado (`control.abort`); o STAGE, em âmbar, com a trava de estágio do jogo ligada (`control.stage_lock`).
- 8 entradas e 14 LEDs, com os scripts: placa média.

### Painel de scripts

Os scripts de voo que pilotam a nave sozinhos, um korry por script, na metade direita da ação executiva. O que o script faz está no roteiro da [fase 5](../README.md#fase-5--protocolo-v1--scripts-de-voo) e no [protocolo](../docs/protocolo.md#painel-de-scripts).

- **Na ordem do voo:** três fileiras de cima para baixo, como a nave: subida (LANCAR), órbita (EXEC e ENCONTRO) e descida (POUSO e PRECISAO). O POUSO fica embaixo, o mais perto da mão.
- **Segurar 5 s:** o korry só liga o script depois de 5 s apertado, e segurar de novo 5 s aborta: o script corta o motor e devolve a nave ao piloto. Soltar antes não faz nada. Assim não precisa de chave ARM, e um toque sem querer não entrega a nave. Enquanto conta, a tela multifunção abre a página do script e mostra quantos segundos faltam.
- **A luz mostra o script, não o aperto:** apagado parado; **âmbar piscando** enquanto conta para ligar; **verde** com o script voando (piscando âmbar enquanto conta para abortar); **vermelho** por 10 s se o script foi abortado ou falhou. Quando a nave pousa, apaga, e a tela mostra `POUSADA`.
- **Lugares vagos:** cinco korry com a legenda em cinza, esperando os próximos scripts do [roteiro](../README.md#scripts-de-voo). O korry ganha a legenda quando o script existir; o furo e os fios já ficam prontos.
- **Sem tela:** a fase, a altura, a descida e a freada aparecem na página POUSO da tela multifunção ([docs/mfd.md](../docs/mfd.md#painel-de-scripts-e-a-página-do-pouso)).
- O desenho de 150 mm, quando os scripts tinham painel próprio, está em [`img/antigos/scripts.svg`](img/antigos/scripts.svg).

## Tempo

Tempo: tecla do WARP, PARAR, korry FISICO e ATE O NO em cima; PAUSA, SALVAR, e CARREGAR e REVERTER com capa embaixo

- **ACELERAR:** a tecla do WARP, deitada como a do editor: para a esquerda mais devagar, para a direita mais rápido (`rails_warp_factor` e `physics_warp_factor`). Segurando, repete. **PARAR** volta ao tempo normal. **FISICO** escolhe o warp físico e acende em branco com ele ligado (`warp_mode`). **ATE O NO** acelera até o próximo nó de manobra (`warp_to`).
- **JOGO:** PAUSA (`krpc.paused`), SALVAR (`quicksave`), CARREGAR (`quickload`) e REVERTER (volta ao lançamento, `revert_to_launch`). Os dois últimos perdem o voo atual e ficam debaixo de capas impressas.
- 9 entradas e 1 LED: placa média.

## Navegação

Navegação: encoder do alvo e LIMPAR, chave rotativa da referência da navball, e ANT e PROX para trocar de nave

- **ALVO:** girar o encoder percorre as naves e os planetas na página ALVO da tela; apertar escolhe (`target_vessel`, `target_body`). LIMPAR tira o alvo (`clear_target`).
- **REFERENCIA:** o modo da navball: AUTO (troca sozinho, como no KSP), SUP, ORB ou ALVO. A ponte deixa a navball do jogo igual (`control.speed_mode`).
- **NAVES:** ANT e PROX trocam a nave ativa (`active_vessel`).
- 10 entradas, nenhum LED: placa média.

## Action groups

Action groups: oito botões e os korry PARAQUEDAS, SOLAR, ANTENAS e CARGA

- **GRUPOS:** os action groups 1 a 8, botões de 16 mm em duas fileiras de 4 (`toggle_action_group`). Não têm luz: o que cada grupo faz muda de nave para nave. O 9 e o 10 ficam no teclado: com o anel de 20 mm, 5 botões por fileira não cabem no painel.
- **PECAS:** PARAQUEDAS, SOLAR, ANTENAS e CARGA (`control.parachutes`, `solar_panels`, `antennas`, `cargo_bays`), em korry verdes que acendem com as peças abertas.
- 12 entradas e 4 LEDs: placa média.

## Câmera

Câmera: korry MAPA, korry IVA com capa, MODO CAM, FOTO e ESCONDER

- **VISTA:** MAPA e IVA, korry brancos que acendem com o mapa aberto e com a vista de dentro da cabine (`camera.mode`). O IVA fica debaixo de uma capa. MODO CAM passa pelos modos da câmera: automático, livre, perseguição, travado e orbital.
- **IMAGEM:** FOTO (`screenshot`, salva no PC do jogo) e ESCONDER, que esconde a interface do jogo (`ui_visible`).
- O modo do manche saiu daqui: é o botão do [sidestick](#sidestick).
- 5 entradas e 2 LEDs: placa pequena.

## Recursos e EVA

Recursos e EVA: quatro barras de 10 LEDs e os controles do kerbal

- **RESTANTE:** quatro barras de 10 LEDs, com o que resta no estágio atual de combustível líquido, oxidante, monopropelente e eletricidade. As barras são acesas por um MAX7219 ligado direto no Mega, fora do backplane.
- **EVA:** o kerbal fora da nave. JATO abre a mochila e LUZ liga a lanterna do capacete, os dois korry no meio; embaixo, numa fileira, SAIR, EMBARCAR, AGARRAR e SOLTAR (a escada). Andar, virar e voar com a mochila são feitos pelo sidestick, e a barra MONO mostra a mochila.
- **Precisa do kRPC 0.7:** no 0.6, o kRPC não mexe num kerbal em EVA (`control.rcs` e `lights` só ligam os grupos da nave, e não há como andar, sair ou embarcar). O 0.7 traz tudo isso, mas ainda não foi lançado. Não há comando para pular em nenhuma versão.
- 6 entradas e 2 LEDs: placa pequena.

## Acelerador

Acelerador: alavanca deslizante com 60 mm de curso e os korry TREM, FREIOS e LUZES

- **EMPUXO:** um potenciômetro deslizante de 60 mm (Bourns PTA6043), com uma alavanca impressa. Para cima acelera. É o único acelerador: a alavanca do joystick não é usada.
- **RODAS E LUZES:** TREM, FREIOS e LUZES (`control.gear`, `brakes`, `lights`), em korry verdes, ao lado do acelerador, como num avião.
- 3 entradas, 3 LEDs e 1 linha analógica: placa pequena num dos slots 1 a 5.

## Sidestick

Sidestick: joystick de 3 eixos com botão e as luzes dos modos VOO, CAMERA e TRANSL

- **O joystick:** um JH-D400X-R4 para Arduino, com 3 eixos de 10 kΩ (X e Y ±25 a 30°, torção ±45°) e um botão no topo. Na ponta da asa direita, como o sidestick de um Airbus. Fios: VCC, GND, os 3 eixos e o botão.
- **Lido pelo Mega:** os 3 eixos vão nas 3 linhas analógicas de um dos slots 1 a 5 do backplane; o botão e as luzes, numa placa pequena. A ponte recebe os eixos pela serial e os manda ao jogo como faria com o Extreme 3D Pro.
- **O botão troca o modo:** cada aperto passa para o próximo, VOO, CAMERA e TRANSL, e volta ao VOO ([os três modos](#um-joystick-três-modos)). A ponte só troca com o manche no centro, para não dar tranco. Três luzes brancas mostram o modo, porque um botão não tem posição.
- **Em EVA**, o manche anda e voa com o kerbal (kRPC 0.7).
- 1 entrada, 3 LEDs e 3 linhas analógicas: placa pequena.

## Korry switches

O **korry** é o botão iluminado quadrado dos aviões: a legenda fica no próprio botão e acende. Muitos têm a legenda dividida em duas metades, cada uma com a sua luz: em cima o sistema (`SAS`), embaixo um aviso (`OFF`, `FAULT`).

### Por que usar

O korry combina com o princípio do painel: **o botão só manda "apertei", e a luz mostra o estado do jogo.**

Com uma chave alavanca, a chave pode ficar para cima com o SAS desligado pelo jogo, e o piloto tem que olhar o LED para saber a verdade. O korry não tem posição: cada toque pede "troque o estado", e a legenda acesa é sempre o que o jogo diz. Não há como a chave e o jogo discordarem.

- **Bons candidatos:** tudo que o jogo também pode mudar sozinho, ou pelo teclado. SAS, RCS, luzes, freios, trem de pouso, action groups, modos do piloto automático de avião (HDG, ALT, V/S, SPD).
- **Continuam como chave alavanca com capa:** o que precisa de duas ações de propósito. STAGE e ABORT continuam como botões grandes, com capa. Os scripts não precisam de chave ARM: o korry do script só liga segurado 5 s ([painel de scripts](#painel-de-scripts)).

### Como fazer

A peça tem ficha própria em [korry/](korry/README.md): medidas, desenho, peças, circuito, brilho e o que cada luz diz. Resumo:

- **Um tamanho só, 21,9 × 21,9 mm**, em todo o cockpit. Furo de 23 × 23 mm no painel.
- **Legenda em duas metades**, como o START do A320: em cima só as letras, embaixo as letras numa caixa. Ou uma legenda única, sem a divisória.
- **Legenda modular em duas cores, encaixada na ponta de um corpo igual para todos:** a legenda é impressa em preto e transparente numa peça só, com as letras vazadas numa camada preta. Só ela muda de korry para korry. Sem laser e sem cola.
- **Uma grade por grupo:** as bases dos korry de um grupo saem numa peça só, impressa em preto e parafusada atrás do painel com M3 pela frente (furo de 3,2 mm no painel). Os korry ficam a no mínimo 25,5 mm de centro a centro, e os parafusos aparecem nos desenhos dos painéis. Ver [Fixação no painel](korry/README.md#fixação-no-painel).
- **Chave PSW 8,5 × 8,5 e os LEDs encaixados num suporte impresso**, com um LED por metade e a chave no meio, que o apoio da divisória aperta. Um rabicho de 4 fios com JST-XH: GND, botão, LED de cima e LED de baixo.
- **LEDs comuns, pelas saídas do 74HC595 do módulo.** A cor é a do LED, fixa por metade.

**Alternativa pronta:** botões quadrados iluminados de 16 mm, vendidos no AliExpress. São mais fáceis, mas têm uma luz só, de uma cor, e a legenda fica por conta própria.

### No painel e no firmware

- **Cada korry usa 1 entrada e 1 ou 2 LEDs** de um módulo. A legenda de duas metades gasta mais LEDs que entradas, o contrário das chaves: a [tabela de seções](README.md#qual-placa-e-qual-etiqueta-em-cada-seção) já conta os LEDs dos korry da versão B.
- **Protocolo:** o korry manda um evento de botão (`BTN SAS 1`) em vez de chave (`SW SAS 1`), e a ponte inverte o estado no jogo. A mudança fica toda na ponte: o firmware já manda botões.

## Joystick: Logitech Extreme 3D Pro

**Fora do cockpit da versão B:** no painel, o manche é o [sidestick](#sidestick) e o acelerador é a [alavanca própria](#acelerador). O Extreme 3D Pro continua servindo para desenvolver e testar no PC (o FBW tem um perfil para ele, em [docs/fbw.md](../docs/fbw.md)). O mapeamento e os três modos abaixo valem para os dois.

**O que ele tem:** 4 eixos (X, Y, torção do manche e uma alavanca de acelerador na base), 12 botões e um chapéu (*hat*) de 8 direções no topo. Liga por USB e o computador o vê como um joystick comum (HID).

### Como entra no projeto

**Ligado na USB do Pi e lido pela ponte**, que manda os comandos para o jogo pelo kRPC. O jogo não enxerga o joystick.

```
 Extreme 3D Pro ──USB──▶ Raspberry Pi (ponte) ──kRPC──▶ KSP
```

- **Por que assim:** o joystick passa pelo mesmo lugar que o painel. A ponte pode aplicar zona morta, curva de resposta e os modos (voo, câmera e translação), e sabe na hora quando o piloto mexe no manche. Isso é o que devolve o controle ao piloto quando um script está voando (ver a [base comum dos scripts](../README.md#base-comum)).
- **Sem abrir o joystick:** ele continua inteiro e pode voltar a ser usado em outros jogos.
- **Leitura:** pelo `pygame`, que a ponte já usa, ou pelo `evdev`, direto no Linux. Decidir quando for escrever o código.
- **Durante o desenvolvimento no PC:** com o joystick ligado no PC, o KSP também o lê. Deixar os eixos do joystick sem nada nas configurações de controle do KSP, senão os comandos chegam em dobro.
- **O Pi 4 tem 4 portas USB:** Mega, mikromedia e joystick cabem, e sobra uma.

### Um joystick, três modos

**Um joystick só**, sem um segundo para a translação: o **botão do manche do sidestick** passa pelos três modos, e três luzes mostram o modo atual. A ponte lê o botão e manda o manche para um lugar ou outro. (Antes era uma chave de 3 posições no painel.)

| Posição | Modo | O manche mexe em |
|---|---|---|
| Cima | **VOO** | A atitude da nave (ou do avião, pelo [fly by wire](../docs/fbw.md)) |
| Meio | **CÂMERA** | A câmera: a de voo, ou a do mapa quando ele está aberto. Substitui os botões de câmera provisórios do [editor de manobras](../docs/manobras.md#câmera-do-mapa-temporário) |
| Baixo | **TRANSLAÇÃO** | O RCS, para mover a nave sem girar: frente, trás, lados, cima e baixo. É o modo do acoplamento (no KSP, *docking mode*) |

Só uma proposta de mapeamento, para testar no jogo e mudar à vontade. O código fica para outra tarefa.

| Controle do joystick | VOO | CÂMERA | TRANSLAÇÃO (RCS) |
|---|---|---|---|
| Y (frente e trás) | Pitch | Inclina a câmera (cima e baixo) | Para cima e para baixo |
| X (lados) | Roll | Gira a câmera em volta do foco | Para os lados |
| Torção | Yaw | Aproxima e afasta (zoom) | Frente e trás |
| Alavanca da base | Acelerador | Acelerador | Acelerador |
| Chapéu | Olhar em volta, sem sair do modo | No mapa: troca o foco (nave, nó de manobra, planeta) | Olhar em volta |
| Gatilho | Segurar para mexer devagar (precisão) | Idem | Idem |
| Botão do polegar | Livre (a troca de modo foi para a chave) | Livre | Livre |
| Botões da base | Livres: action groups, trocar de nave | — | — |

- **Fora do modo VOO, a nave não recebe o manche:** a ponte manda pitch, roll e yaw zerados, e o SAS segura a atitude. No modo CÂMERA dá para olhar em volta com a nave parada no rumo.
- **As luzes mostram o modo:** um LED por modo no painel do sidestick, e o modo escrito na tela multifunção. Mudar de modo com o manche fora do centro não pode dar um tranco: a ponte só passa o manche para o modo novo depois que ele volta ao centro.
- **TRANSLAÇÃO pede o RCS ligado.** Se estiver desligado, a ponte avisa (LED do RCS piscando ou na tela); ligar sozinha fica a decidir.
- **STAGE e ABORT não vão no joystick:** ficam só no painel, debaixo das capas, para não serem apertados sem querer.
- **O botão MAPA** (liga e desliga o mapa) fica no painel da câmera.

### Acelerador

A alavanca da base do joystick é curta (uns 3 cm de curso). No cockpit, o acelerador é uma alavanca própria, com um potenciômetro deslizante de 60 mm, no [painel do acelerador](#acelerador). A alavanca do joystick não é usada.

### Na mesa

Para desenvolver no PC, o Extreme 3D Pro fica solto na mesa. No cockpit, o sidestick é um painel, sem joystick solto.

## Arquivos

- **Desenhos dos painéis:** em código, em [`desenho/`](desenho/README.md), com os SVG em [`img/`](img/).
- **Korry:** o modelo no OpenSCAD, os STL e o desenho da ligação em [`korry/`](korry/README.md).
- **Caixa (a fazer):** em `hardware/caixa/`, o arquivo-fonte de cada peça, paramétrico, e os SVG ou DXF para a laser e os STL para a impressora, gerados a partir do fonte.

Ferramenta de CAD: **OpenSCAD**, para as peças impressas. Desenha a peça com código, em texto, e o histórico fica legível no git, como o resto do projeto.

## Ordem para fazer

1. **Teste de folga e um korry de teste**, impressos e montados, ligados direto num pino do Mega como na [fase 2](../docs/fase2.md) ([korry/](korry/README.md#ordem-para-fazer)).
2. **Protótipo de papelão** da caixa em U, na escala real, com os furos desenhados à mão: o alcance das mãos, a inclinação e o lugar do acelerador e do sidestick.
3. **Plaquinha de teste na laser**, com os furos de cada peça, e as medidas conferidas no paquímetro.
4. **Um painel de seção de verdade**, por exemplo a ação executiva: gravado, com o módulo atrás e as capas no lugar.
5. **Caixa completa (fase 7).**

## A decidir

- JATO e LUZ na EVA: o RCS e o LUZES já abrem a mochila e ligam a lanterna do kerbal (kRPC 0.7). Podem sair, e o painel fica com mais espaço.
- A chave REFERENCIA da navegação: o modo da navball já troca sozinho e pelo toque na tela.
- EVA: esperar o kRPC 0.7, compilar do GitHub ou um programa no PC do jogo que aperta as teclas da EVA.
- O furo do joystick JH-D400X-R4, quando ele chegar.
- MDF pintado ou acrílico nos painéis definitivos, e se as legendas dos painéis serão iluminadas.

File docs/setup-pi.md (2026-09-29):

# Preparando o Raspberry Pi 4 (Fase 0)

Passo a passo para deixar o Pi lendo telemetria do KSP pela rede, com os problemas que já apareceram e como foram resolvidos.

**Como funciona:** o mod kRPC, dentro do KSP no PC, é um **servidor**. O Pi roda um script Python que é **cliente**: ele conecta no PC pela rede (porta 50000 para comandos, 50001 para *streams*). Quem inicia a conexão é o Pi. O PC nunca precisa encontrar o Pi.

---

## 1. Gravar o cartão (no PC)

1. Baixar o [Raspberry Pi Imager](https://www.raspberrypi.com/software/).
2. Dispositivo **Raspberry Pi 4**, sistema **Raspberry Pi OS (64-bit)** com desktop, e o cartão microSD. A gravação apaga o cartão.
3. Na personalização, preencher:
   - nome da máquina (hostname), por exemplo `ksp-cockpit`;
   - usuário e senha;
   - Wi-Fi da **mesma rede do PC**, país **BR**;
   - fuso `America/Sao_Paulo`, teclado `br`;
   - **SSH ativado**, com senha.
4. Esperar a gravação **e a verificação** terminarem antes de tirar o cartão.

## 2. Primeiro boot

Colocar o cartão no Pi (slot embaixo da placa) e ligar. O primeiro boot leva de 2 a 3 minutos e reinicia sozinho uma vez.

| LED | Significado |
|---|---|
| Vermelho fixo | Está recebendo energia. Só isso. |
| Vermelho piscando ou apagando | Fonte fraca. |
| Verde piscando irregular | Lendo o cartão, ligando normalmente. |
| Verde apagado | Não achou sistema no cartão. |
| Verde: 3 piscadas curtas + pausa, repetindo | Falha de boot. Regravar o cartão (item 1). |

O HDMI é a saída **HDMI0**, a mais perto da entrada USB-C.

## 3. Entrar no Pi pelo SSH

No terminal do Pi (com monitor e teclado), descobrir o IP e ligar o SSH, caso ele não tenha sido ativado no Imager:

```bash
hostname -I                     # IP do Pi
sudo systemctl enable --now ssh # liga o SSH agora e em todo boot
```

No PC, pelo PowerShell:

```powershell
ssh USUARIO@IP_DO_PI
```

Vale **usar o IP**: o nome `ksp-cockpit.local` funciona no Windows só às vezes. Para o IP não mudar, reservar um IP fixo para o Pi e para o PC no roteador ("reserva de DHCP").

## 4. Python do projeto

```bash
python3 -m venv ~/ksp
source ~/ksp/bin/activate   # repetir sempre que abrir o SSH; o prompt mostra (ksp)
pip install krpc pyserial   # pygame só a partir da fase 3
```

O Raspberry Pi OS atual recusa `pip install` fora de um *venv*.

Para a voz dos [avisos de voo](avisos.md) (GPWS), no alto-falante ligado no Pi:

```bash
sudo apt install -y espeak-ng alsa-utils
```

## 5. Código do projeto no Pi (git)

O repositório é público, então dá para clonar sem senha:

```bash
git --version               # se não existir: sudo apt install -y git
git clone https://github.com/Schackschuck/KSP.git ~/cockpit
```

Para atualizar depois de mudanças no GitHub:

```bash
cd ~/cockpit && git pull
```

Para **enviar** mudanças feitas no Pi (`git push`), é preciso se autenticar no GitHub, por exemplo criando uma chave SSH no Pi (`ssh-keygen -t ed25519`) e cadastrando a chave pública na conta do GitHub.

## 6. Preparar o PC

- **kRPC:** na janela do kRPC, parar o servidor, *Edit*, trocar o *Address* para **Any**, ativar *auto-accept* e iniciar de novo.
- **Rede do Windows como Privada:** Configurações → Rede e Internet → Wi-Fi → propriedades da rede → Tipo de perfil de rede → **Privada**. Com a rede marcada como Pública, o Windows bloqueia a conexão do Pi.
- **Firewall** (PowerShell como administrador):
  ```powershell
  New-NetFirewallRule -DisplayName "kRPC" -Direction Inbound -Protocol TCP -LocalPort 50000,50001 -Action Allow -Profile Private
  ```

## 7. Testar

No Pi, com o KSP aberto e o servidor kRPC ligado:

```bash
nc -zv IP_DO_PC 50000
```

`succeeded` significa que a rede, o firewall e o servidor estão certos. O `nc` não aparece na janela do kRPC, porque só abre e fecha a porta, sem se apresentar como cliente.

Depois, o script de verdade:

```bash
python ~/cockpit/bridge/fase0_altitude.py IP_DO_PC
```

O cliente "KSP Cockpit" aparece na janela do kRPC. Se o jogo estiver fora da cena de voo, o script espera. Quando uma nave estiver na plataforma, a altitude aparece e se atualiza no terminal.

## Problemas já encontrados

| Sintoma | Causa | Solução |
|---|---|---|
| LED verde com 3 piscadas curtas + pausa, nada no HDMI | Cartão sem sistema ou gravação ruim | Regravar com o Imager e esperar a verificação |
| `ping` do Pi para o PC não responde | O Windows bloqueia `ping` de entrada por padrão | Normal. Testar com `nc` (item 7) |
| `ping 192.168.1.1` → "Host de destino inacessível" | O roteador não fica nesse endereço | Ver o "Gateway Padrão" no `ipconfig`. Não afeta o projeto |
| `ssh` → `Connection refused` | SSH desligado no Pi | `sudo systemctl enable --now ssh` |
| `ssh` → `Could not resolve hostname ksp-cockpit.local` | Nomes `.local` são instáveis no Windows | Usar o IP |
| `sudo apt full-upgrade` com previsão de horas | Rede lenta. A atualização não é necessária para o projeto | `Ctrl+C` enquanto ainda está baixando (`Get:`) é seguro. Rodar depois, no terminal do próprio Pi |
| Conexão do Pi não chega no kRPC | Rede do Windows marcada como Pública | Mudar para Privada (item 6) |
| `-bash: ./script.py: Permission denied` | Faltou o `python` na frente | `python script.py` |
| `ValueError: Value cannot be null. Parameter name: vessel` | Jogo fora da cena de voo (KSC, hangar, menu) | Lançar uma nave. O `fase0_altitude.py` já espera sozinho |

## Manutenção

- **Desligar sempre pelo comando**, nunca puxando da tomada, para não corromper o cartão:
  ```bash
  sudo shutdown now
  ```
  Tirar da tomada só depois que o LED verde parar.
- **Atualizar o sistema** de vez em quando, direto no terminal do Pi (não pelo SSH, para não interromper se a conexão cair):
  ```bash
  sudo apt update && sudo apt full-upgrade -y
  sudo reboot
  ```

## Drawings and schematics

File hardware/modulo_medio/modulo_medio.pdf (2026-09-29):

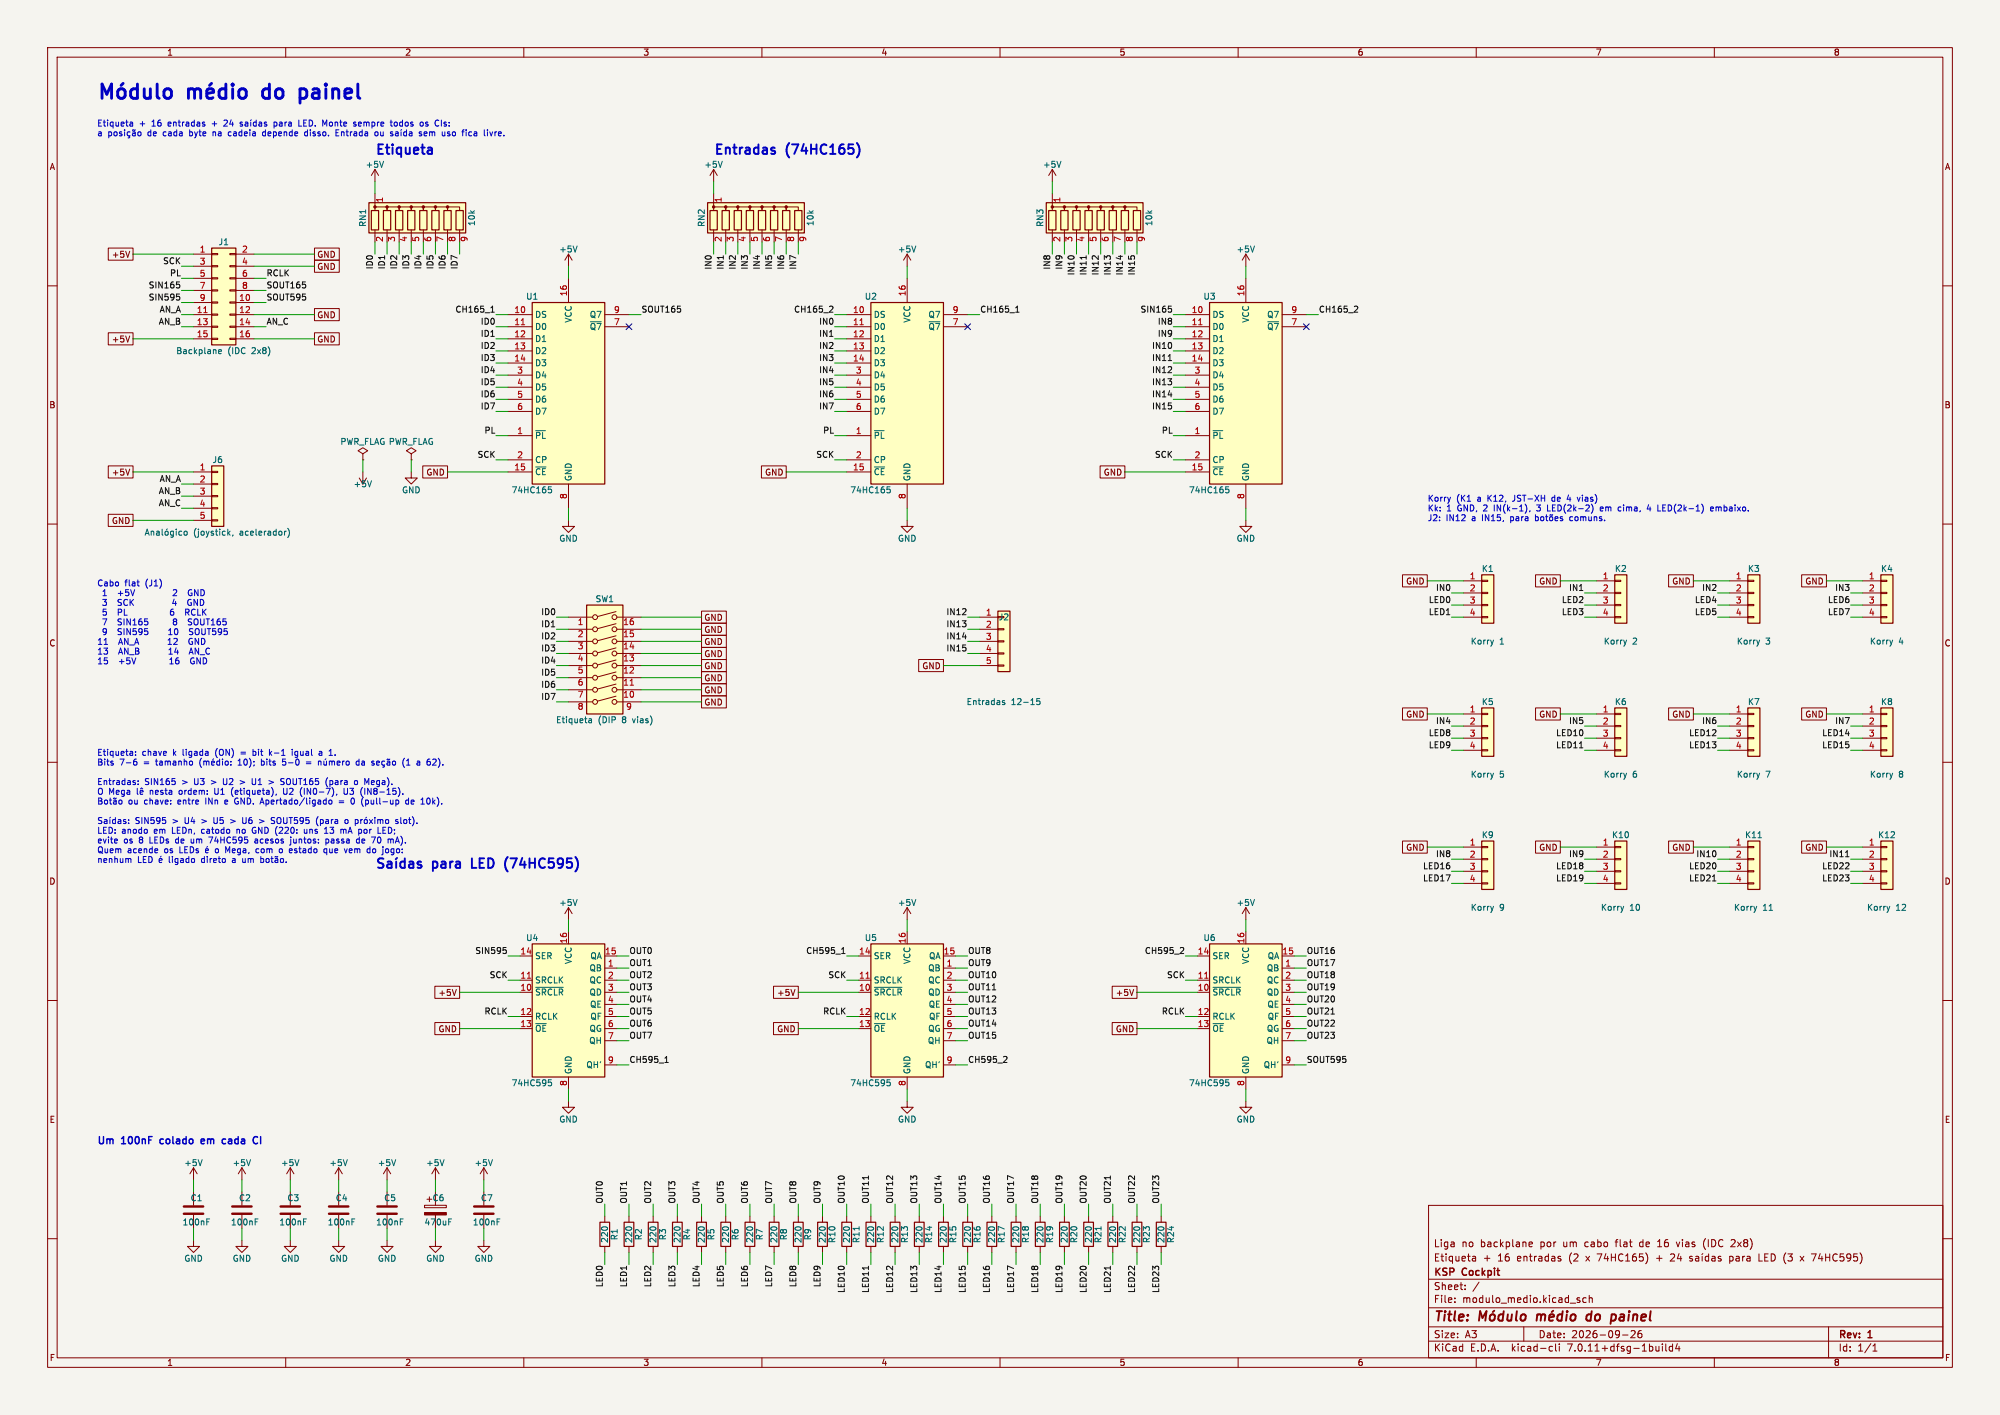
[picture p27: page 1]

þÿMódulo þÿmédio do painel

þÿSaídas: SIN595 > U4 > U5 > U6 > SOUT595 (para o þÿpróximo slot). LED: anodo em LEDn, catodo no GND (220: uns 13 mA por LED; evite os 8 LEDs de um 74HC595 acesos juntos: passa de 70 mA). Quem acende os LEDs þÿéo Mega, com o estado que vem do jogo: nenhum LED þÿéligado direto a um þÿbotão.

Um 100nF colado em cada CI

Id: 1/1 Title: þÿMódulo þÿmédio do painel File: modulo_medio.kicad_sch Sheet: / KSP Cockpit

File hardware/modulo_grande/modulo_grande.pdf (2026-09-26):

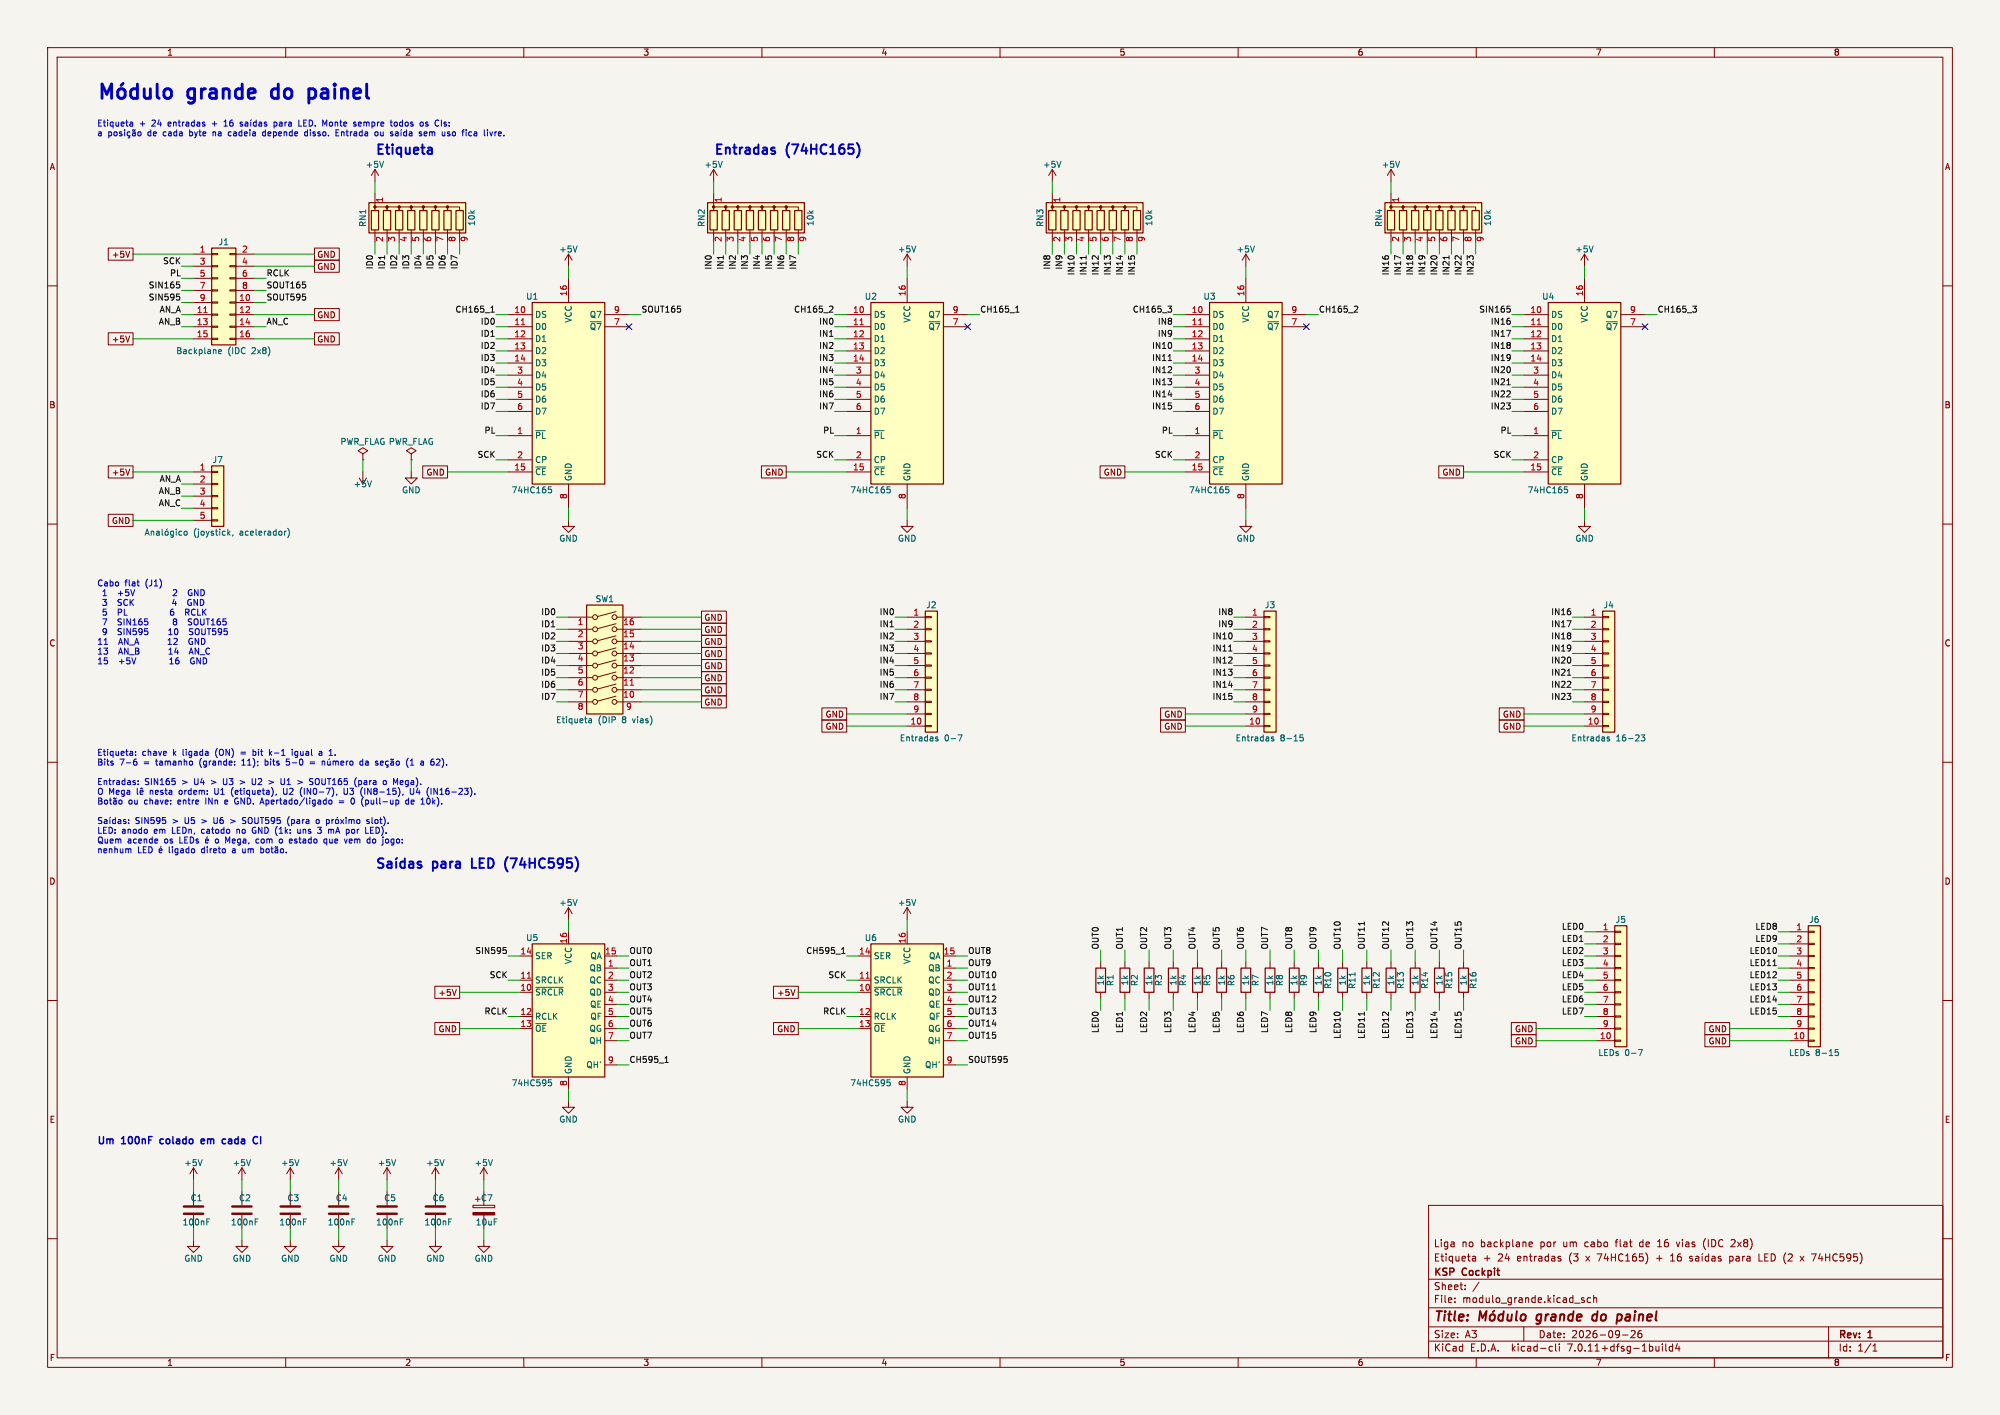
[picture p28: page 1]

þÿSaídas: SIN595 > U5 > U6 > SOUT595 (para o þÿpróximo slot). LED: anodo em LEDn, catodo no GND (1k: uns 3 mA por LED). Quem acende os LEDs þÿéo Mega, com o estado que vem do jogo: nenhum LED þÿéligado direto a um þÿbotão. Um 100nF colado em cada CI

Id: 1/1 Title: þÿMódulo grande do painel File: modulo_grande.kicad_sch Sheet: / KSP Cockpit

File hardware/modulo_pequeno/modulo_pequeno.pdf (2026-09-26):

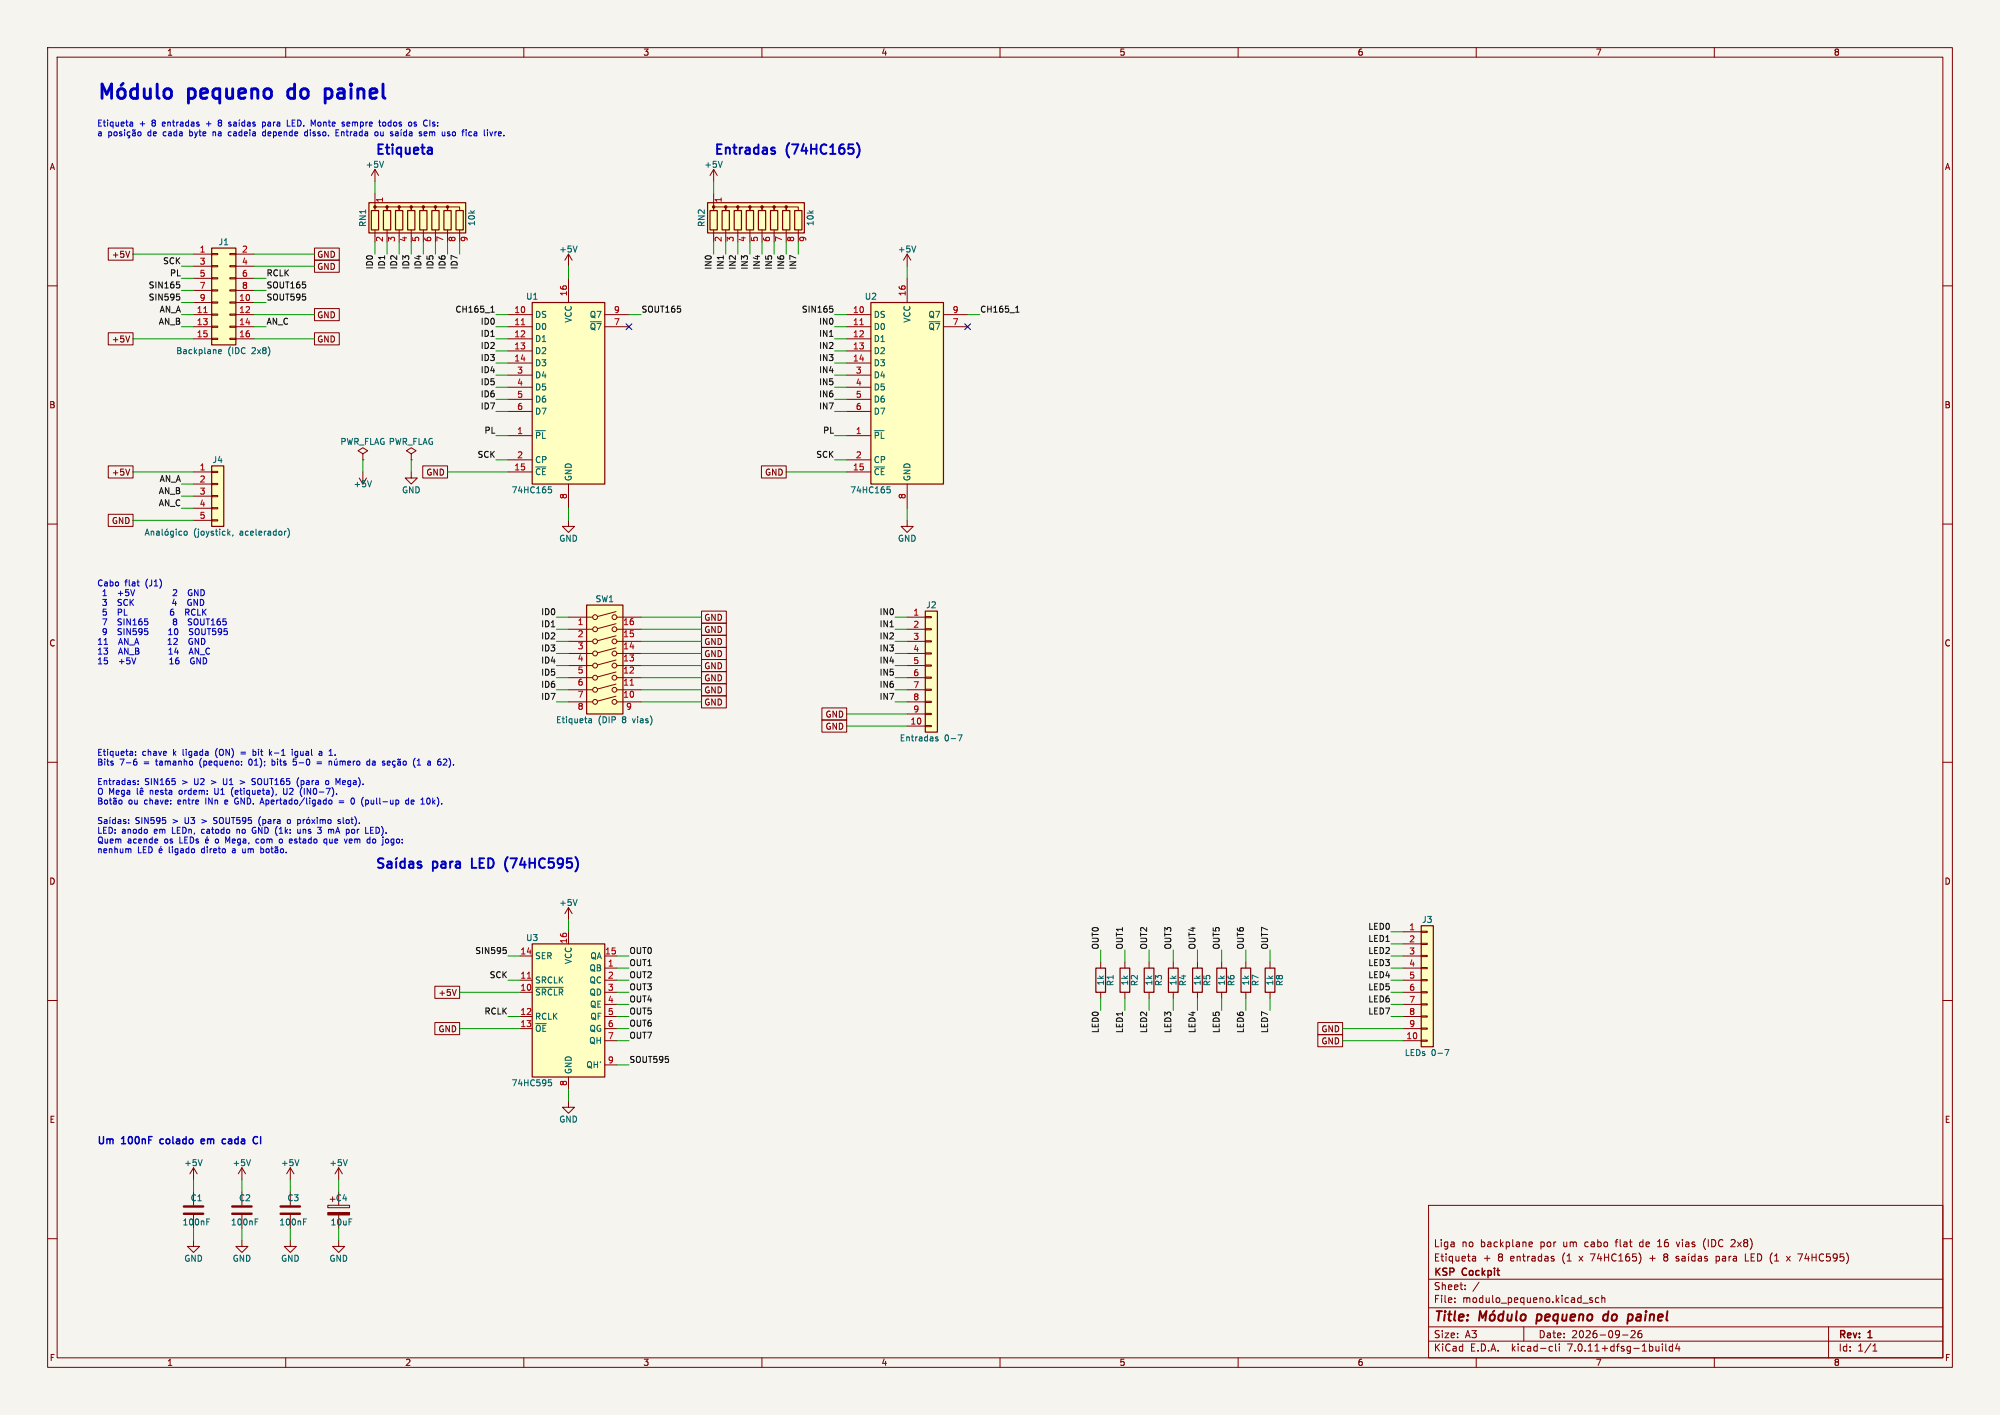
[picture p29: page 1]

þÿMódulo pequeno do painel

þÿSaídas: SIN595 > U3 > SOUT595 (para o þÿpróximo slot). LED: anodo em LEDn, catodo no GND (1k: uns 3 mA por LED). Quem acende os LEDs þÿéo Mega, com o estado que vem do jogo: nenhum LED þÿéligado direto a um þÿbotão.

Id: 1/1 Title: þÿMódulo pequeno do painel File: modulo_pequeno.kicad_sch Sheet: / KSP Cockpit

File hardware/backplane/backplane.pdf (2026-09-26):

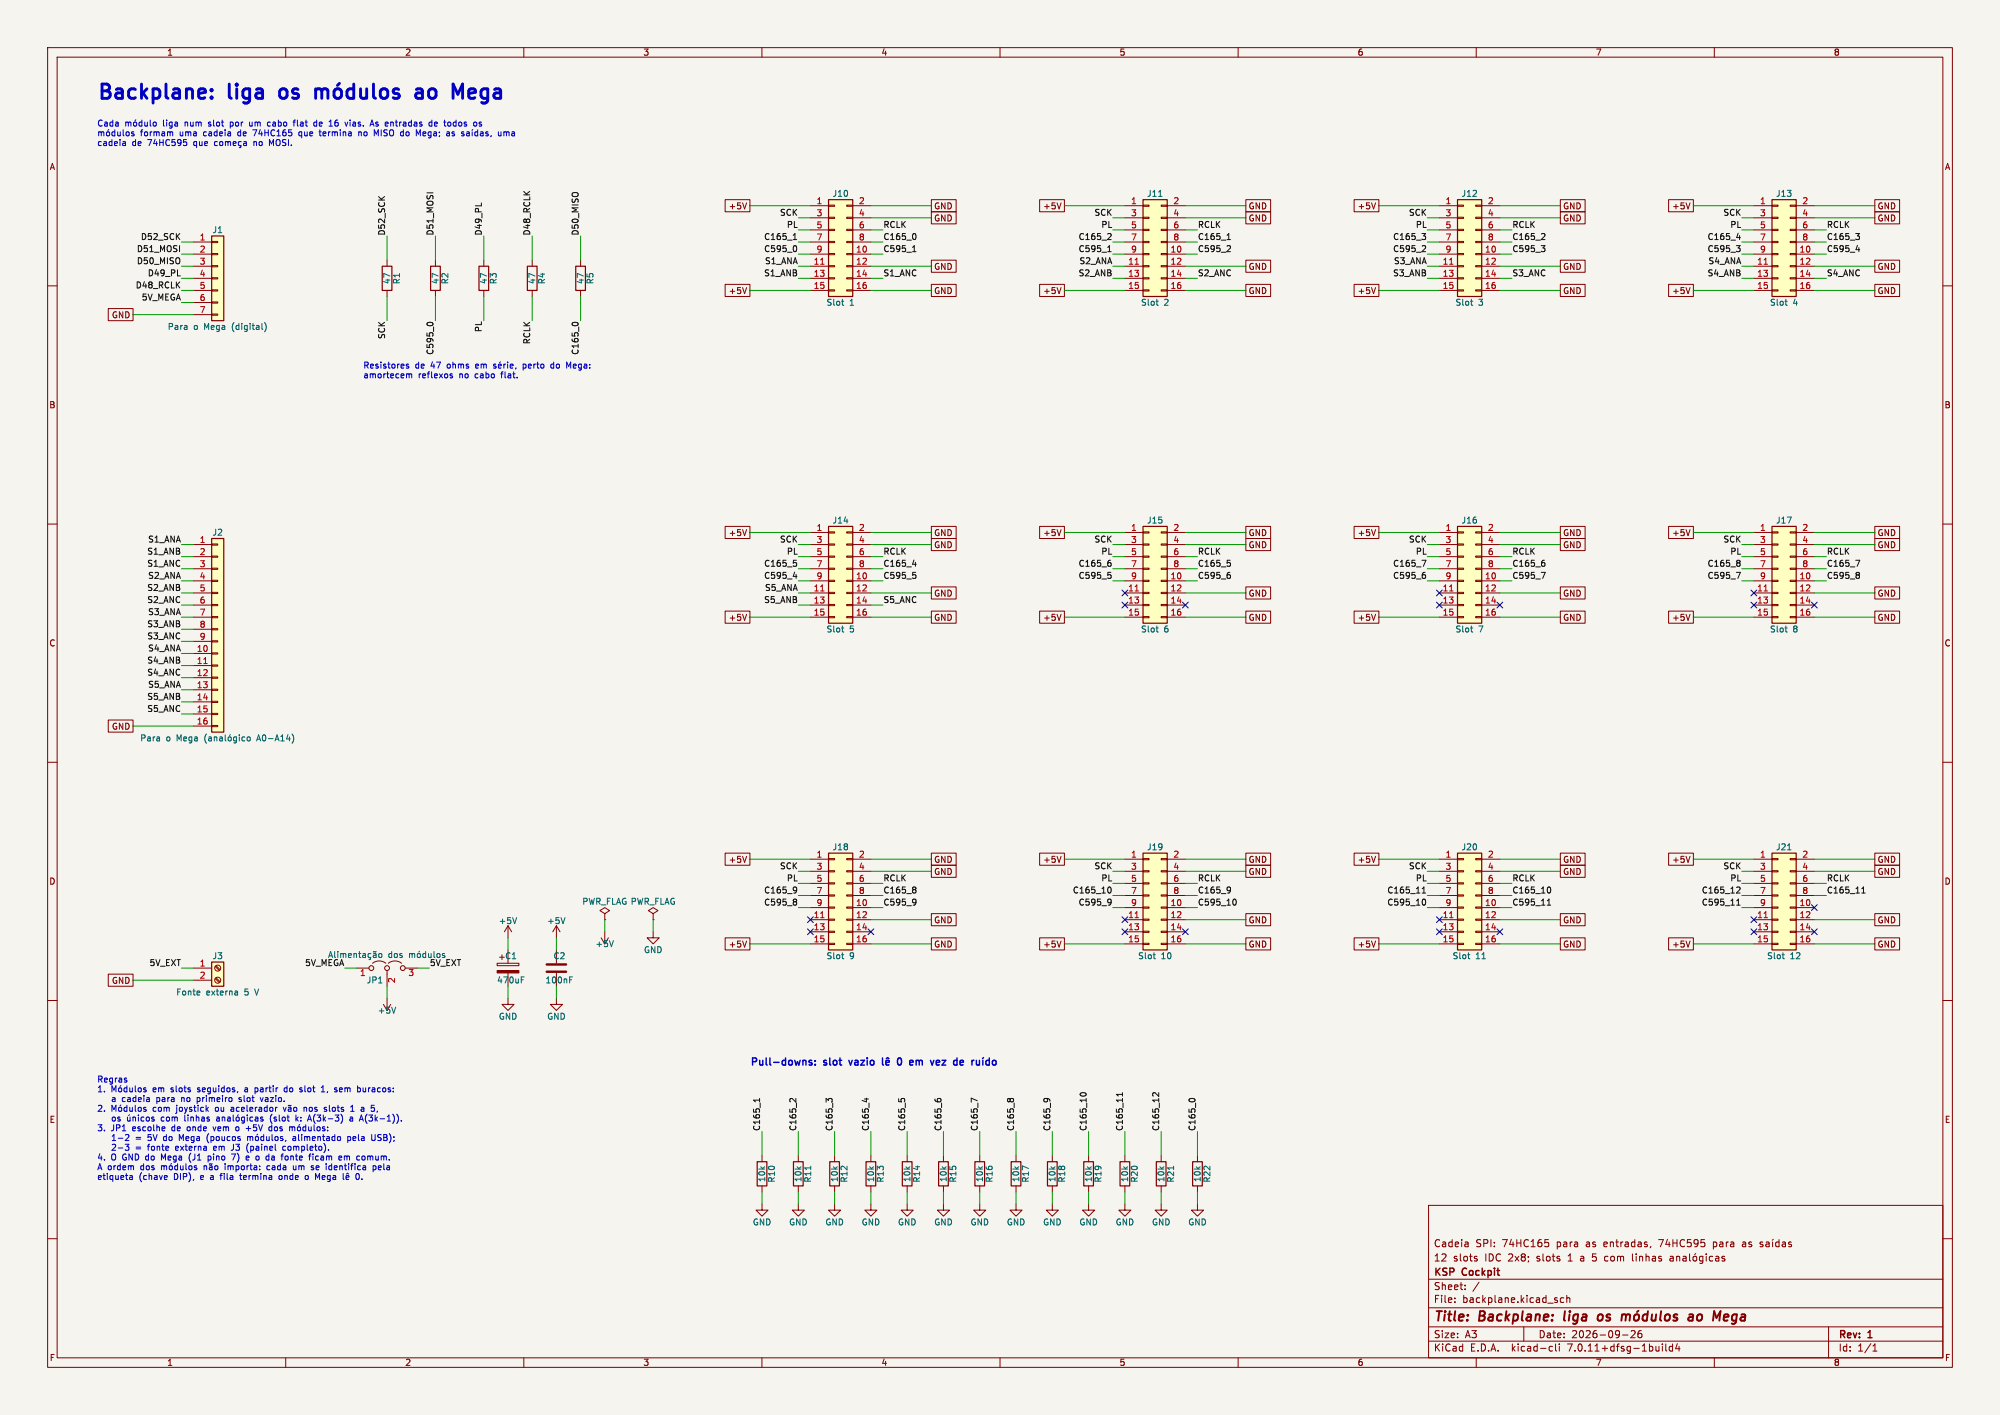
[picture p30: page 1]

cadeia de 74HC595 que þÿcomeça no MOSI.

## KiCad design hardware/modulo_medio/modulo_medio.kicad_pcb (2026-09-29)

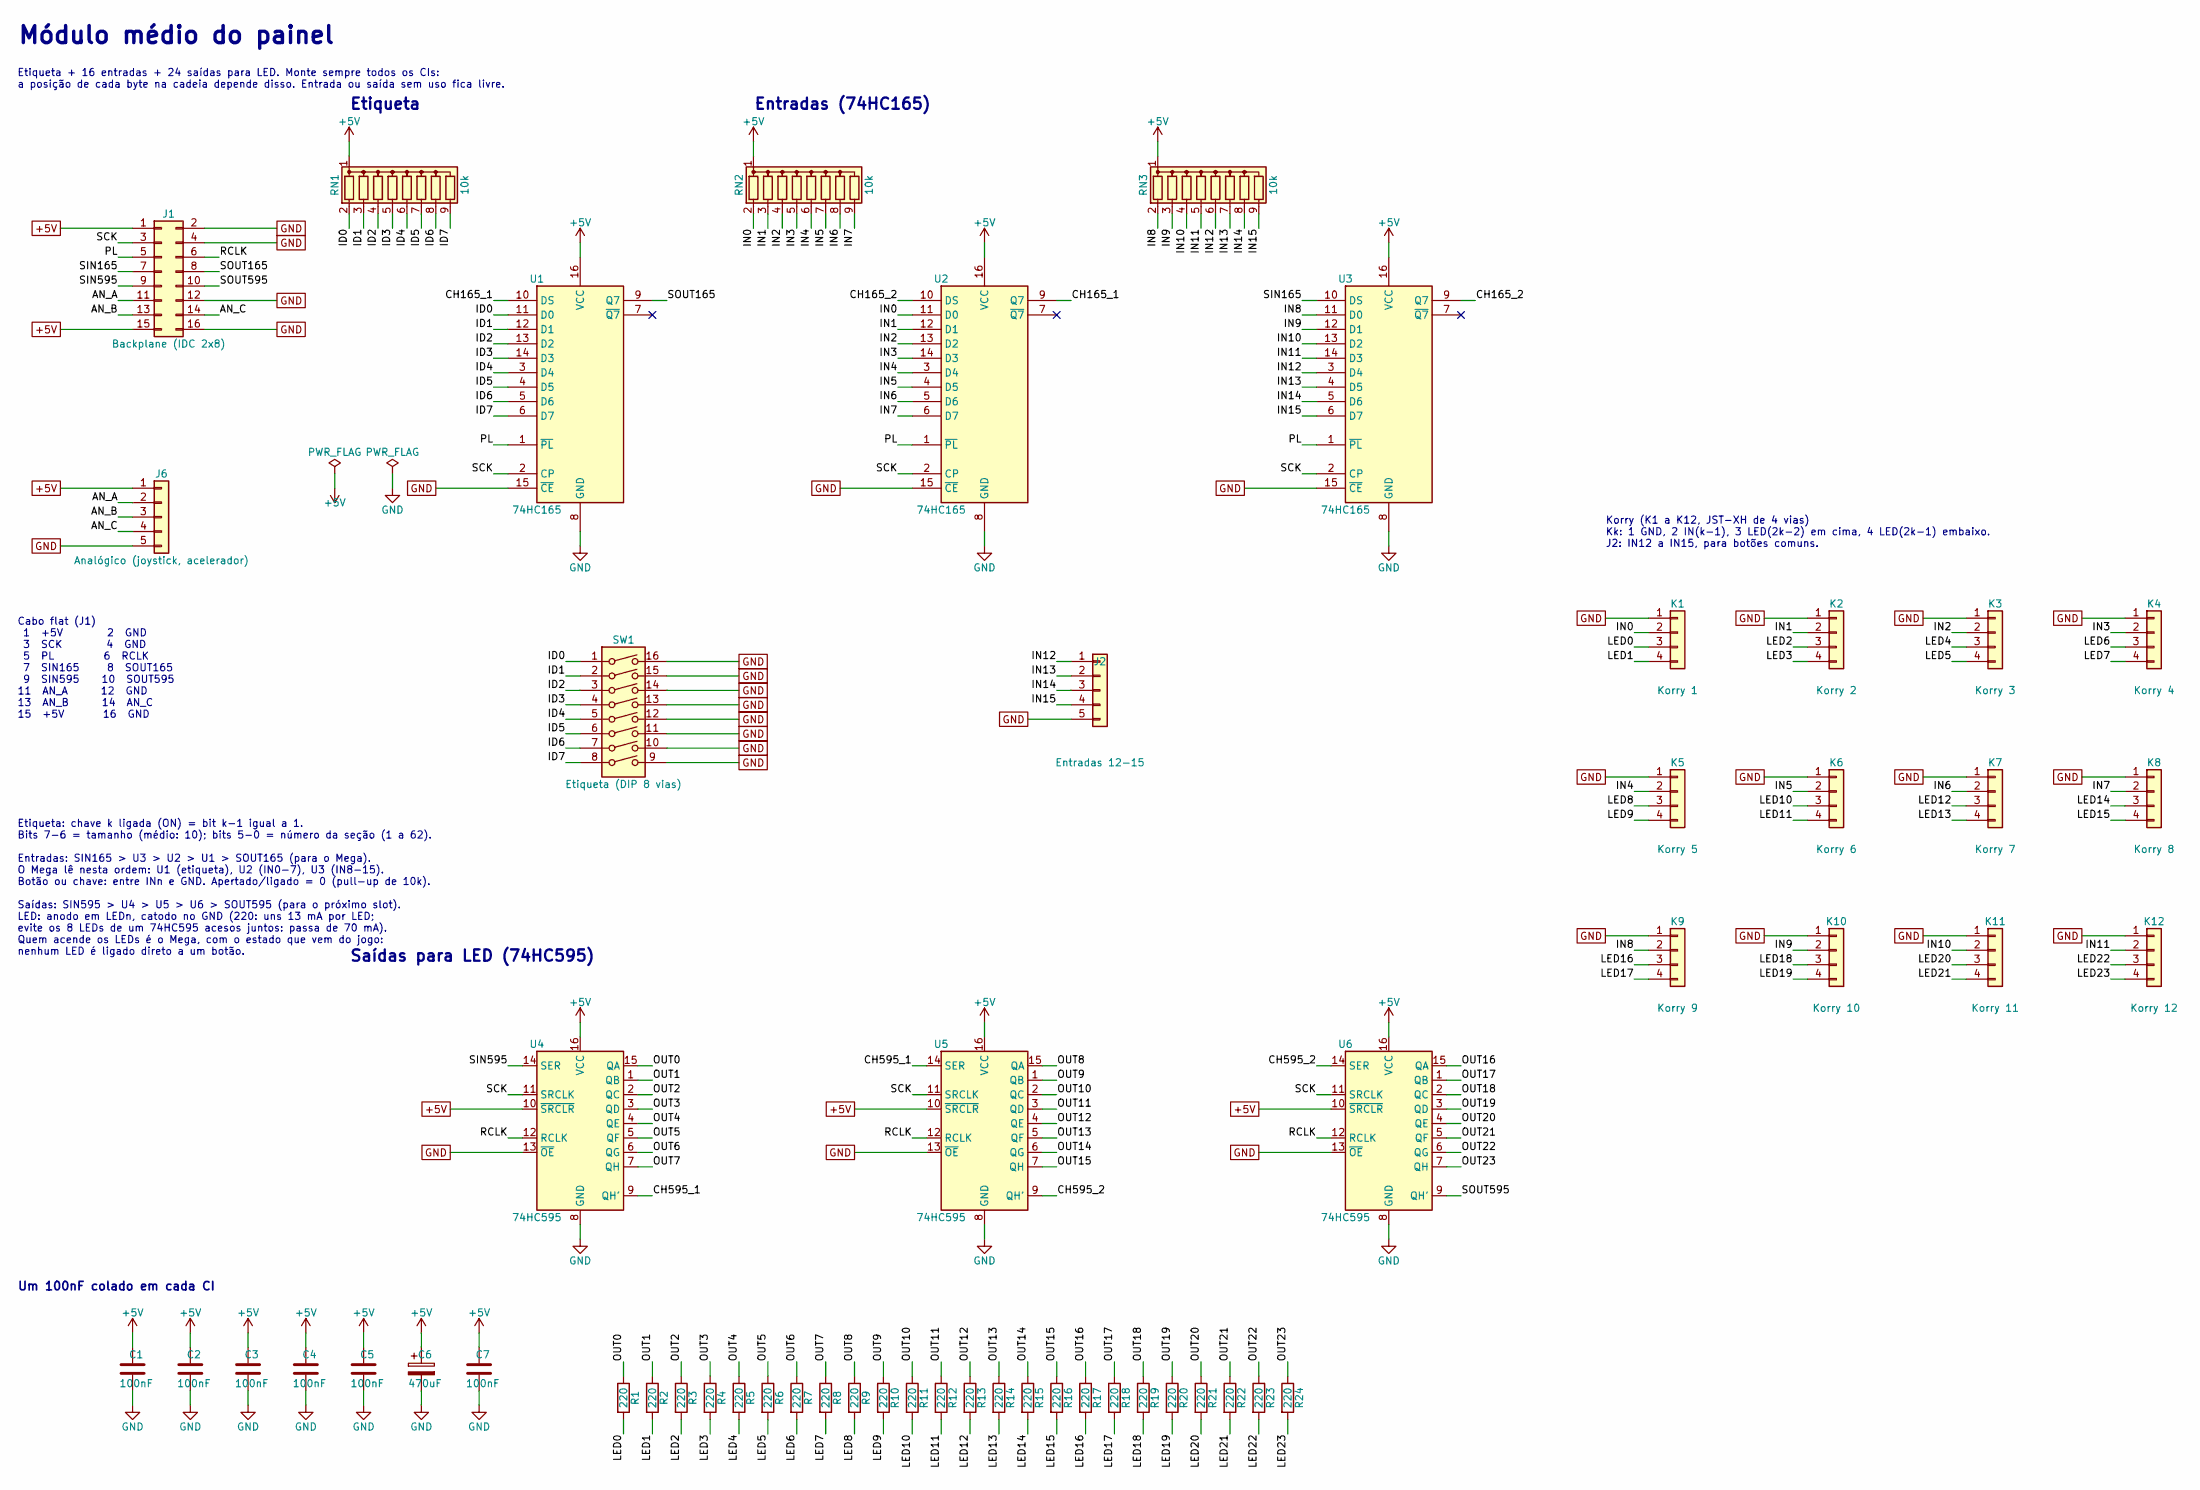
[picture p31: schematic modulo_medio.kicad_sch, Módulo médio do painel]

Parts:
C1, C2, C3, C4, C5, C7: 100nF; C_Disc_D5.0mm_W2.5mm_P5.00mm
C6: 470uF; CP_Radial_D10.0mm_P5.00mm
J1: Backplane (IDC 2x8); IDC-Header_2x08_P2.54mm_Vertical
J2: Entradas 12-15; PinHeader_1x05_P2.54mm_Vertical
J6: Analógico (joystick, acelerador); PinHeader_1x05_P2.54mm_Vertical
K1: Korry 1; JST_XH_B4B-XH-A_1x04_P2.50mm_Vertical
K2: Korry 2; JST_XH_B4B-XH-A_1x04_P2.50mm_Vertical
K3: Korry 3; JST_XH_B4B-XH-A_1x04_P2.50mm_Vertical
K4: Korry 4; JST_XH_B4B-XH-A_1x04_P2.50mm_Vertical
K5: Korry 5; JST_XH_B4B-XH-A_1x04_P2.50mm_Vertical
K6: Korry 6; JST_XH_B4B-XH-A_1x04_P2.50mm_Vertical
K7: Korry 7; JST_XH_B4B-XH-A_1x04_P2.50mm_Vertical
K8: Korry 8; JST_XH_B4B-XH-A_1x04_P2.50mm_Vertical
K9: Korry 9; JST_XH_B4B-XH-A_1x04_P2.50mm_Vertical
K10: Korry 10; JST_XH_B4B-XH-A_1x04_P2.50mm_Vertical
K11: Korry 11; JST_XH_B4B-XH-A_1x04_P2.50mm_Vertical
K12: Korry 12; JST_XH_B4B-XH-A_1x04_P2.50mm_Vertical
R1, R2, R3, R4, R5, R6, R7, R8, R9, R10, R11, R12, R13, R14, R15, R16, R17, R18, R19, R20, R21, R22, R23, R24: 220; R_Axial_DIN0207_L6.3mm_D2.5mm_P7.62mm_Horizontal
RN1, RN2, RN3: 10k; R_Array_SIP9
SW1: Etiqueta (DIP 8 vias); SW_DIP_SPSTx08_Slide_9.78x22.5mm_W7.62mm_P2.54mm
U1, U2, U3: 74HC165; DIP-16_W7.62mm_Socket
U4, U5, U6: 74HC595; DIP-16_W7.62mm_Socket

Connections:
+5V: C1.1, C2.1, C3.1, C4.1, C5.1, C6.1, C7.1, J1.1, J1.15, J6.1, RN1.1 (common), RN2.1 (common), RN3.1 (common), U1.16 (VCC), U2.16 (VCC), U3.16 (VCC), U4.10 (~SRCLR), U4.16 (VCC), U5.10 (~SRCLR), U5.16 (VCC), U6.10 (~SRCLR), U6.16 (VCC)
/AN_A: J1.11, J6.2
/AN_B: J1.13, J6.3
/AN_C: J1.14, J6.4
/CH165_1: U1.10 (DS), U2.9 (Q7)
/CH165_2: U2.10 (DS), U3.9 (Q7)
/CH595_1: U4.9 (QH'), U5.14 (SER)
/CH595_2: U5.9 (QH'), U6.14 (SER)
/ID0: RN1.2 (R1), SW1.1, U1.11 (D0)
/ID1: RN1.3 (R2), SW1.2, U1.12 (D1)
/ID2: RN1.4 (R3), SW1.3, U1.13 (D2)
/ID3: RN1.5 (R4), SW1.4, U1.14 (D3)
/ID4: RN1.6 (R5), SW1.5, U1.3 (D4)
/ID5: RN1.7 (R6), SW1.6, U1.4 (D5)
/ID6: RN1.8 (R7), SW1.7, U1.5 (D6)
/ID7: RN1.9 (R8), SW1.8, U1.6 (D7)
/IN0: K1.2, RN2.2 (R1), U2.11 (D0)
/IN1: K2.2, RN2.3 (R2), U2.12 (D1)
/IN2: K3.2, RN2.4 (R3), U2.13 (D2)
/IN3: K4.2, RN2.5 (R4), U2.14 (D3)
/IN4: K5.2, RN2.6 (R5), U2.3 (D4)
/IN5: K6.2, RN2.7 (R6), U2.4 (D5)
/IN6: K7.2, RN2.8 (R7), U2.5 (D6)
/IN7: K8.2, RN2.9 (R8), U2.6 (D7)
/IN8: K9.2, RN3.2 (R1), U3.11 (D0)
/IN9: K10.2, RN3.3 (R2), U3.12 (D1)
/IN10: K11.2, RN3.4 (R3), U3.13 (D2)
/IN11: K12.2, RN3.5 (R4), U3.14 (D3)
/IN12: J2.1, RN3.6 (R5), U3.3 (D4)
/IN13: J2.2, RN3.7 (R6), U3.4 (D5)
/IN14: J2.3, RN3.8 (R7), U3.5 (D6)
/IN15: J2.4, RN3.9 (R8), U3.6 (D7)
/LED0: K1.3, R1.2
/LED1: K1.4, R2.2
/LED2: K2.3, R3.2
/LED3: K2.4, R4.2
/LED4: K3.3, R5.2
/LED5: K3.4, R6.2
/LED6: K4.3, R7.2
/LED7: K4.4, R8.2
/LED8: K5.3, R9.2
/LED9: K5.4, R10.2
/LED10: K6.3, R11.2
/LED11: K6.4, R12.2
/LED12: K7.3, R13.2
/LED13: K7.4, R14.2
/LED14: K8.3, R15.2
/LED15: K8.4, R16.2
/LED16: K9.3, R17.2
/LED17: K9.4, R18.2
/LED18: K10.3, R19.2
/LED19: K10.4, R20.2
/LED20: K11.3, R21.2
/LED21: K11.4, R22.2
/LED22: K12.3, R23.2
/LED23: K12.4, R24.2
/OUT0: R1.1, U4.15 (QA)
/OUT1: R2.1, U4.1 (QB)
/OUT2: R3.1, U4.2 (QC)
/OUT3: R4.1, U4.3 (QD)
/OUT4: R5.1, U4.4 (QE)
/OUT5: R6.1, U4.5 (QF)
/OUT6: R7.1, U4.6 (QG)
/OUT7: R8.1, U4.7 (QH)
/OUT8: R9.1, U5.15 (QA)
/OUT9: R10.1, U5.1 (QB)
/OUT10: R11.1, U5.2 (QC)
/OUT11: R12.1, U5.3 (QD)
/OUT12: R13.1, U5.4 (QE)
/OUT13: R14.1, U5.5 (QF)
/OUT14: R15.1, U5.6 (QG)
/OUT15: R16.1, U5.7 (QH)
/OUT16: R17.1, U6.15 (QA)
/OUT17: R18.1, U6.1 (QB)
/OUT18: R19.1, U6.2 (QC)
/OUT19: R20.1, U6.3 (QD)
/OUT20: R21.1, U6.4 (QE)
/OUT21: R22.1, U6.5 (QF)
/OUT22: R23.1, U6.6 (QG)
/OUT23: R24.1, U6.7 (QH)
/PL: J1.5, U1.1 (~PL), U2.1 (~PL), U3.1 (~PL)
/RCLK: J1.6, U4.12 (RCLK), U5.12 (RCLK), U6.12 (RCLK)
/SCK: J1.3, U1.2 (CP), U2.2 (CP), U3.2 (CP), U4.11 (SRCLK), U5.11 (SRCLK), U6.11 (SRCLK)
/SIN165: J1.7, U3.10 (DS)
/SIN595: J1.9, U4.14 (SER)
/SOUT165: J1.8, U1.9 (Q7)
/SOUT595: J1.10, U6.9 (QH')
GND: C1.2, C2.2, C3.2, C4.2, C5.2, C6.2, C7.2, J1.2, J1.4, J1.12, J1.16, J2.5, J6.5, K1.1, K2.1, K3.1, K4.1, K5.1, K6.1, K7.1, K8.1, K9.1, K10.1, K11.1, K12.1, SW1.9, SW1.10, SW1.11, SW1.12, SW1.13, SW1.14, SW1.15, SW1.16, U1.8 (GND), U1.15 (~CE), U2.8 (GND), U2.15 (~CE), U3.8 (GND), U3.15 (~CE), U4.8 (GND), U4.13 (~OE), U5.8 (GND), U5.13 (~OE), U6.8 (GND), U6.13 (~OE)

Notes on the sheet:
Módulo médio do painel
Etiqueta + 16 entradas + 24 saídas para LED. Monte sempre todos os CIs: a posição de cada byte na cadeia depende disso. Entrada ou saída sem uso fica livre.
Etiqueta
Entradas (74HC165)
Saídas para LED (74HC595)
Um 100nF colado em cada CI
Cabo flat (J1) 1 +5V 2 GND 3 SCK 4 GND 5 PL 6 RCLK 7 SIN165 8 SOUT165 9 SIN595 10 SOUT595 11 AN_A 12 GND 13 AN_B 14 AN_C 15 +5V 16 GND
Etiqueta: chave k ligada (ON) = bit k-1 igual a 1. Bits 7-6 = tamanho (médio: 10); bits 5-0 = número da seção (1 a 62). Entradas: SIN165 > U3 > U2 > U1 > SOUT165 (para o Mega). O Mega lê nesta ordem: U1 (etiqueta), U2 (IN0-7), U3 (IN8-15). Botão ou chave: entre INn e GND. Apertado/ligado = 0 (pull-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
Korry (K1 a K12, JST-XH de 4 vias) Kk: 1 GND, 2 IN(k-1), 3 LED(2k-2) em cima, 4 LED(2k-1) embaixo. J2: IN12 a IN15, para botões comuns.

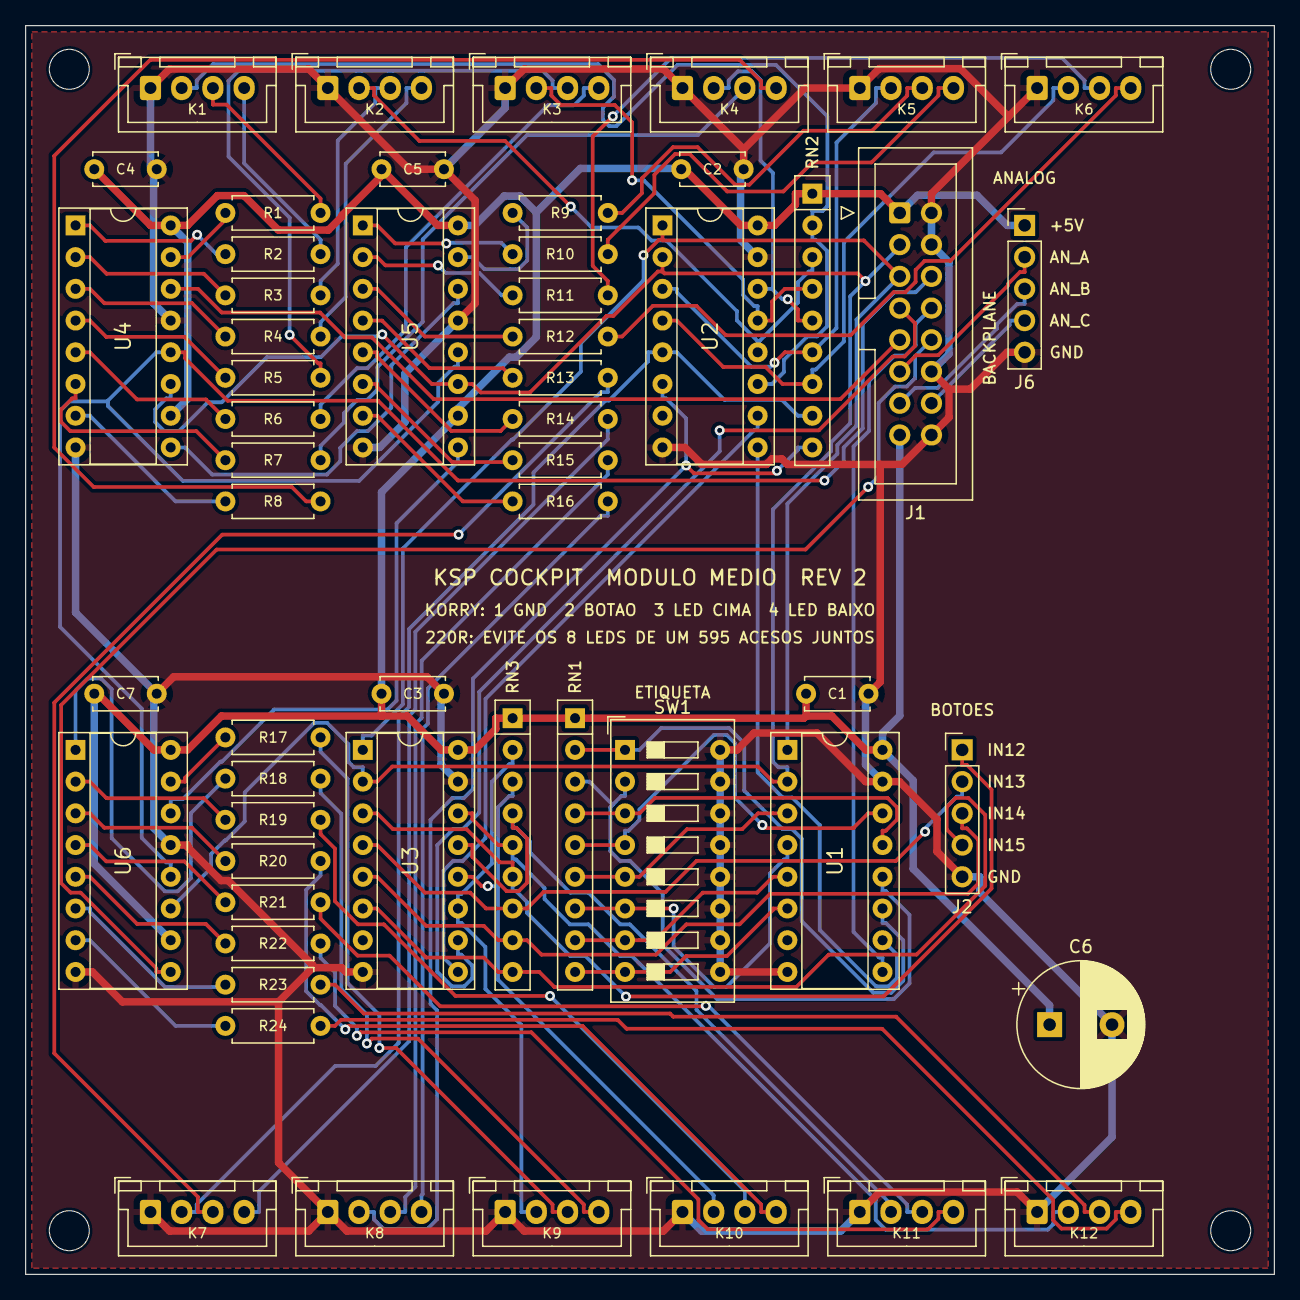
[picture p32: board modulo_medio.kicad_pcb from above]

Board: 2 copper layers, 100.0 x 100.0 mm, 60 parts (0 on the bottom side), 88 nets.

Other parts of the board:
H1, H2, H3, H4: MountingHole_3.2mm_M3

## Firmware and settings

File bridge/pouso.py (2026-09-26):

"""Pouso autônomo: queima de suicídio numa descida vertical, em qualquer planeta.

A nave cai com o motor desligado, acende o mais tarde possível e freia até
tocar o chão devagar. Nos planetas com atmosfera, o arrasto do ar também freia;
o script mede esse arrasto em voo e acende mais tarde por causa dele. Sem
atmosfera (Mun, Minmus...), o arrasto é zero e sobram só gravidade e motor.

A cada volta do laço (20 vezes por segundo):
 1. Lê do jogo a altura do pé da nave, a velocidade, a massa, o empuxo e o
    arrasto.
 2. Estima a "área de arrasto" da nave: arrasto medido / (densidade · v²).
 3. Procura, por bisseção, a aceleração fixa do motor que leva a descida a
    V_TOQUE a ALTURA_FOLGA do chão. Para testar cada valor, simula a freada
    daqui até o fim, com gravidade, motor e arrasto (que muda com a velocidade
    e com a densidade do ar, maior perto do chão).
 4. Enquanto essa aceleração for menor que IGNICAO do máximo, cai sem motor.
    Quando chega nela, acende e passa a usar a aceleração calculada, refeita a
    cada volta: os erros da previsão se corrigem sozinhos no caminho.
 5. Perto do chão, segura a descida em V_TOQUE até a nave pousar.

Quem aponta a nave é o SAS do próprio KSP: retrógrado enquanto a nave desce
rápido, e segurando a atitude no fim, quando a velocidade fica pequena e o
retrógrado começa a pular de um lado para o outro.

Uso:
    python pouso.py                  # KSP neste computador
    python pouso.py 192.168.1.10     # KSP em outro computador (ex.: a partir do Pi)

Rode com o motor já ativado (no estágio) e a nave caindo ou subindo num salto.
O script desce na vertical, onde estiver: não escolhe o lugar do pouso.
A nave precisa de SAS com o modo retrógrado (piloto ou sonda de nível 1).
Ctrl+C corta o motor e devolve o controle ao piloto.
"""

import argparse
import math
import sys
import time
from dataclasses import dataclass

IGNICAO = 0.85          # acende quando a freada precisa de 85% do empuxo: sobram 15% para corrigir
FATOR_ARRASTO = 0.7     # a previsão só conta com 70% do arrasto medido (ver Guiagem._medir_arrasto)
V_TOQUE = 2.0           # m/s: velocidade de descida no toque
ALTURA_FOLGA = 2.0      # m: a freada mira terminar aqui; o resto desce em V_TOQUE
ALTURA_TOQUE = 10.0     # m: abaixo disso, com a descida já lenta, não desliga mais o motor
GANHO_TOQUE = 2.0       # 1/s: quanto o motor corrige a velocidade na descida final
V_RETROGRADO = 10.0     # m/s: descendo mais devagar que isso, o SAS para de seguir o retrógrado
CIMA_MIN = 0.5          # nariz a mais de 60° da vertical: motor desligado até a nave virar
Q_MIN = 20.0            # Pa: com menos pressão dinâmica que isso, o arrasto medido é só ruído
SUAVIZACAO = 0.2        # peso de cada medida nova na média da área de arrasto
PASSOS_PREVISAO = 50    # passos da simulação da freada
ITERACOES = 14          # passos da bisseção: precisão de 1/16000 do empuxo
AMOSTRAS_ATMOSFERA = 100  # pontos da tabela de densidade do ar
INTERVALO = 0.05        # s: 20 voltas por segundo
INTERVALO_LENTO = 1.0   # s: altura do pé e empuxo no chão, que mudam devagar
INTERVALO_STATUS = 1.0  # s: uma linha de situação no terminal
INTERVALO_STATUS_PERTO = 0.25  # s: idem, nos últimos ALTURA_PERTO metros
ALTURA_PERTO = 100.0    # m
PASCAL_POR_ATM = 101_325

QUEDA = "QUEDA"         # motor desligado, esperando a hora de acender
QUEIMA = "QUEIMA"       # freando
TOQUE = "TOQUE"         # descida final, em V_TOQUE
POUSADA = "POUSADA"

RETROGRADO = "retrógrado"          # modos do SAS pedidos pela guiagem
ATITUDE = "segurar a atitude"


@dataclass
class Leitura:
    altura: float        # m: do ponto mais baixo da nave até o chão (ou o mar, se estiver mais perto)
    altitude: float      # m: do centro de massa até o nível do mar
    velocidade: tuple    # m/s: (cima, norte, leste), em relação ao chão
    massa: float         # kg
    empuxo: float        # N: empuxo dos motores ativos com o acelerador em 100%, agora
    empuxo_chao: float   # N: o mesmo com a pressão do ar no chão (ar mais grosso tira empuxo)
    arrasto: float       # N
    cima: float          # quanto o nariz aponta para cima: 1 = na vertical, 0 = deitado
    g: float             # m/s²: gravidade no chão
    pousada: bool


class Guiagem:
    """Decide o acelerador e a direção a cada leitura.

    Não conhece o kRPC: recebe uma Leitura e devolve o acelerador e o modo
    do SAS. Assim os testes (test_pouso.py) usam esta mesma guiagem com uma
    nave simulada.
    """

    def __init__(self, densidade):
        self._densidade = densidade  # função: altitude sobre o mar (m) → densidade do ar (kg/m³)
        self.fase = QUEDA
        self.area = 0.0              # m²: arrasto / (densidade · v²), medida em voo
        self.necessaria = 0.0        # m/s²: aceleração do motor que a freada precisa agora
        self._freou = False          # a freada já trouxe a descida abaixo de V_RETROGRADO

    def passo(self, l):
        """Devolve (acelerador de 0 a 1, modo do SAS: RETROGRADO ou ATITUDE)."""
        self._medir_arrasto(l)
        vc = l.velocidade[0]
        self.necessaria = self._aceleracao_necessaria(l)
        maxima_chao = l.empuxo_chao / l.massa

        if l.pousada:
            self.fase = POUSADA
        elif self.fase == TOQUE:
            pass  # perto do chão não volta atrás
        elif vc >= -V_TOQUE:
            # Já lenta (ou subindo): perto do chão, desce devagar; longe dele,
            # cai sem motor de novo e acende outra vez quando precisar.
            self.fase = TOQUE if l.altura <= ALTURA_TOQUE else QUEDA
        elif self.fase == QUEIMA or 0 < IGNICAO * maxima_chao <= self.necessaria:
            self.fase = QUEIMA  # sem motor ativo (maxima_chao = 0) não adianta acender
        else:
            self.fase = QUEDA

        if self.fase == QUEIMA:
            aceleracao = self.necessaria
        elif self.fase == TOQUE:
            # Segura a gravidade e corrige a diferença para -V_TOQUE. A essa
            # velocidade o arrasto não conta.
            aceleracao = l.g + GANHO_TOQUE * (-V_TOQUE - vc)
        else:
            aceleracao = 0.0
        return self._acelerador(aceleracao, l), self._modo(l)

    def _modo(self, l):
        """Para onde o SAS aponta a nave.

        Descendo rápido, retrógrado: o motor freia contra o movimento e a
        deriva para os lados some junto. Devagar, o retrógrado fica instável:
        a 2 m/s de descida, meio metro por segundo de deriva já inclina a mira
        14°, e o SAS, correndo atrás dela com o motor ligado, cria mais deriva
        e começa a balançar a nave. Aí o SAS só segura a atitude que a nave
        tem, quase em pé depois da freada retrógrada.

        Antes da freada (ex.: no alto de um salto, quase parada) também segura
        a atitude. Depois que a freada deixa a nave devagar, não volta mais ao
        retrógrado.
        """
        descendo_rapido = -l.velocidade[0] >= V_RETROGRADO
        if self.fase in (QUEIMA, TOQUE) and not descendo_rapido:
            self._freou = True
        return RETROGRADO if descendo_rapido and not self._freou else ATITUDE

    def _acelerador(self, aceleracao, l):
        """Converte a aceleração vertical desejada em posição do acelerador.

        Com o nariz inclinado, só parte do empuxo vai para cima: divide por
        l.cima para compensar.
        """
        if aceleracao <= 0 or l.empuxo <= 0 or l.cima < CIMA_MIN:
            return 0.0
        return min(1.0, aceleracao * l.massa / (l.empuxo * l.cima))

    def _medir_arrasto(self, l):
        """Atualiza a área de arrasto a partir do arrasto que o jogo mediu.

        No KSP, arrasto = área · densidade · v² (a área já inclui o
        coeficiente de arrasto e o 1/2). Guardar a área em vez do arrasto
        permite prever o arrasto em outra altitude e outra velocidade.

        A área de verdade muda com a velocidade do som: perto de Mach 1 ela
        passa do dobro da área em baixa velocidade. Medida ainda rápida, ela
        faria a previsão contar com mais arrasto do que vai haver no fim da
        freada, e a ignição sairia tarde demais. Por isso a previsão só usa
        FATOR_ARRASTO dela.
        """
        v2 = sum(c * c for c in l.velocidade)
        densidade = self._densidade(l.altitude)
        if densidade * v2 / 2 < Q_MIN:
            return  # ar ralo demais para medir: fica a última estimativa
        medida = l.arrasto / (densidade * v2)
        if self.area == 0.0:
            self.area = medida
        else:
            self.area += SUAVIZACAO * (medida - self.area)

    def _aceleracao_necessaria(self, l):
        """Aceleração do motor que, fixa daqui até o fim, termina a freada na hora certa.

        "Na hora certa" = a descida chega a V_TOQUE a ALTURA_FOLGA do chão.
        Devolve 0 se o ar sozinho dá conta, e infinito se nem o motor todo dá.
        Bisseção: se a nave para acima do alvo, dá para frear menos; se bate no
        chão antes, precisa frear mais.
        """
        if l.velocidade[0] >= -V_TOQUE:
            return 0.0
        maxima = max(l.empuxo, l.empuxo_chao) / l.massa

        def sobra(aceleracao):
            return self._prever(l, aceleracao) - ALTURA_FOLGA

        if sobra(0.0) >= 0:
            return 0.0
        if sobra(maxima) < 0:
            return math.inf
        baixo, alto = 0.0, maxima
        for _ in range(ITERACOES):
            meio = (baixo + alto) / 2
            if sobra(meio) >= 0:
                alto = meio
            else:
                baixo = meio
        return alto  # o lado que ainda para a tempo

    def _prever(self, l, aceleracao):
        """Simula a freada com o motor fixo em `aceleracao` (m/s², para cima).

        Devolve a altura em que a descida chega a V_TOQUE; negativa se a nave
        bater no chão antes. Anda em passos iguais de velocidade, não de tempo:
        são sempre PASSOS_PREVISAO passos, esteja a nave a 50 m ou a 50 km.

        Fica do lado seguro: usa a gravidade do chão (a mais forte do caminho),
        a massa de agora (o combustível gasto deixaria a nave mais leve) e
        FATOR_ARRASTO do arrasto.
        """
        altura = l.altura
        v = l.velocidade[0]
        base = l.altitude - l.altura  # altitude do centro de massa com o pé no chão
        dv = (-V_TOQUE - v) / PASSOS_PREVISAO  # positivo: a descida vai diminuindo
        for _ in range(PASSOS_PREVISAO):
            v_meio = v + dv / 2
            arrasto = FATOR_ARRASTO * self.area * self._densidade(base + altura) * v_meio**2 / l.massa
            freada = aceleracao + arrasto - l.g
            if freada <= 0:
                return -1.0  # nessa condição a nave nem desacelera
            dt = dv / freada
            altura += v_meio * dt
            if altura < 0:
                return altura
            v += dv
        return altura


def ler_atmosfera(corpo):
    """Tabela da densidade do ar por altitude, lida do jogo uma vez só.

    Consultar o jogo a cada passo da previsão seria lento demais (são
    milhares de consultas por segundo); a tabela é interpolada aqui mesmo.
    """
    if not corpo.has_atmosphere:
        return lambda altitude: 0.0
    topo = corpo.atmosphere_depth
    passo = topo / AMOSTRAS_ATMOSFERA
    tabela = [corpo.density_at(i * passo) for i in range(AMOSTRAS_ATMOSFERA + 1)]

    def densidade(altitude):
        if altitude >= topo:
            return 0.0
        x = max(altitude, 0.0) / passo
        i = min(int(x), AMOSTRAS_ATMOSFERA - 1)
        return tabela[i] + (tabela[i + 1] - tabela[i]) * (x - i)

    return densidade


class NaveKrpc:
    """Lê a nave pelo kRPC, com streams, e monta a Leitura para a guiagem."""

    def __init__(self, conn, nave):
        space_center = conn.space_center
        self._nave = nave
        self.corpo = corpo = nave.orbit.body
        self._gm = corpo.gravitational_parameter
        self._raio = corpo.equatorial_radius
        self._atmosfera = corpo.has_atmosphere
        situacao = space_center.VesselSituation
        self._pousada = (situacao.landed, situacao.splashed)

        # Referencial "híbrido": velocidade em relação ao chão, que gira com o
        # planeta, escrita nos eixos do horizonte local (x = cima, y = norte,
        # z = leste). A direção do nariz vem nos mesmos eixos.
        self.referencial = space_center.ReferenceFrame.create_hybrid(
            position=corpo.reference_frame, rotation=nave.surface_reference_frame
        )
        voo = nave.flight(self.referencial)
        stream = conn.add_stream
        self._streams = {
            "radar": stream(getattr, voo, "surface_altitude"),
            "altitude": stream(getattr, voo, "mean_altitude"),
            "velocidade": stream(getattr, voo, "velocity"),
            "arrasto": stream(getattr, voo, "drag"),
            "massa": stream(getattr, nave, "mass"),
            "empuxo": stream(getattr, nave, "available_thrust"),
            "direcao": stream(nave.direction, self.referencial),
            "situacao": stream(getattr, nave, "situation"),
            "trem": stream(getattr, nave.control, "gear"),
        }
        self.pernas = [perna.part for perna in nave.parts.legs]
        self._proxima_lenta = 0.0
        self._trem_medido = None  # posição do trem na última medida do pé
        self._fundo = 0.0       # m: do centro de massa até o pé da nave (negativo)
        self._fator_chao = 1.0  # empuxo com a pressão do chão / empuxo agora

    def _atualizar_lento(self, terreno, trem):
        """O que muda devagar, relido uma vez por segundo e quando o trem muda.

        A altitude do jogo é medida do centro de massa, não do pé. O pé vem
        da caixa que envolve as peças, nos eixos do horizonte (x = cima).

        Com o trem baixado, o pé é a ponta da perna mais baixa, e só as pernas
        entram na conta. Nas versões lançadas do kRPC (até a 0.6.0), a caixa
        de uma peça junta tudo o que está pendurado nela, como o efeito da
        chama do motor ligado. Aí a caixa da nave inteira desce metros abaixo
        do pé de verdade, e a freada termina alta demais. Com o trem
        recolhido (ou sem trem), fica a caixa da nave inteira: se ela errar,
        erra para baixo, e a ignição só sai um pouco mais cedo.

        O empuxo cai quando o ar engrossa (depende do motor: os de vácuo
        perdem muito). A previsão usa o empuxo com a pressão do chão, o menor
        do caminho.
        """
        referencial = self._nave.surface_reference_frame
        if trem and self.pernas:
            self._fundo = min(peca.bounding_box(referencial)[0][0] for peca in self.pernas)
        else:
            self._fundo = self._nave.bounding_box(referencial)[0][0]
        self._trem_medido = trem
        agora = self._nave.available_thrust
        if agora > 0:
            pressao = self.corpo.pressure_at(max(terreno, 0.0)) if self._atmosfera else 0.0
            self._fator_chao = self._nave.available_thrust_at(pressao / PASCAL_POR_ATM) / agora

    def ler(self):
        s = {nome: stream() for nome, stream in self._streams.items()}
        terreno = s["altitude"] - s["radar"]  # altitude do chão (ou do mar) abaixo da nave
        agora = time.monotonic()
        if agora >= self._proxima_lenta or s["trem"] != self._trem_medido:
            self._atualizar_lento(terreno, s["trem"])
            self._proxima_lenta = agora + INTERVALO_LENTO
        return Leitura(
            altura=s["radar"] + self._fundo,
            altitude=s["altitude"],
            velocidade=s["velocidade"],
            massa=s["massa"],
            empuxo=s["empuxo"],
            empuxo_chao=s["empuxo"] * self._fator_chao,
            arrasto=math.hypot(*s["arrasto"]),
            cima=s["direcao"][0],
            g=self._gm / (self._raio + terreno) ** 2,
            pousada=s["situacao"] in self._pousada,
        )

    def remover(self):
        for stream in self._streams.values():
            stream.remove()


class Avisos:
    """Imprime cada aviso uma vez só, e de novo depois que ele deixar de valer."""

    def __init__(self):
        self._ativos = set()

    def conferir(self, chave, vale, texto):
        if vale and chave not in self._ativos:
            print(f"AVISO: {texto}")
            self._ativos.add(chave)
        elif not vale:
            self._ativos.discard(chave)


class Sas:
    """O SAS do KSP, que aponta a nave. Só troca o modo quando a guiagem pede outro."""

    def __init__(self, conn, controle):
        space_center = conn.space_center
        self._controle = controle
        self._modos = {
            RETROGRADO: space_center.SASMode.retrograde,
            ATITUDE: space_center.SASMode.stability_assist,
        }
        self._faltando = set()  # modos que o SAS desta nave não tem
        self.modo = None
        controle.sas = True
        controle.speed_mode = space_center.SpeedMode.surface  # retrógrado em relação ao chão

    def pedir(self, modo):
        """Troca o modo do SAS. Se a nave não tiver o modo, fica segurando a atitude."""
        if modo in self._faltando:
            modo = ATITUDE
        if modo == self.modo:
            return
        try:
            self._controle.sas_mode = self._modos[modo]
        except RuntimeError:
            # O kRPC recusa um modo que a nave não tem. Segurar a atitude
            # existe em todo SAS.
            self._faltando.add(modo)
            print(f"AVISO: o SAS desta nave não tem o modo {modo} (precisa de piloto "
                  "ou sonda de nível 1); a nave fica segurando a atitude.")
            self._controle.sas_mode = self._modos[ATITUDE]
            modo = ATITUDE
        self.modo = modo
        print(f"SAS: {modo}")


def inclinacao(l):
    """Graus entre o nariz e a vertical."""
    return math.degrees(math.acos(min(max(l.cima, -1.0), 1.0)))


def status(l, guiagem, acelerador):
    maxima = l.empuxo_chao / l.massa
    if maxima <= 0 or math.isinf(guiagem.necessaria):
        precisa = "  ---"
    else:
        precisa = f"{guiagem.necessaria / maxima * 100:4.0f}%"
    if guiagem.fase == QUEDA:
        precisa += f" (acende em {IGNICAO:.0%})"
    arrasto = f"  area de arrasto {guiagem.area:5.2f} m2" if guiagem.area else ""
    return (
        f"{guiagem.fase:7} altura {l.altura:8.1f} m  descida {-l.velocidade[0]:6.1f} m/s  "
        f"inclinacao {inclinacao(l):2.0f} graus  motor {acelerador * 100:3.0f}%  "
        f"freada precisa {precisa}{arrasto}"
    )


def pousar(conn, nave):
    corpo = nave.orbit.body
    # has_solid_surface só existe nas versões novas do kRPC.
    if not getattr(corpo, "has_solid_surface", True):
        print(f"{corpo.name} não tem chão para pousar.")
        return
    if corpo.has_atmosphere:
        print(f"Lendo a atmosfera de {corpo.name}...")
    guiagem = Guiagem(ler_atmosfera(corpo))
    fonte = NaveKrpc(conn, nave)
    controle = nave.control
    try:
        l = fonte.ler()
        if l.pousada:
            print("A nave já está pousada.")
            return

        twr = l.empuxo_chao / (l.massa * l.g)
        print(f"Nave: {nave.name} ({corpo.name})  empuxo/peso no chão: {twr:.2f}")
        horizontal = math.hypot(l.velocidade[1], l.velocidade[2])
        if horizontal > 50:
            print(f"AVISO: {horizontal:.0f} m/s de velocidade horizontal; o script supõe descida vertical.")
        if 0 < twr < 1:
            print("AVISO: o motor não segura o peso da nave no chão; não vai dar para pousar.")
        if not fonte.pernas:
            print("AVISO: a nave não tem trem de pouso; o pé vem da caixa da nave inteira, "
                  "que no kRPC pode ficar metros abaixo do real (a freada termina alta).")

        controle.throttle = 0.0
        sas = Sas(conn, controle)

        avisos = Avisos()
        fase = None
        proximo_status = 0.0
        descida = 0.0
        while True:
            l = fonte.ler()
            acelerador, modo = guiagem.passo(l)
            if guiagem.fase == POUSADA:
                # A altura estimada no toque mostra o erro da medida do pé: o
                # certo é perto de zero.
                print(f"Pousou! Descia a {descida:.1f} m/s, com o nariz a "
                      f"{inclinacao(l):.0f}° da vertical. No toque, o script achava "
                      f"que o pé estava a {l.altura:.1f} m do chão.")
                break
            controle.throttle = acelerador
            sas.pedir(modo)
            descida = -l.velocidade[0]

            if guiagem.fase != fase:
                fase = guiagem.fase
                print(f"--> {fase} a {l.altura:.0f} m do chão")
                if fase in (QUEIMA, TOQUE):
                    controle.gear = True
            ligado = fase in (QUEIMA, TOQUE)
            avisos.conferir("motor", l.empuxo <= 0, "nenhum motor ativo: ative o estágio do motor.")
            avisos.conferir(
                "empuxo", fase == QUEIMA and math.isinf(guiagem.necessaria),
                "empuxo insuficiente, não dá mais para parar a tempo!",
            )
            avisos.conferir(
                "nariz", ligado and l.cima < CIMA_MIN,
                "nariz longe da vertical: motor desligado até a nave virar.",
            )

            agora = time.monotonic()
            if agora >= proximo_status:
                print(status(l, guiagem, acelerador))
                perto = l.altura < ALTURA_PERTO
                proximo_status = agora + (INTERVALO_STATUS_PERTO if perto else INTERVALO_STATUS)
            time.sleep(INTERVALO)
    finally:
        try:
            controle.throttle = 0.0
            controle.sas = True
            controle.sas_mode = conn.space_center.SASMode.stability_assist
            fonte.remover()
        except (ValueError, RuntimeError):
            pass  # a nave pode não existir mais
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

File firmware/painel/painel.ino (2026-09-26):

// Firmware do painel: Arduino Mega 2560, protocolo v0 (texto)
//
// Fase 2: botões STAGE e ABORT, chaves de SAS, RCS, trem de pouso, luzes e
// freios, um LED de estado para cada chave, e o LCD 20x4 da fase 1.
//
// Montagem (tudo direto nos pinos do Mega; a pinagem completa, com desenho,
// está em docs/fase2.md):
//   Botões e chaves:  pino ──[contato]── GND      sem resistor: usa o pull-up interno
//     STAGE 2    ABORT 3    SAS 22    RCS 24    GEAR 26    LIGHTS 28    BRAKES 30
//   LEDs:             pino ──[220 Ω]──(+)LED(−)── GND
//     SAS 8      RCS 9      GEAR 10   LIGHTS 11   BRAKES 12
//   LCD I2C:          SDA → pino 20   SCL → pino 21   VCC → 5V   GND → GND
//
// Biblioteca necessária (Arduino IDE → Library Manager):
//   "LiquidCrystal I2C", de Frank de Brabander
//
// Protocolo v0: texto, 115200 baud, uma mensagem por linha terminada em '\n'.
// A especificação completa está em docs/protocolo.md.
//   Painel → ponte:  READY | BTN <nome> <0|1> | SW <nome> <0|1> | ERR <linha>
//   Ponte → painel:  <nome do LED> <0|1> (ex.: SAS 1, GEAR 0) | ALT <metros>
//
// Teste sem o KSP, pelo Serial Monitor (115200 baud, final de linha em
// "Nova linha"): mexa nas chaves e botões e veja as mensagens; digite
// "RCS 1", "ALT 12345"... e veja os LEDs e o LCD. Sem mensagens por 1 segundo,
// o LCD mostra "sem sinal" e os LEDs apagam.
//
// Lembre do princípio do projeto: o painel NÃO SABE QUE O KSP EXISTE. Ele
// avisa que uma chave mudou, acende LEDs e mostra um número. Os nomes (SAS,
// GEAR...) são só etiquetas; quem dá sentido a eles é a ponte (bridge/ponte.py).
//
// O que mudou em relação à fase 1: os controles saíram de variáveis soltas e
// viraram TABELAS (ENTRADAS e LEDS, logo abaixo). O código percorre as tabelas
// e não conhece nenhum controle pelo nome. Para acrescentar uma chave ou um
// LED, basta uma linha na tabela (e o tratamento correspondente na ponte).

#include <Wire.h>
#include <LiquidCrystal_I2C.h>

// ================================================================ config =====

// Endereço I2C do LCD: rode o passo4_i2c_scanner para descobrir o seu.
// Os mais comuns são 0x27 e 0x3F.
const uint8_t LCD_ENDERECO = 0x27;
const uint8_t LCD_COLUNAS = 20;
const uint8_t LCD_LINHAS = 4;

const unsigned long DEBOUNCE_MS = 20;

// A ponte manda a altitude 10 vezes por segundo. Se passar 1 segundo sem
// nenhuma mensagem, a ponte caiu, o jogo fechou ou o cabo soltou.
const unsigned long TIMEOUT_SINAL_MS = 1000;

// Redesenhar o LCD no máximo 5 vezes por segundo (a explicação está em
// atualizarLcd()).
const unsigned long INTERVALO_LCD_MS = 200;

// Estado "não sei" de um LED: antes da primeira mensagem ou sem sinal.
const int8_t DESCONHECIDO = -1;

// ======================================================== tabela: entradas ===
//
// Botões e chaves são lidos do mesmo jeito: contato entre o pino e o GND, com
// o pull-up interno. Contato fechado (pino em LOW) vira 1 na mensagem.
//   - Botão (BTN): 1 = apertado, 0 = solto.
//   - Chave (SW): 1 = ligada, 0 = desligada. Monte a chave de modo que "para
//     cima" feche o contato.
// A única diferença entre os dois é a palavra na mensagem: é a ponte que decide
// que um botão dispara uma ação e uma chave define um estado.

struct Entrada {
  const char *tipo;   // "BTN" ou "SW"
  const char *nome;
  uint8_t pino;
};

// Os pinos 0 e 1 (serial da USB), 20 e 21 (I2C do LCD) e 50 a 53 (SPI, para
// os shift registers do futuro) ficam de fora. As chaves usam só pinos pares
// da barra dupla (22, 24...) para ficarem todas na mesma fileira.
const Entrada ENTRADAS[] = {
  {"BTN", "STAGE", 2},
  {"BTN", "ABORT", 3},
  {"SW", "SAS", 22},
  {"SW", "RCS", 24},
  {"SW", "GEAR", 26},
  {"SW", "LIGHTS", 28},
  {"SW", "BRAKES", 30},
};

// sizeof(tabela) / sizeof(um item) = número de itens. Calculado pelo
// compilador: acrescentar uma linha na tabela não exige mudar mais nada.
const uint8_t NUM_ENTRADAS = sizeof(ENTRADAS) / sizeof(ENTRADAS[0]);

// ============================================================ tabela: LEDs ===
//
// Cada LED mostra o estado de um sistema NO JOGO, não a posição da chave: se o
// jogo desligar o SAS sozinho, o LED apaga, mesmo com a chave para cima.

struct Led {
  const char *nome;   // o mesmo nome da mensagem que vem da ponte ("SAS 1")
  uint8_t pino;
};

const Led LEDS[] = {
  {"SAS", 8},
  {"RCS", 9},
  {"GEAR", 10},
  {"LIGHTS", 11},
  {"BRAKES", 12},
};

const uint8_t NUM_LEDS = sizeof(LEDS) / sizeof(LEDS[0]);

const int8_t NAO_ENCONTRADO = -1;

// ================================================================ estado =====
//
// As tabelas acima são constantes: dizem o que existe e onde está ligado. O
// que muda durante o funcionamento fica aqui, em vetores do mesmo tamanho: o
// item i de cada vetor pertence ao item i da tabela.

// Debounce de cada entrada (igual ao passo 2), preenchido no setup().
bool entradaEstavel[NUM_ENTRADAS];
bool entradaUltimaLeitura[NUM_ENTRADAS];
unsigned long entradaInstanteMudanca[NUM_ENTRADAS];

// Estado de cada LED: -1 = desconhecido, 0 = apagado, 1 = aceso.
int8_t estadoLed[NUM_LEDS];

// O LCD mostra o SAS na linha 2: posição dele na tabela LEDS (setup()).
int8_t indiceSas = NAO_ENCONTRADO;

long altitude = 0;               // em metros; long = inteiro de 32 bits com sinal
bool altitudeConhecida = false;

// Sinal da ponte.
bool comSinal = false;
unsigned long ultimaMensagem = 0;   // instante da última mensagem válida

// "Esta linha do LCD precisa ser redesenhada?" Uma bandeira por linha.
bool redesenharAltitude = true;
bool redesenharSas = true;
bool redesenharSinal = true;
unsigned long ultimoDesenho = 0;

// Linha da serial sendo montada (igual ao passo 3).
const uint8_t TAMANHO_LINHA = 32;
char linha[TAMANHO_LINHA];
uint8_t tamanhoLinha = 0;
bool linhaGrandeDemais = false;

// O objeto que conversa com o LCD pelo I2C.
LiquidCrystal_I2C lcd(LCD_ENDERECO, LCD_COLUNAS, LCD_LINHAS);

// ======================================================= botões e chaves =====

// Mesmo debounce do passo 2, agora para cada item da tabela. O painel só
// avisa o que mudou; quem decide o que fazer é a ponte.
void lerEntrada(uint8_t i) {
  bool leitura = digitalRead(ENTRADAS[i].pino);
  if (leitura != entradaUltimaLeitura[i]) {
    entradaUltimaLeitura[i] = leitura;
    entradaInstanteMudanca[i] = millis();
  }
  if (leitura != entradaEstavel[i] && millis() - entradaInstanteMudanca[i] >= DEBOUNCE_MS) {
    entradaEstavel[i] = leitura;
    // Ex.: "SW GEAR 1". Pull-up: contato fechado = LOW = 1.
    Serial.print(ENTRADAS[i].tipo);
    Serial.print(' ');
    Serial.print(ENTRADAS[i].nome);
    Serial.println(leitura == LOW ? F(" 1") : F(" 0"));
  }
}

void lerEntradas() {
  for (uint8_t i = 0; i < NUM_ENTRADAS; i++) {
    lerEntrada(i);
  }
}

// ================================================================== LEDs =====
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

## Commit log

2026-09-25 Adiciona README com arquitetura, roteiro e lista de compras
    Define a arquitetura do cockpit (KSP + kRPC ⇄ ponte em Python ⇄
    serial ⇄ firmware no Arduino Mega), o roteiro em fases com critérios
    de "pronto" e a lista de compras por fase.
    Claude-Session: https://claude.ai/code/session_01J53Z231Jw98x95WNjPavVj
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2026-09-25 Corrige o computador de bordo para Raspberry Pi 4
    Ajusta fonte (USB-C 5,1V 3A), adiciona dissipador/ventoinha e o cabo
    micro-HDMI na lista de compras, e atualiza a nota de desempenho.
    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
2026-09-26 Conclui a fase 0: script de altitude e guia do Raspberry Pi
    - bridge/fase0_altitude.py: recebe o IP do PC como argumento, espera a
    cena de voo em vez de falhar e explica os erros de conexão.
    - docs/setup-pi.md: passo a passo do Pi (cartão, SSH, venv, git) e do PC
    (kRPC em Any, rede Privada, firewall), com os problemas já encontrados.
    - README: marca a fase 0 como concluída e registra a rede Privada.
    Claude-Session: https://claude.ai/code/session_01PZ2Sb8fD9CxzYjBd3hLJTq
    [fase0_altitude.py]
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2026-09-26 Fase 2: chaves, ABORT e LEDs de estado direto nos pinos do Mega (#4)
    - painel.ino guiado por tabelas (ENTRADAS e LEDS): botões STAGE e ABORT,
    chaves de SAS, RCS, trem, luzes e freios, um LED por sistema
    - A posição da chave é o estado desejado; a posição inicial não é enviada,
    para ligar o painel nunca mudar nada no jogo sozinho
    - ponte.py: SW <nome> leva o sistema à posição da chave, BTN ABORT dispara o
    abort, e os cinco estados vão para o painel quando mudam e a cada 1 s
    - docs/fase2.md com pinagem, testes e problemas comuns; protocolo atualizado
    - README: fase 1 concluída, fase 2 em andamento, lista de compras em dia
    Claude-Session: https://claude.ai/code/session_01XM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
    [painel.ino, ponte.py]
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2026-09-26 Hardware: esquemas KiCad do módulo genérico e do backplane (#6)
    * Roteiro: editor de nós de manobra na fase 4 e EXEC na fase 5
    * Hardware: esquemas KiCad do módulo genérico e do backplane
    - hardware/modulo: placa igual para todas as seções do painel, com
    3 x 74HC165 (24 entradas com pull-up) e 2 x 74HC595 (16 saídas com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
    [backplane.kicad_sch, modulo.kicad_sch]
2026-09-26 Hardware: módulo pequeno (1 x 74HC165 + 1 x 74HC595) (#7)
    3 x 74HC165 (24 entradas com pull-up) e 2 x 74HC595 (16 saídas com
    resi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
    [modulo_grande.kicad_sch, modulo_pequeno.kicad_sch]
2026-09-26 Hardware: módulo médio (2 x 74HC165 + 2 x 74HC595) (#8)
    resis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
    [modulo_medio.kicad_sch]
2026-09-26 Hardware: etiqueta com chave DIP para o Mega reconhecer cada módulo (#9)
    3 x 74HC165 (24 entradas com pull-up) e 2 x 74HC595 (16 sa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
    [backplane.kicad_sch, modulo_grande.kicad_sch, modulo_medio.kicad_sch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]
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2026-09-27 Tela única no meio e teclas basculantes no editor de manobras (#26)
    Os módulos não têm tela própria: cada um tem uma página na tela
    multifunção, que a ponte abre quando o módulo é usado e fecha sozinha
    uns segundos depois. O editor de manobras perde o LCD, e as alavancas
    viram teclas basculantes com mola, como a do TIME WARP. O protocolo
    não muda: cada tecla continua com duas entradas e manda INC.
    Claude-Session: https://claude.ai/code/session_01KCYgnjJubFamNCpaJPNXK9
2026-09-27 Painel do editor de manobras: 150 x 150 mm, com um encoder para o delta-v (#27)
    * Tela única no meio e teclas basculantes no editor de manobras
    * Painel do editor de manobras: 150 x 150 mm, com um encoder para o delta-v
    O de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
2026-09-29 FBW: lei de caça (carga e rolagem pelo manche) e fim da oscilação em pitch (#41)
    O voo gravado mostrou o FBW lento e "interventor": o manche movia um ponto
    na navball a 8°/s e o avião ia até ele em 2,5 s, soltar o manche não parava
    a curva, empurrar mal descia (carga mínima de 0 g) e o nariz oscilava a
    1,5 Hz entre -2 g e +5 g (ganho de pitch alto para o atraso do kRPC).
    - Manche em pitch pede carga, de -1 g a 4 g; solto, 1 g corrigido pelo
    ângulo de subida.
    - Manche de lado pede velocidade de rolagem, até 90°/s; solto, a
    inclinação fica onde a rolagem parou, em qualquer ângulo.
    - Torção do manche soma ao leme; o leme gira o nariz junto na rolagem.
    - Sem trava de altitud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
2026-09-29 FBW: sem recuperação automática do estol; só o aviso, e nada liga sozinho (#42)
    * FBW: lei de caça (carga e rolagem pelo manche) e fim da oscilação em pitch
    - Torção do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
    [mfd.py]
2026-09-29 Avisos de voo por voz (GPWS) na ponte da tela, com a luz no painel (#43)
    - bridge/avisos.py: PULL UP, TERRAIN, SINK RATE, DON'T SINK, TOO LOW
    GEAR/TERRAIN, BANK ANGLE, OVERSPEED e as chamadas de altura no pouso,
    com prioridade e sem duas frases juntas; em qualquer nave voando na
    atmosfera, com ou sem o fbw.py.
    - Voz no Pi pelo espeak-ng (ou gravações em bridge/sons/), numa thread;
    mfd.py ganha --voz, --sem-voz e --testar-voz.
    - Linha GPWS <0|1|2> para o painel: GPWS âmbar ou PULL UP vermelha na
    página de botões. A tela não recebe a linha.
    - Telemetria com situação, trem e pressão dinâmica.
    - Testes (bridge/tests/test_avisos.py) e docs/avisos.md.
    Claude-Session: https://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
    [avisos.py, mfd.py, sistemas.py]
2026-09-29 PCB do módulo médio: placa de 100 × 86 mm roteada, com Gerbers (#44)
    - Placa de 2 camadas com furos M3 nos cantos, GND preenchido nas duas faces,
    trilhas de 0,3 mm nos sinais e 0,6 mm no +5V e GND. DRC sem erros e sem
    ligações faltando.
    - hardware/pcb/modulo_medio.py gera a placa a partir do esquema: posiciona,
    roteia com o Freerouting, preenche o GND, roda o DRC e refaz os Gerbers.
    - Gerbers e furação em hardware/modulo_medio/fabricacao/.
    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
    [modulo_medio.kicad_pcb, modulo_medio.kicad_sch]
2026-09-29 Módulo médio: 3 × 74HC595 e 12 jacks JST-XH para os korry
    - Esquema: U6 (74HC595) no fim da cadeia de saída, com R17–R24 (220 Ω)
    e C7; as barras J2–J5 viram 12 jacks JST-XH de 4 vias (K1 a K12:
    GND, IN(k-1), LED(2k-2), LED(2k-1)) e uma barra J2 com IN12–IN15.
    - PCB refeita em 100 × 100 mm: K1–K6 na borda de cima, K7–K12 na de
    baixo; DRC sem erros e sem ligações faltando; Gerbers novos.
    - Documentação: tabelas do módulo médio, ordem dos bytes (3 de saída),
    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
    [modulo_medio.kicad_pcb, modulo_medio.kicad_sch]
2026-09-29 Módulo médio: 3 × 74HC595 e 12 jacks JST-XH para os korry (#45)
    lista de peças e a ficha do korry com os jacks.
    Claude-Session: https://claude.ai/code/session_01GYbCKeH4xeEesJ5HC66wNT
    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
    [modulo_medio.kicad_pcb, modulo_medio.kicad_sch]
2026-10-01 Cockpit versão B: painéis de 125 mm, sidestick e korry impresso (#47)
    O cockpit inteiro desenhado em U, com 766 × 391 mm: 11 painéis de
    125 mm (a tela, o voo e o editor em painéis duplos), o acelerador na
    asa esquerda e o sidestick JH-D400X-R4 na direita.
    - Desenhos: um arquivo por painel em hardware/desenho/paineis/, a vista
    de frente em cockpit.js e as peças novas em pecas.js. Os painéis de
    150 mm foram para desenho/antigos/ e img/antigos/.
    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
    [korry.scad, korry_base.stl, korry_preto.stl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]
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2026-10-02 Korry modular: legendas encaixáveis, chave PSW 8,5, suporte impresso e grade de fixação (#49)
    * Korry: modelo modular com legenda encaixável e chave PSW 8,5 no suporte impresso
    Claude-Session: https://claude.ai/code/session_01Bc6hVocvwM9BWvP5GsieHy
    * Korry: desenho da ligação do suporte no lugar da placa perfurada
    Claude-Session: https://claude.ai/code/session_01Bc6hVocvwM9BWvP5GsieHy
    * Korry: STL das quatro peças, imagens novas e corte colorido no modelo
    Claude-Session: https://claude.ai/code/session_01Bc6hVocvwM9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
    [antenas_preto.stl, antenas_transparente.stl, branco_preto.stl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]
2026-10-02 Korry: teste de folga com encaixes de 0,35 a 0,6 mm (#50)
    O primeiro teste, de 0,1 a 0,3 mm, ficou apertado em todos os encaixes.
    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
    [korry.scad, korry_teste.stl]
2026-10-02 Korry: folga de 0,5 mm, com o korry diminuindo para 21,9 mm (#51)
    * Korry: teste de folga com encaixes de 0,35 a 0,6 mm
    * Korry: folga de 0,5 mm, com o korry diminuindo para 21,9 mm
    A base e as grades continuam do mesmo tamanho, então o passo de 25,5 mm
    entre korry e os desenhos dos painéis não mudam.
    ---------
    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
    [antenas_preto.stl, antenas_transparente.stl, branco_preto.stl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]
2026-10-02 Painéis: botão de 16 mm com anel de 20 mm e LED de 5 mm no suporte com porca (#52)
    Os 36 botões de metal de 12 mm viram 34 botões de 16 mm sem trava
    (R16-503 / R13-507), com 23 mm entre centros, e os 7 LEDs de 3 mm com
    anel de metal viram LEDs de 5 mm no suporte de plástico com porca.
    - Action groups: 1 a 8, em duas fileiras de 4 (5 por fileira não cabem).
    - Tempo: o parafuso da grade do FISICO passa para baixo do korry, para
    caber o ATE O NO na mesma fileira.
    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
    [grade_eva.stl, grade_fisico.stl]
2026-10-03 Korry: legenda do RCS num 3MF de duas cores, para teste (#53)
    O gerar.py ganha o --3mf, que junta os dois STL de uma legenda (preto e
    transparente) num 3MF: um objeto com as duas partes no lugar, cada uma
    com a sua cor, para abrir de uma vez no fatiador. Por enquanto só o do
    RCS vai para o repositório, em hardware/korry/3mf/legenda_rcs.3mf.
    Claude-Session: https://claude.ai/code/session_01XSP9wYczWDaX1MgxXbH2Wg
    [legenda_rcs.3mf]
2026-10-20 Pi ligado no PC por cabo de rede direto, com a ponte da tela abrindo sozinha (#54)
    A ponte agora espera o KSP abrir e reconecta sozinha quando o jogo fecha e
    abre de novo, em vez de encerrar: conectar_krpc tenta a cada 5 s, avisando
    cada motivo uma vez, e manter_krpc fecha a conexão que caiu e espera o jogo
    de novo. Vale para a ponte do painel (ponte.py) e para a da tela (mfd.py),
    que agora abre a tela antes do kRPC. Testes em bridge/tests/test_ponte.py.
    O serviço do systemd em bridge/servico/ abre a ponte da tela quando o Pi
    liga, com os argumentos num arquivo de configuração.
    No docs/setup-pi.md, o cabo direto (IPs fixos, nmtui, a regra do firewall
    só para o Pi, como achar o Pi), o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
2026-10-22 Tela: desenho da SUBIDA suave mesmo com os engasgos da Wi-Fi do tablet (#74)
    A Wi-Fi do tablet segura os dados por até ~330 ms e entrega tudo de uma vez
    (medido: ping de 8 ms com picos de 334 ms; a ponte manda só 2,4 KB/s). O
    foguete parava e depois pulava. Agora, entre um pacote e outro, a página
    continua a altitude, a anomalia, o apoastro e o periastro com a velocidade
    que vinham tendo (por até 0,5 s) e corrige em 150 ms quando o dado chega.
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
